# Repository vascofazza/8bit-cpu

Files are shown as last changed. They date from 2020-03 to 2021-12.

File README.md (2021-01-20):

# MK1 8bit Computer

Schematics and code for my home-made 8-bit CPU and its companion boards.

Articles about this project:

[Hackaday.com](https://hackaday.com/2020/12/31/diy-8-bit-computer-knows-all-the-tricks/)

[Hackster.io](https://www.hackster.io/news/see-inside-of-a-cpu-with-the-mk1-8bit-computer-14fa9e313c73)

[InformaticaLab.com](https://blog.informaticalab.com/viaggio-allinterno-di-una-cpu-con-il-mk1-8bit-computer/)

## Overview

During the past month, I designed and built a programmable 8-bit CPU from scratch, out of basic series 74LS logic ICs.

This repository contains pictures, schematics, and code for this project and its companion boards.

* V 1.0 assembled:

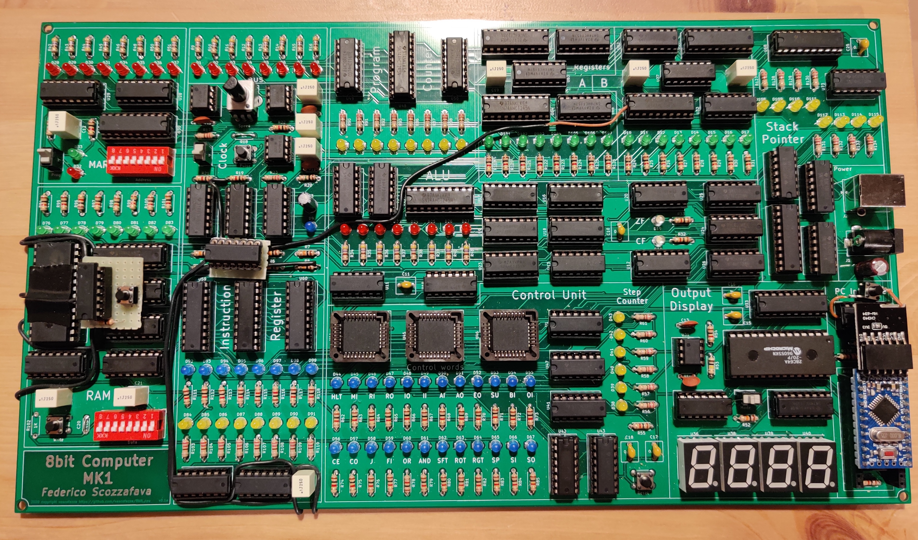
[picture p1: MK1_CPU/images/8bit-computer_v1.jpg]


* V 2.0b assembled:

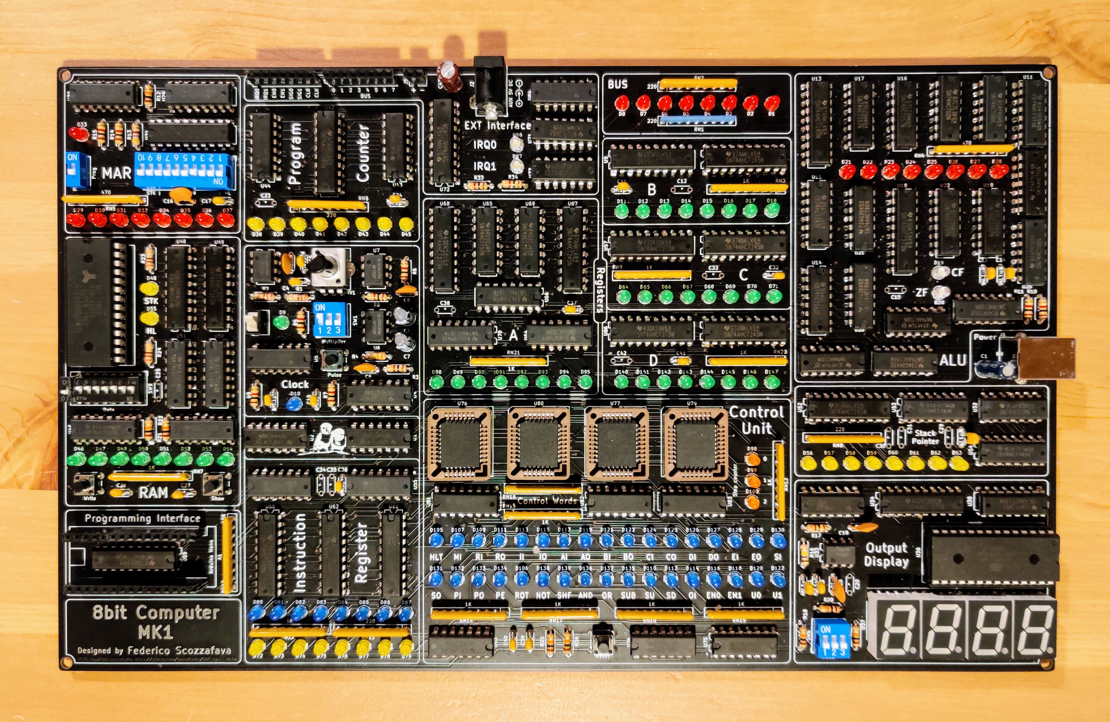
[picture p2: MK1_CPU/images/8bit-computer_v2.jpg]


- Helix Display Interface in action:



* V 1.0 in action:

**DEMO VIDEO (YouTube)**

MK1 Computer - home-made Programmable 8bit CPU (https://www.youtube.com/watch?v=qSviFkpLFKI)

## Architecture

The MK1 CPU is composed of several modules, all connected trough a common 8-bit BUS, the status of each module is shown by dedicated LEDs. 

- The clock module is designed to allow step-by-step execution; in automatic mode the clock speed can be adjusted from 1Hz up to 32KHz.
- The computer programs are stored in RAM and the CPU can be programmed both manually, by inserting binary machine code through dip-switches, and automatically via a USB PC interface. 
  - The Programming interface is designed to be used in conjunction with an **Arduino Nano** or the **Start9** programming board.
  - The **Start9** programming board allows the loading of multiple programs stored on an on-board flash memory without the aid of an external computer device.
- The Addressable memory space is 1024 byte, data, stack and code spaces are separated, the code address space is not writable. 
- The instructions are variable-length (see **instruction-set [here](https://github.com/vascofazza/8bit-cpu/tree/master/MK1_CPU/programs/lib/mk1.cpu)**) 1 or 2 bytes long (first byte for the opcode, the second one for the argument), there are 4 general purpose registers (`A`, `B`, `C`, `D`) and a  `stack pointer` register for subroutine calls.
- The **A**rithmetic **L**ogic **U**nit has a dedicated register for the second operand and supports the following operations:
  - Addition
  - Subtraction
  - OR
  - AND
  - NOT
  - Left/Right Shift
  - Left/Right Rotation
- The Control Unit combinatory logic is implemented using EEPROMs (see **microcode [here](https://github.com/vascofazza/8bit-cpu/blob/master/MK1_CPU/code/microcode.txt)**) whilst each instruction is realized through a variable number of micro-instruction for a maximum of 6 micro-steps per instruction, including the fetch cycle. The instruction-set  supports both direct and indirect memory access as well as absolute and conditional jumps on carry (`CF`) and zero (`ZF`) ALU flags.
- The computation output can be visualized on a 4-digit display, with a dedicated register, able to represent positive and 2-complement negative numbers both in decimal and hexadecimal format.
- The CPU can be extended thanks to the external BUS interface capable of handling up to 2 peripheral. The communication is bidirectional, the devices can send interrupts to the CPU to notify when new data is available. Interrupts are cleared once the data has been processed.
  - The only available peripheral at the moment is the **Helix** display interface, an ATmega328-driven 2x16 LCD output display.

## Structure

- **MK1 CPU/**:
  - **8bit-computer/**: KiCad project, schematics and PCB design of the **MK1 CPU**.
  - **code/**:
    - microcode.py: generates the binary EEPROM microcode.
    - out_display.py: generates the binary output display EEPROM code.
    - uploader.py: uploads a binary MK1 program to the CPU.
    - mk1_computer_uploader/: Arduino programmer interface sketch.
  - **assembler/**: fork of the hlorenzi's assembler, improved and customized for the MK1
  - **programs/**: a collection of programs for the MK1 CPU plus the assembler definition
- **start9_programming_interface/**: 
  - **programming_interface/**: KiCad project, schematics and PCB design of the **Start9** programming board.
  - **code/start9_programming_interface/**: Arduino code for the programming interface.
- **helix_display_interface/**:
  - **display_interface/**: KiCad project, schematics and PCB design of the **Helix** display interface board.
  - **code/helix_display_interface/**: Arduino code for the display interface.
- **eeprom_programmer/**: KiCad project, schematics and PCB design of a simple Arduino-based eeprom programmer
- **bus_breakout/**: KiCad project, schematics and PCB design of the external bus connector breakout board.

## Changelog

##### V2.0d:

- minor hardware revision
- revisited PCB design
- new memory architecture, code memory section is read-only, stack and data live on separated spaces

##### V2.0b:

- minor hardware revision
- Variable-length instructions (1 or 2 bytes)
- new custom assembler, thanks to https://github.com/hlorenzi/customasm
- few new instructions
- revisited microcode and instruction-set

##### V2.0:

- 4 general purposes registers (A, B, C, D)
- Stack Pointer implemented as an up-down counter
- External interface and interrupt handling
- Output display decodes HEX and ASCII values
- Clock speed multipliers
- Control Unit extended with 4 EEPROMs
- Variable step microcode counter length (each instruction uses the minimum amount of micro-steps)
- revisited microcode and instruction-set

##### V1.0:

- Bugfixes.
- `HL` and `STK` address signals available in the `MAR` dip-switch.

##### V0.1:

- Initial release

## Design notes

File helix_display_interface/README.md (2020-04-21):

# Helix Display Interface

An ATmega328-driven LCD Display peripheral for the MK1 8-bit CPU.

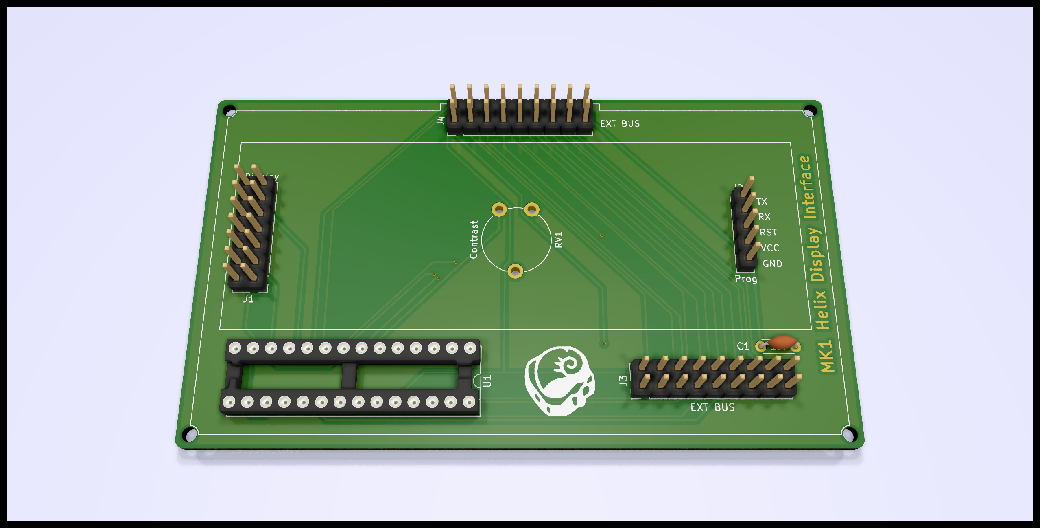
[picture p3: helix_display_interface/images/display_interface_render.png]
pcb_render


## Description

LCD character display interface for the MK1 CPU computer.

Uses an ATmega328P as driver and implements Integer and Character output mode.

Commands and data are both transmitted on the external bus.

There are two external bus connectors for peripheral daisy chaining.

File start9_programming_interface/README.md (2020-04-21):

# Start9 Programming Interface

An ATmega328-driven programming interface for the MK1 8-bit CPU.

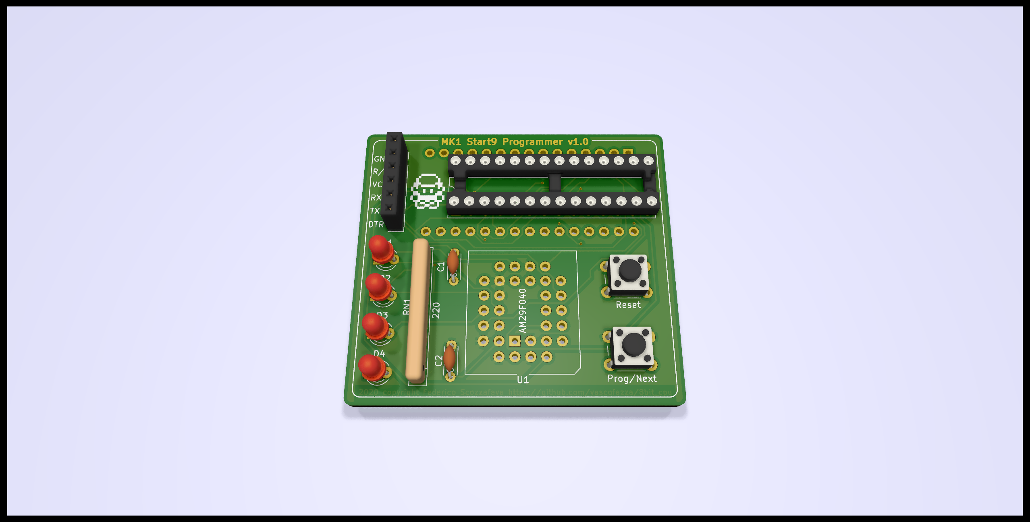
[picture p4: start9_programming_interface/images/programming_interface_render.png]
pcb_render


## Description

Writes a program, stored in a flash memory, into the working memory of the MK1 CPU.

Supports up to 16 program slots, the program/next button is used to select the bank and write the selected program.

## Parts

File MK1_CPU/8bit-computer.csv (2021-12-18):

Comment | Designator | Footprint | LCSC
Arduino Nano | A1 | Module:Arduino_Nano
0.1µF | C5,C10,C11,C12,C14,C15,C18,C22,C23,C25,C28,C29,C30,C34,C36,C37,C40,C41,C42 | Capacitor_THT:C_Disc_D4.3mm_W1.9mm_P5.00mm
* | C13,C16,C21,C26,C31,C32,C33,C35,C38,C43 | Capacitor_THT:C_Disc_D4.3mm_W1.9mm_P5.00mm
0.01 | C17 | Capacitor_THT:C_Disc_D4.3mm_W1.9mm_P5.00mm
10µF | C1,C2 | Capacitor_THT:CP_Radial_D5.0mm_P2.00mm
0.01µf | C24,C27,C44 | Capacitor_THT:C_Disc_D4.3mm_W1.9mm_P5.00mm
0.01µF | C3,C6,C7,C9,C19,C20,C39,C45 | Capacitor_THT:C_Disc_D4.3mm_W1.9mm_P5.00mm
1µF | C4,C8 | Capacitor_THT:CP_Radial_D5.0mm_P2.00mm
BLUE | D10,D72,D73,D74,D75,D76,D77,D78,D79,D93,D94,D95,D96,D97,D98,D99,D100,D101,D102,D103,D104,D105,D106,D107,D108,D109,D110,D111,D112,D113,D114,D115,D116,D117,D118,D119,D120,D121,D122,D123,D124,D125,D126 | LED_THT:LED_D3.0mm
WHITE | D19,D20,D88,D89 | LED_THT:LED_D3.0mm
YELLOW | D38,D39,D40,D41,D42,D43,D44,D45,D48,D55,D56,D57,D58,D59,D60,D61,D62,D63,D90,D91,D92 | LED_THT:LED_D3.0mm
RED | D1,D2,D3,D4,D5,D6,D7,D8,D21,D22,D23,D24,D25,D26,D27,D28,D29,D30,D31,D32,D33,D34,D35,D36,D37 | LED_THT:LED_D3.0mm
GREEN | D9,D11,D12,D13,D14,D15,D16,D17,D18,D46,D47,D49,D50,D51,D52,D53,D54,D64,D65,D66,D67,D68,D69,D70,D71,D80,D81,D82,D83,D84,D85,D86,D87,D127,D128,D129,D130,D131,D132,D133,D134 | LED_THT:LED_D3.0mm
USB_B-8bit-computer-rescue | J1 | Connector_USB:USB_B_OST_USB-B1HSxx_Horizontal
Barrel_Jack_Switch | J2 | Connector_BarrelJack:BarrelJack_Horizontal
EXT-CONN | J4 | Connector_PinHeader_2.54mm:PinHeader_2x09_P2.54mm_Vertical
Arduino_VIN | JP1 | Jumper:SolderJumper-2_P1.3mm_Bridged_RoundedPad1.0x1.5mm
220 | R1,R2,R23,R24 | Resistor_THT:R_Axial_DIN0207_L6.3mm_D2.5mm_P7.62mm_Horizontal
10K | R12,R18,R19,R20,R21,R22,R29,R30,R31,R32 | Resistor_THT:R_Axial_DIN0207_L6.3mm_D2.5mm_P7.62mm_Horizontal
470 | R13 | Resistor_THT:R_Axial_DIN0207_L6.3mm_D2.5mm_P7.62mm_Horizontal
100K | R16 | Resistor_THT:R_Axial_DIN0207_L6.3mm_D2.5mm_P7.62mm_Horizontal
1K | R3,R5,R6,R7,R8,R9,R10,R11,R14,R15,R17,R25,R26,R27,R28 | Resistor_THT:R_Axial_DIN0207_L6.3mm_D2.5mm_P7.62mm_Horizontal
330K | R4 | Resistor_THT:R_Axial_DIN0207_L6.3mm_D2.5mm_P7.62mm_Horizontal
10K | RN1 | Resistor_THT:R_Array_SIP9
470 | RN2,RN4,RN5 | Resistor_THT:R_Array_SIP9
1K | RN3,RN7,RN9,RN10,RN11,RN12,RN13,RN14,RN15,RN16,RN17,RN18,RN19,RN20 | Resistor_THT:R_Array_SIP9
220 | RN6,RN8 | Resistor_THT:R_Array_SIP9
1M | RV1 | Potentiometer_THT:Potentiometer_Bourns_PTV09A-1_Single_Vertical
Multiplier | SW1 | Button_Switch_THT:SW_DIP_SPSTx03_Slide_9.78x9.8mm_W7.62mm_P2.54mm
Reset | SW10 | Button_Switch_THT:SW_PUSH_6mm_H5mm
Pulse | SW2 | Button_Switch_THT:SW_PUSH_6mm_H5mm
Manual | SW3 | Button_Switch_THT:SW_NKK_GW12LJP
Prog | SW4 | Button_Switch_THT:SW_DIP_SPSTx01_Slide_9.78x4.72mm_W7.62mm_P2.54mm
Address | SW5 | Button_Switch_THT:SW_DIP_SPSTx10_Slide_9.78x27.58mm_W7.62mm_P2.54mm
Mode | SW6 | Button_Switch_THT:SW_DIP_SPSTx03_Slide_9.78x9.8mm_W7.62mm_P2.54mm
Write | SW7 | Button_Switch_THT:SW_PUSH_6mm_H5mm
Show | SW8 | Button_Switch_THT:SW_PUSH_6mm_H5mm
Data | SW9 | Button_Switch_THT:SW_DIP_SPSTx08_Slide_9.78x22.5mm_W7.62mm_P2.54mm
CLK_IN | TP1 | TestPoint:TestPoint_Pad_1.0x1.0mm
AND | TP10 | TestPoint:TestPoint_Pad_1.0x1.0mm
EI | TP11 | TestPoint:TestPoint_Pad_1.0x1.0mm
~EO | TP12 | TestPoint:TestPoint_Pad_1.0x1.0mm
NOT | TP13 | TestPoint:TestPoint_Pad_1.0x1.0mm
SUB | TP14 | TestPoint:TestPoint_Pad_1.0x1.0mm
MI | TP15 | TestPoint:TestPoint_Pad_1.0x1.0mm
OI | TP16 | TestPoint:TestPoint_Pad_1.0x1.0mm
~PO | TP17 | TestPoint:TestPoint_Pad_1.0x1.0mm
PE | TP18 | TestPoint:TestPoint_Pad_1.0x1.0mm
~PI | TP19 | TestPoint:TestPoint_Pad_1.0x1.0mm
CLK | TP2 | TestPoint:TestPoint_Pad_1.0x1.0mm
~RO | TP20 | TestPoint:TestPoint_Pad_1.0x1.0mm
RI | TP21 | TestPoint:TestPoint_Pad_1.0x1.0mm
~SO | TP22 | TestPoint:TestPoint_Pad_1.0x1.0mm
SU | TP23 | TestPoint:TestPoint_Pad_1.0x1.0mm
SD | TP24 | TestPoint:TestPoint_Pad_1.0x1.0mm
SI | TP25 | TestPoint:TestPoint_Pad_1.0x1.0mm
II | TP28 | TestPoint:TestPoint_Pad_1.0x1.0mm
AI | TP29 | TestPoint:TestPoint_Pad_1.0x1.0mm
~CLK | TP3 | TestPoint:TestPoint_Pad_1.0x1.0mm
~AO | TP30 | TestPoint:TestPoint_Pad_1.0x1.0mm
RGT | TP31 | TestPoint:TestPoint_Pad_1.0x1.0mm
ROT | TP32 | TestPoint:TestPoint_Pad_1.0x1.0mm
SHF | TP33 | TestPoint:TestPoint_Pad_1.0x1.0mm
E0 | TP34 | TestPoint:TestPoint_Pad_1.0x1.0mm
EXT_IN | TP35 | TestPoint:TestPoint_Pad_1.0x1.0mm
E1 | TP36 | TestPoint:TestPoint_Pad_1.0x1.0mm
U0 | TP37 | TestPoint:TestPoint_Pad_1.0x1.0mm
U1 | TP38 | TestPoint:TestPoint_Pad_1.0x1.0mm
~CU_EN | TP39 | TestPoint:TestPoint_Pad_1.0x1.0mm
~REG-O | TP4,TP26,TP40 | TestPoint:TestPoint_Pad_1.0x1.0mm
REG-I | TP5,TP27,TP41 | TestPoint:TestPoint_Pad_1.0x1.0mm
~FI | TP6 | TestPoint:TestPoint_Pad_1.0x1.0mm
ZF | TP7 | TestPoint:TestPoint_Pad_1.0x1.0mm
CF | TP8 | TestPoint:TestPoint_Pad_1.0x1.0mm
OR | TP9 | TestPoint:TestPoint_Pad_1.0x1.0mm
74HCT32 | U1,U2,U12,U25,U28 | Package_DIP:DIP-14_W7.62mm
74HCT173 | U11 | Package_DIP:DIP-16_W7.62mm
74HCT02 | U13,U69 | Package_DIP:DIP-14_W7.62mm
74HCT283 | U15,U16 | Package_DIP:DIP-16_W7.62mm
74HCT157 | U17,U18,U20,U23,U45,U62,U63,U67,U68 | Package_DIP:DIP-16_W7.62mm
74HCT86 | U21,U22,U24 | Package_DIP:DIP-14_W7.62mm
NE555 | U3,U6,U7,U33 | Package_DIP:DIP-8_W7.62mm
74LS157 | U30,U31,U50,U51 | Package_DIP:DIP-16_W7.62mm
74HCT107 | U35,U71 | Package_DIP:DIP-14_W7.62mm
28C64 | U36 | Package_DIP:DIP-28_W15.24mm_Socket
74HCT139 | U38 | Package_DIP:DIP-16_W7.62mm
74HCT04 | U4,U60 | Package_DIP:DIP-14_W7.62mm
7SEGMENT_CC | U37,U39,U40,U41 | Display_7Segment:7SegmentLED_LTS6760_LTS6780
74HCT161 | U43,U44,U72 | Package_DIP:DIP-16_W7.62mm
74HCT00 | U46,U55 | Package_DIP:DIP-14_W7.62mm
CY62256 | U47 | Package_DIP:DIP-28_W15.24mm_Socket
74HCT08 | U5,U10,U26,U27,U29,U58,U64 | Package_DIP:DIP-14_W7.62mm
74HCT193 | U53,U54 | Package_DIP:DIP-16_W7.62mm
AM29F040 | U73,U74,U75,U76 | Housings_LCC:PLCC-32_THT-Socket
74HCT138 | U77 | Package_DIP:DIP-16_W7.62mm
74HCT238 | U78,U79 | Package_DIP:DIP-16_W7.62mm
74HCT245 | U8,U14,U42,U48,U49,U52,U56,U59,U65,U70,U80 | Package_DIP:DIP-20_W7.62mm
74HCT273 | U9,U19,U32,U34,U57,U61,U66,U81 | Package_DIP:DIP-20_W7.62mm

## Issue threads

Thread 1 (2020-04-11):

Question: How did you get this manufactured?

efreethy, 2020-04-11:

vascofazza, 2020-04-11:
There are several PCB manufacturer companies, in my case I have a friend with all the necessary tools that manufactured it for me.

Closed 2020-04-12.

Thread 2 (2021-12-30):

Version control w/ example code and customasm syntax

HeathenUK, 2021-12-30:
Hi there,

As best I can tell there seem to have been some hugely backward-incompatible changes to customasm since the original (very well written!) examples were uploaded. I've tried and failed to port the definitions to the current expectations of customasm and failed, probably in equal parts due to my unfamiliarity with both customasm and the mk1's instructions. It's a pity, I was looking forward to making a pull request!

There seems to have been a shift away from 'cpudef' and 'tokendef' (although it looks like the parser still honours both so this is the least of all issues), the bankdef syntax no longer allows/requires quotation marks but even once that's fixed it throws panics due to the overlap in the two banks' respective locations. The thing I've totally failed to understand the root of - as your syntax looks identical to Lorenzi's to my eye - is casm's dislike of the way your registers and ALU opcodes are set out, and to every reference thereafter containing a $ sign.

Finally and somewhat bizarrely I can't even seem to find a historical build from ~2019 that likes the example code, so I'm not sure what's going on there either.

Regards,

Greg

vascofazza, 2022-01-02:
Hi Greg,

A PR would be more than welcome!
As you might have noticed, the version I used to build the example is a submodule of the repo, you can find it here: https://github.com/vascofazza/customasm/tree/0ab3ff3c4961ad814b904fe4824a65ae8b251672
You can also find the microcode here https://github.com/vascofazza/8bit-cpu/blob/master/MK1_CPU/code/microcode.txt
Where you can easily see what that 3'5 stands for and that should help you with the port.

Keep me posted!

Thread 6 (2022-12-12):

Problems with `ldi reg,0`

sparr, 2022-12-12:
I should preface this by saying that I haven't built your computer yet, but I want to, either in a simulator or on breadboards, and I prefer to dive into the repository and code before getting physical. So, I'm sorry if some (or, hopefully not, all) of my "will" and "should" below are inaccurate or off base.

`ldi {dst: reg} 0 => 0b11 @ 0b01 @ 0b00 @ dst[1:0]`

This seems to convert `ldi $a, 0` into `0b11 01 00 00` which microcode.txt tells me is equivalent to `sub $a, $a` instead of the `move 0, $a` that I would otherwise expect. While that instruction will produce the clearly desired effect of putting 0 into the a register, I think there are a few problems with this:

1. `sub` sets flags while `move` does not. That means `ldi $a, 0` will set the zero flag, but `ldi $a, 1` will not clear the zero flag. As a programmer, this is not behavior I would expect or desire.
2. `ldi $b, 0` is converted to `0b11 01 00 01` which is `sub $a, $b`. Should the third crumb `0b00` here be another `dst[1:0]` instead so that this will produce `0b11 01 01 01` or `sub $b, $b`?
3.  Both `sub reg, reg` and `move imm, reg` take 4 steps, so this optimization doesn't seem to gain anything, and it costs a bit of extra power for activating a lot more flags.
4. `dst[1:0]` truncates the dst parameter to 2 bits, so `ldi $sp, 0` is accepted by the assembler and produces identical machine code to `ldi $a, 0`, and ditto for `$pc`/`$b` and `$out`/`$c`. This line should include `{ assert(reg <= 4) ... }` or equivalent.
5. No example programs use this pattern for any register other than a. The test suite program doesn't use it at all. Every separate line in the assembler definition probably deserves at lease one test case.

I hope at least some of this makes sense and is helpful.

vascofazza, 2022-12-14:
I did not check carefully but I guess you are right about the flag being set due to `ldi $a 0` because of its implementation through the `sub` opcode.

There is actually a good reason why this is implemented this way. Therefore, I would say this is a design choice; the ALU flags should be considered valid only after a cmp or sub operation.
You could still reserve a whole set of opcodes for that operation and "solve" the issue this way.

1. That might indeed be true. I did not check the exact behavior anyway. refer to what is being said above.
2. The instructions are correct. All ALU ops first operand is always `$a`, therefore the syntax is `sub $a $x $dest` -> for any register the operation results in `$a - $a -> $dest`.
3. This is not actually true. `sub reg reg` is a 1-byte instruction, `move imm reg` is a 2-byte instruction, therefore it requires an extra fetch cycle to complete.
4. Again, I didn't check the details, this sounds a bit awkward. The microcode has all the possible combinations, in case there's an error feel free to open a PR :) The assertion seems safe. https://github.com/vascofazza/8bit-cpu/blob/master/MK1_CPU/code/microcode.txt
5. The original testing program was more exhaustive, I had to reduce it to make it fit in memory. A second test suite would make sense.

I hope this helps :)

sparr, 2022-12-14:
1. Thanks for the clarification. I suspect if I was going to continue less-fork-edly from your design I'd try to contribute a bit of documentation for that sort of thing. As it is I might not stay close enough for it to be relevant, but if I do then I will.
2. That makes perfect sense, and I suspect I'd have figured it out when I built the ALU to play with.
3. I completely forgot about the extra fetch cycle.
4. I found a better way than an assertion. I'll PR something like this after #5 is merged:

```customasm
#subruledef reg_gp
{
    $a   => 0
    $b   => 1
    $c   => 2
    $d   => 3
}

#subruledef reg_all
{
    {dst: reg_gp} => dst
    $sp  => 4
    $pc  => 5
    $out => 6
}
```

5. If I stay even close to instruction compatible with yours, I'll try to PR more tests.

I'll go ahead and close this since the major concerns aren't valid, and the fix for item 4 is going to touch a lot more than just this instruction anyway.

PS: I have a very unrealistic new concern... Implementing `ldi 0` differently from other `ldi imm` could expose cryptographic implementations on the cpu to timing attacks :)

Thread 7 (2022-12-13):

Opcodes that can be repurposed

sparr, 2022-12-13:
This is not a bug and not yet a feature request, more intended as discussion and preparation for expansion if the author or any other folks looking at this project want to collaborate on this part.

The existing code already fits `exr`, `exw`, `j*`, `cmp`, `not`, `sll`, `slr`, `rll`, `rlr`, `hlt`, and `add/sub/or/and imm` into some of the gaps where the larger opcode patterns would be meaningless or close. I am looking at the instruction set and opcode list and considering where more instructions can be squeezed in. Akin to my previous post, I apologize in advance if I've gotten anything wrong. I've started putting together the parts list to build a version of this computer, but it's going to be a while before I have hardware to play on.

Here are my notes:

`load $x [$out]` is already repurposed for `$a` and `$b`. The other 5 destination registers are ripe for the taking, at no cost.

`move $x $x` is a nop. It's so nop that `nop` maps to `move $a $a`, and so could all of them. Since `move imm, imm` is already reclaimed and we need to keep one to cover all of them, this would open up 6 opcodes at no cost.

`and/or $x $x` sets zf if $x is 0, clears cf. I think that `add 0 $x` would do the same, at the cost of 1 step. This would open up 8 opcodes.

`stor $x, [$pc]` is a quandary. The readme for the project says program memory (`HL`, bytes 0x100 to 0x1FF, I think?) isn't writable, but I don't see that implemented in the current schematic. If it works, it could only write to the next instruction to be executed, which seems of very limited use. I suspect this can be given up to gain 4 more opcodes.

`load $x, [$pc]` seems only slightly more useful. Reading only the next instruction from program memory might enable some specific clever trick, but I don't see it. I'd also give this up for 4 more opcodes.

`sub $x $x` sets $x to 0, sets zf, clears cf. I think that `cmp $x; ldi $x 0` does the same for `$b`/`$c`/`$d`, and `ldi $a 0; cmp 0` for `$a`, at the expense of one byte of code and 3 clock cycles. This would open up 3-4 opcodes.

That's about 20-30 opcodes available for additional instructions depending on priorities. I have ideas for what to do with them, but that's probably a subject for another discussion. Whether there's agreement or not on what to do with them, it would be useful to have some agreement on *which* existing opcodes to repurpose, for maximum compatibility between programs in the future. My preference would be to start at the top of this list.

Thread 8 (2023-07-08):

Helix Display LCD

TnnsBeast, 2023-07-08:
Could you provide the name of the LCD Display used with the Helix Display Interface? I am struggling to find one with the correct pin layout.

vascofazza, 2023-07-09:
Hi @TnnsBeast that is just a regular 16x2 LCD display with the Hitachi driver. The pinout layout is not the most common one but that's the only thing I had laying around.
You can find the pinout in the schematics
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
And the display is something similar to this, at least the pinout is the same https://www.digikey.com/en/products/detail/newhaven-display-intl/NHD-0216BZ-FL-YBW/1701195.
https://newhavendisplay.com/content/specs/NHD-0216BZ-FL-YBW.pdf

The easiest thing you can do is probably build an adapter between the two pin layouts, they are exactly the same except for the arrangement.
I just found the schematics here: https://www.cpmspectrepi.uk/raspberry_pi/MoinMoinExport/VariousDisplays.html

TnnsBeast, 2023-07-16:
Great, thank you!

Closed 2023-07-16.

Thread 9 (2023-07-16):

* on PCB Layout

TnnsBeast, 2023-07-16:
I am currently building the 2.0d, and I see some * on the PCB layout and BOM. What are these supposed to be?
Thanks!

vascofazza, 2023-07-20:
Those are optional (placeholder) 0.1uf caps I put there to compensate for possible impedance issues.
If you see instabilities or crosstalk you might consider putting a cap in there.

Closed 2023-07-20.

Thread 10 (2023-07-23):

Programming Interface

TnnsBeast, 2023-07-23:
Could you please explain how to program the programming interface? I am a little confused as to what the arduino code start9_programming_interface.ino and the flash_composer are meant to do. Also, how does flash composer communicate with the a pc? Sorry for so many questions, I am just trying to follow the build and need a little assistance. Thank you!

vascofazza, 2023-07-23:
The programming interface is used to program the MK1 using the `start9_programming_interface` board or directly from the computer through an Arduino serial interface.

1) The purpose of the Start9 programming interface is to store programs ad load them without having a computer laying around. On the board, an ATmega chip reads the programs from an EEPROM and loads them onto the CPU RAM.
The way this works is the following: first, you upload the `start9_programming_interface.ino` onto the atmega, then you use the `flash_composer` to create a single binary file that contains all the programs you want to store onto the programming interface.
This is an example:
- List of programs: https://github.com/vascofazza/8bit-cpu/blob/master/start9_programming_interface/code/start9.txt
- Output binary: https://github.com/vascofazza/8bit-cpu/blob/master/start9_programming_interface/code/start9.bin
Finally, flash the binary file on the EEPROM and enjoy :)

2) If you want to program the CPU from your computer directly, you only need an Arduino NANO, and this is the code you need to upload https://github.com/vascofazza/8bit-cpu/blob/master/MK1_CPU/code/mk1_computer_uplodader/mk1_computer_uplodader.ino
This way, you can upload the code through the serial port - Everything is already implemented in the `code` folder, you should find the uploader there.

I hope this is making things a little bit clearer :)

TnnsBeast, 2023-07-23:
Yes, this definitely makes sense. The main questions I have are how do you upload the start9_programming_interface.ino onto the atmega, and how do you flash the eeproms (the one on the programmer and the ones on control unit)? I have built the EEPROM Programmer, but from what I understand that is only able to write to the EEPROM used for the output display.

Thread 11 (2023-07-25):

Programming AM29F040

TnnsBeast, 2023-07-25:
Hi there, how did you go about programming the AM29F040 flash memory? I have built the eeprom programmer but from what I can tell that is setup to program the EEPROM handling the 7 segment leds. I am unable to find a good example of how to program the AM29F040 online. Your help is greatly appreciated!

TnnsBeast, 2023-08-05:
Hi, I have successfully built the eeprom programmer board and programmed the 7 segment driver. I am still struggling with the AM29F040 flash chips. I have spent many hours trying to build a programmer for it, but have not been successful. Could you please tell me how you program the AM29F040 chips which are used for control logic and programming interface. Without that I am unable to get this project working, and would really appreciate your help.

vascofazza, 2023-08-06:
@TnnsBeast I used a programmer.
You can try this one off https://github.com/warber0x/FMPUNO
Let me know!

Closed 2023-08-11.

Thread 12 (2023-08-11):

Unexpected Behavior (Clock, Reset, Programming Interface)

TnnsBeast, 2023-08-11:
Hi! I believe I have been able to successfully program the Flash as well as the ATMega for the programming interface, but I am unable to understand why I am getting the results I am currently. Here is a video of what I have so far: https://imgur.com/a/B3an2lI

As you can see in the video, one of the first issues is that the clock doesn't seem to work. When I try to switch it on, nothing seems to happen. The pulse button does work (sometimes).

The next issue is that the reset button for some reason doesn't clear the C register.

And finally, the programming interface doesn't do anything (from what I can tell), since none of the LEDs are lighting up indicating it is programming.

Do you think that these issues could all be caused by incorrect programming of the AM29F040Bs? I was able to use the FMPUno and it seemed that they were programmed correctly when I read the contents.

vascofazza, 2023-08-11:
Remove the programming interface and check the connections. Something is
shorting. Maybe once IC is mounted in reverse . The clock should always
work and the reset as well!

Il giorno ven 11 ago 2023 alle 18:13 Neil Chulani ***@***.***>
ha scritto:

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

vascofazza, 2023-08-11:
The eeproms could cause the issue as well but check the other ics first.

Il giorno ven 11 ago 2023 alle 23:20 Federico Scozzafava <
***@***.***> ha scritto:

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

TnnsBeast, 2023-08-12:
Thank you for your reply. I have checked all of the ICs and they seem to be the correct way, and I am fairly confident that my soldering is also clean. The only thing that I think could possibly be wrong is the direction of the switch used to turn the clock on/off, but even that I am fairly certain is the correct direction.

I will take a look into the eeproms, but do you think the eeproms could really be the reason for malfunctioning clock? I also agree that clock should be working no matter what, which is why I am confused.

Thank you again for your help.

vascofazza, 2023-08-12:
The clock can be disabled by the eeprom through the halt signal.
The behavior of the B register is quite strange and makes me think about
something mounted in reverse. Given that I don’t see anything on the bus
maybe the register is faulty.
Or even the eeproms are outputting random noise.
Anyway, you cannot test the computer without the eeproms because the
signals would be fluctuating.

Il giorno sab 12 ago 2023 alle 08:15 Neil Chulani ***@***.***>
ha scritto:

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

vascofazza, 2023-08-12:
The programming interface also messes up with the signals, so make sure you
remove it for now.

Il giorno sab 12 ago 2023 alle 13:19 Federico Scozzafava <
***@***.***> ha scritto:

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

TnnsBeast, 2023-08-14:
I am fairly sure that it had to do with the eeproms. Many of the control logic leds seem to be fluctuating and I am still unable to get the clock to work even with replacing all of the ICs. Could you please share the name of the programmer that you used, or perhaps recommend an official programmer?

vascofazza, 2023-08-14:
You’re probably right!
I used a random old programmer I had lying around. Any will do.
If you want to make the investment I suggest you to get the TL866 minipro

Il giorno lun 14 ago 2023 alle 20:09 Neil Chulani ***@***.***>
ha scritto:

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

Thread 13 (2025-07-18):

Instruction register in (II) problem

mafrmt00, 2025-07-18:
I really had fun building this project, thank you a lot for that!
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

While testing I came upon the following problem: The instruction register copies every value that comes from memory. If a pop is used, the value goes to the instruction register e.g. It does not matter if II is set.

It seems that my Flash (AM29J040B-90JD) has a very short undefined state on it's data pins while the address changes.

A 10nF capacitor between II and GND solves the problem at most speed settings.

To you have a suggestion for a specific flash type that does not show this behaviour?

Regards
Manfred

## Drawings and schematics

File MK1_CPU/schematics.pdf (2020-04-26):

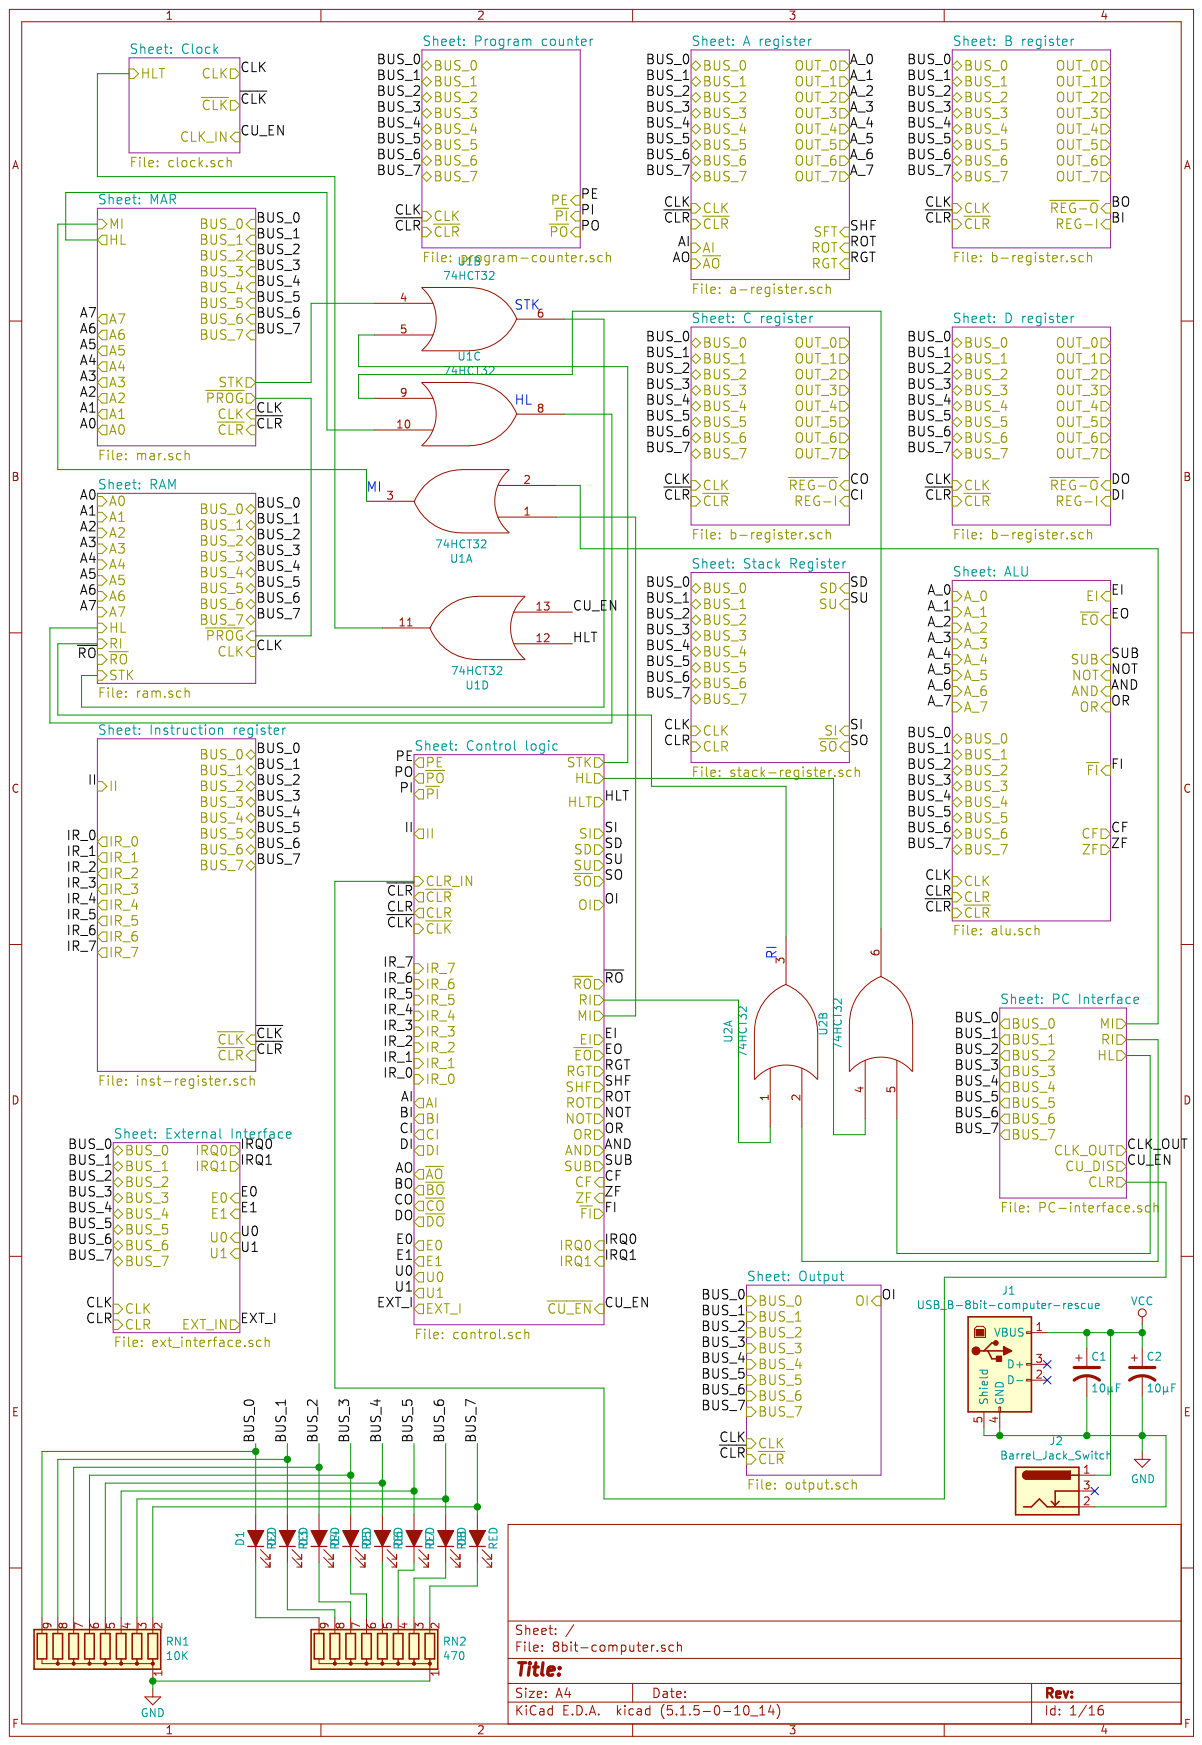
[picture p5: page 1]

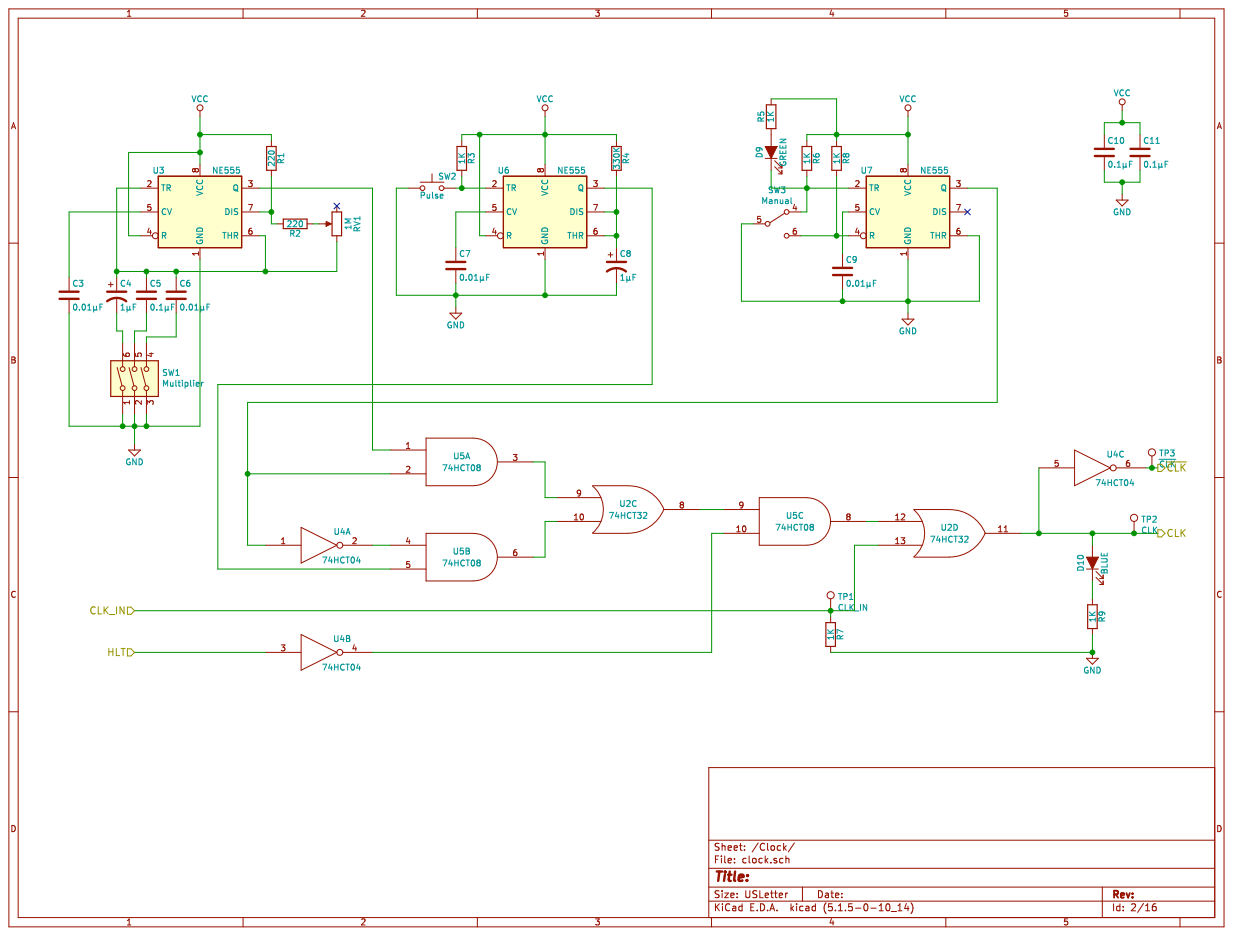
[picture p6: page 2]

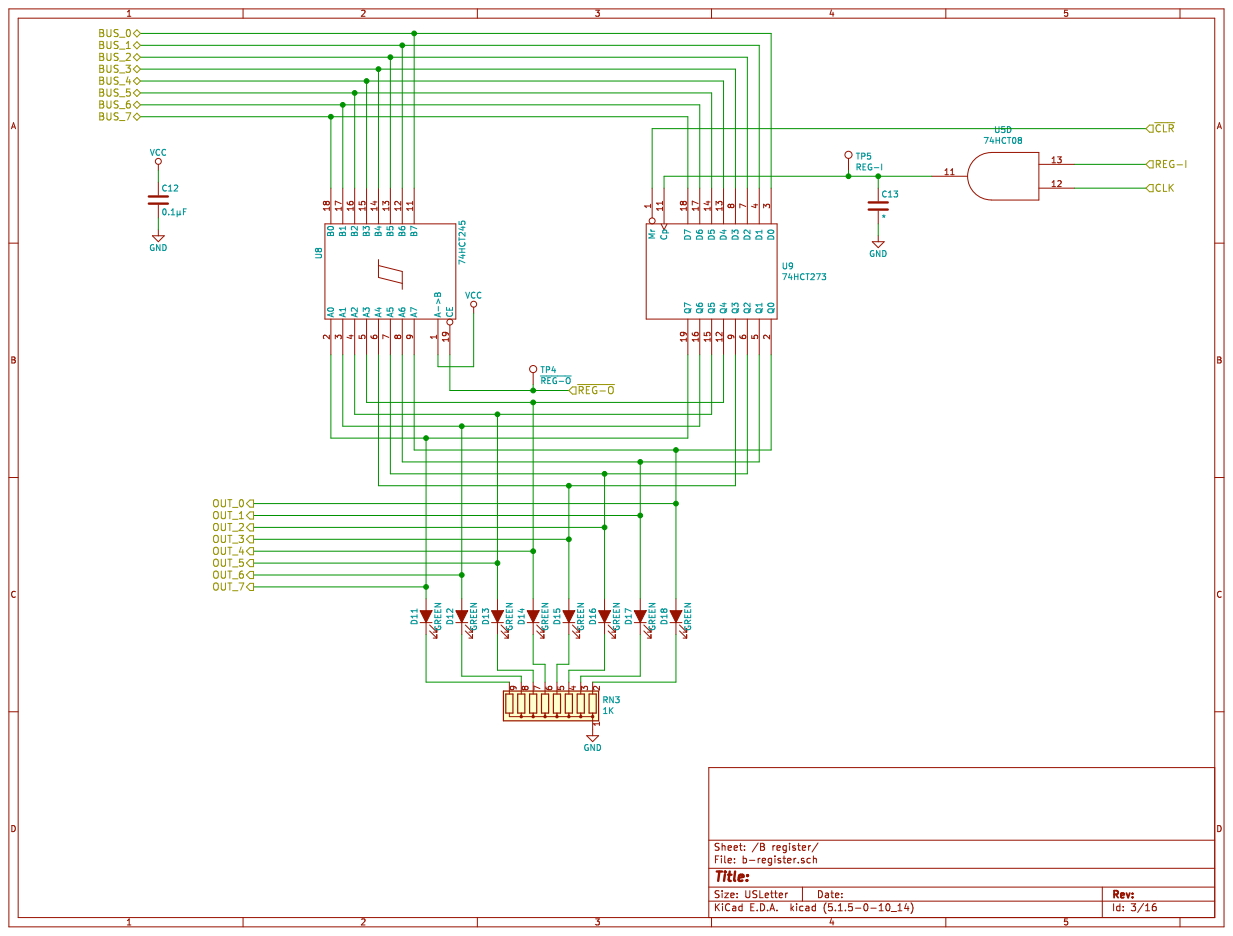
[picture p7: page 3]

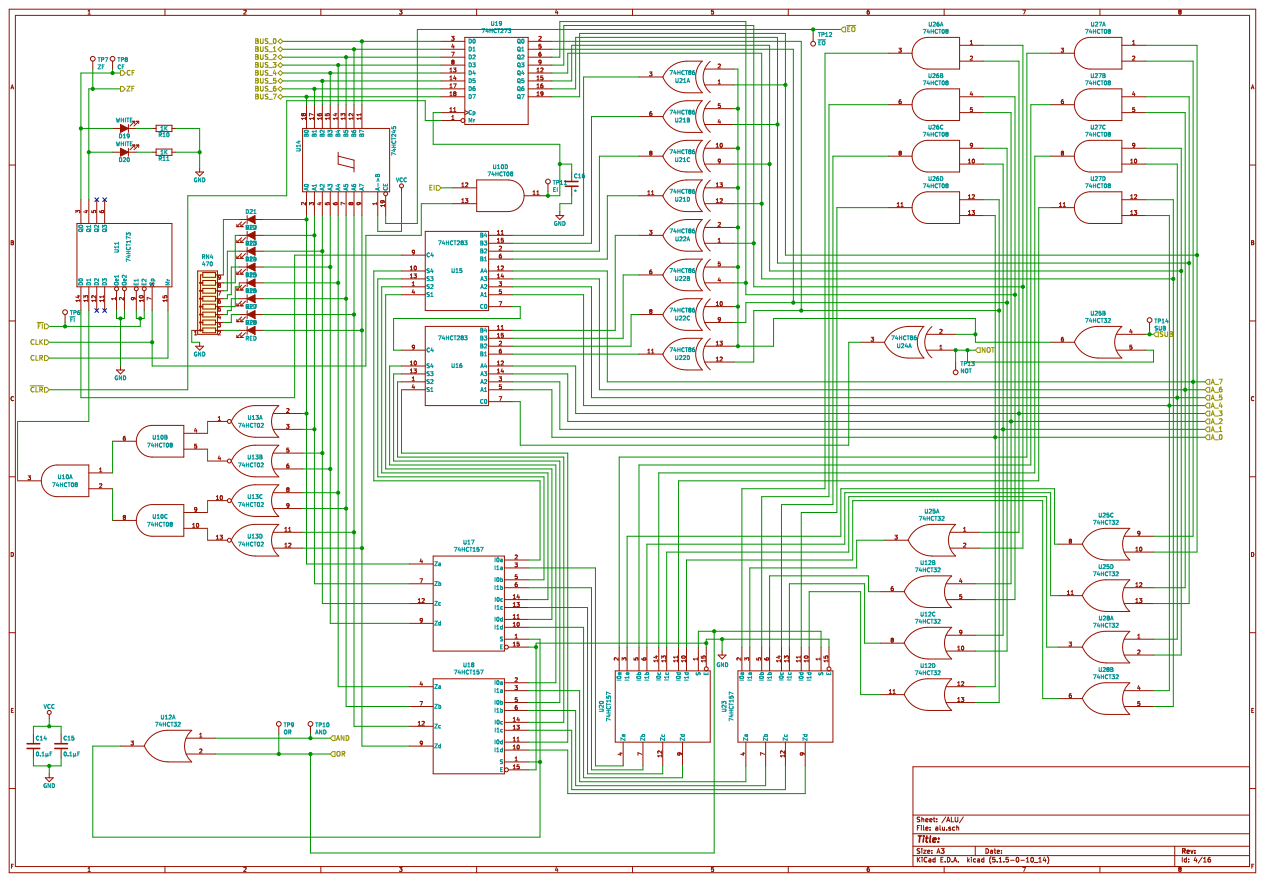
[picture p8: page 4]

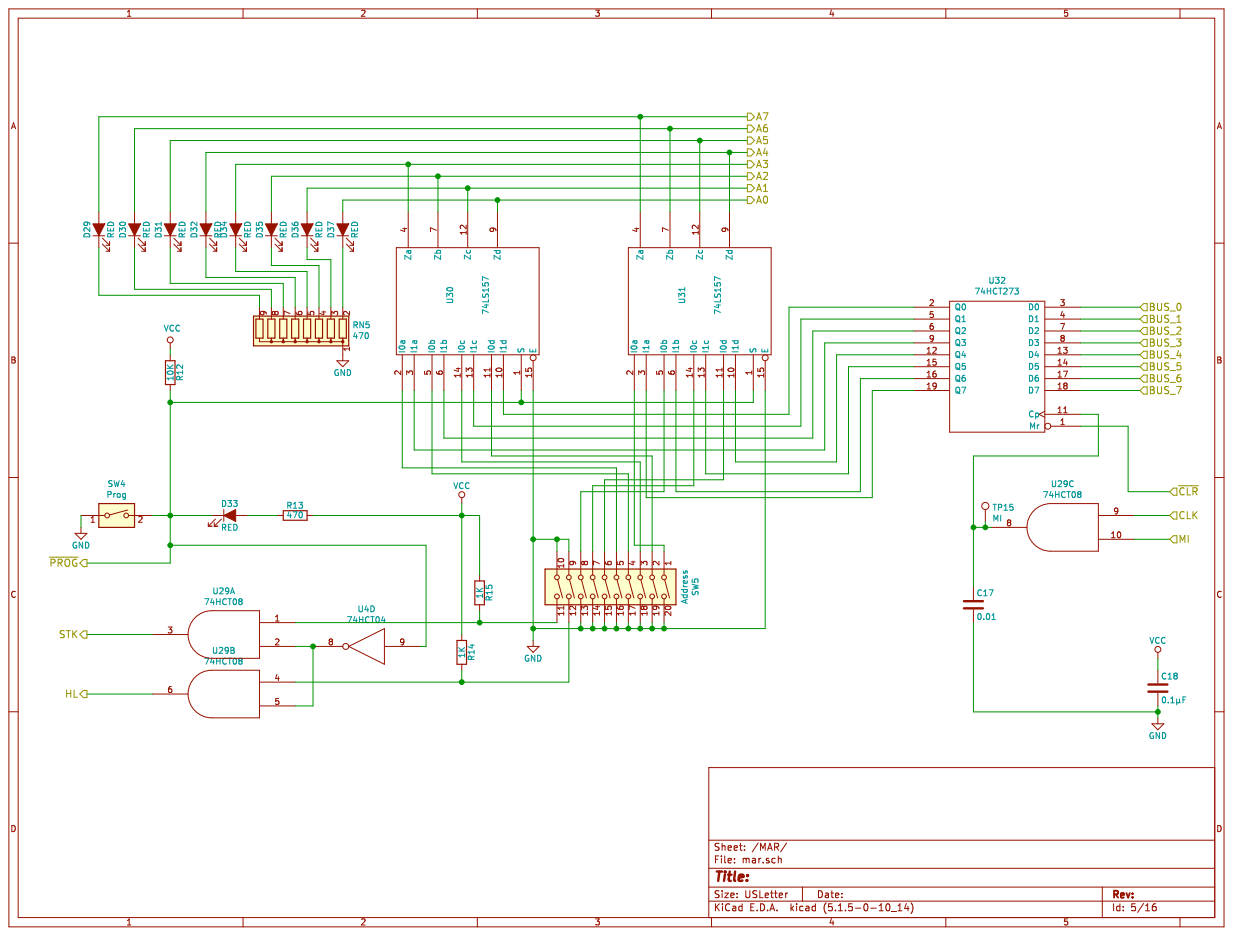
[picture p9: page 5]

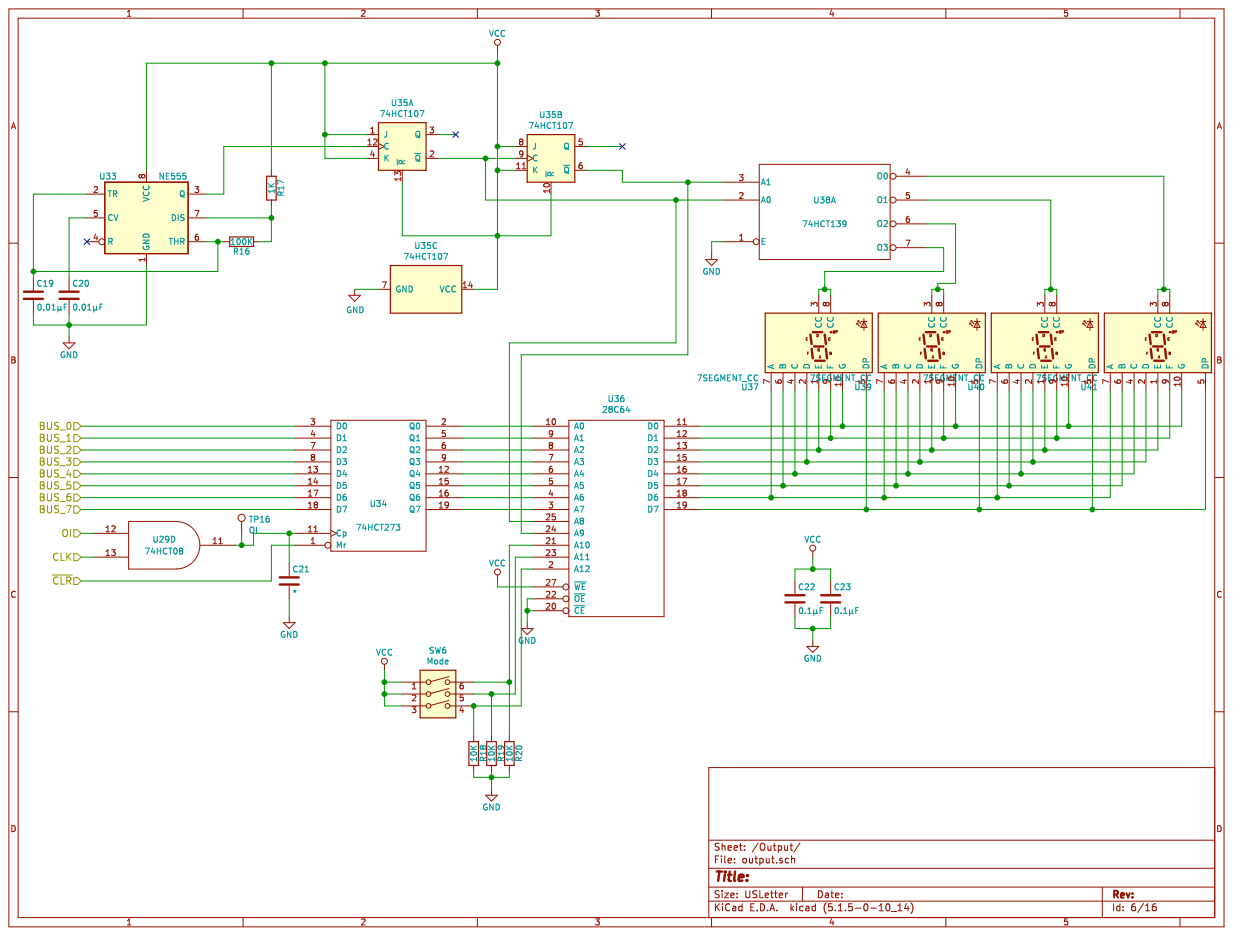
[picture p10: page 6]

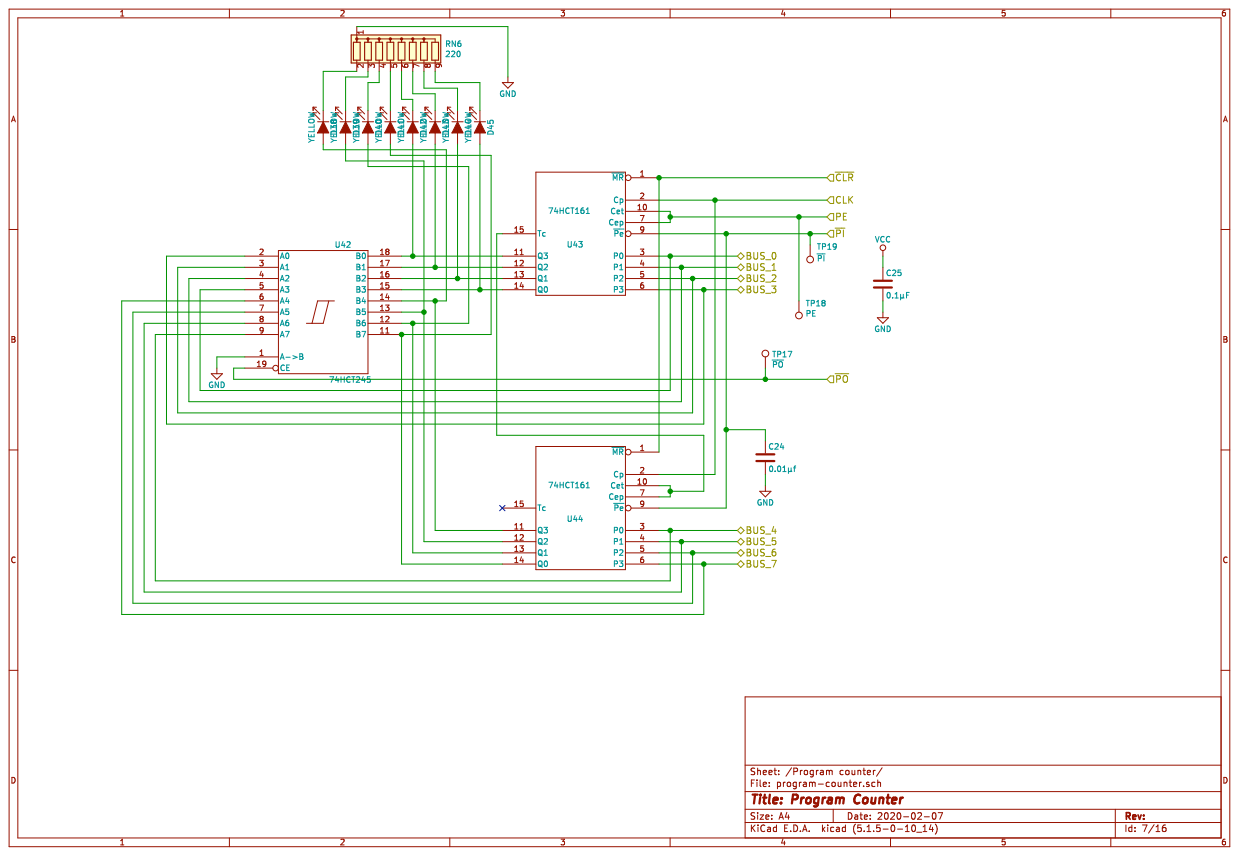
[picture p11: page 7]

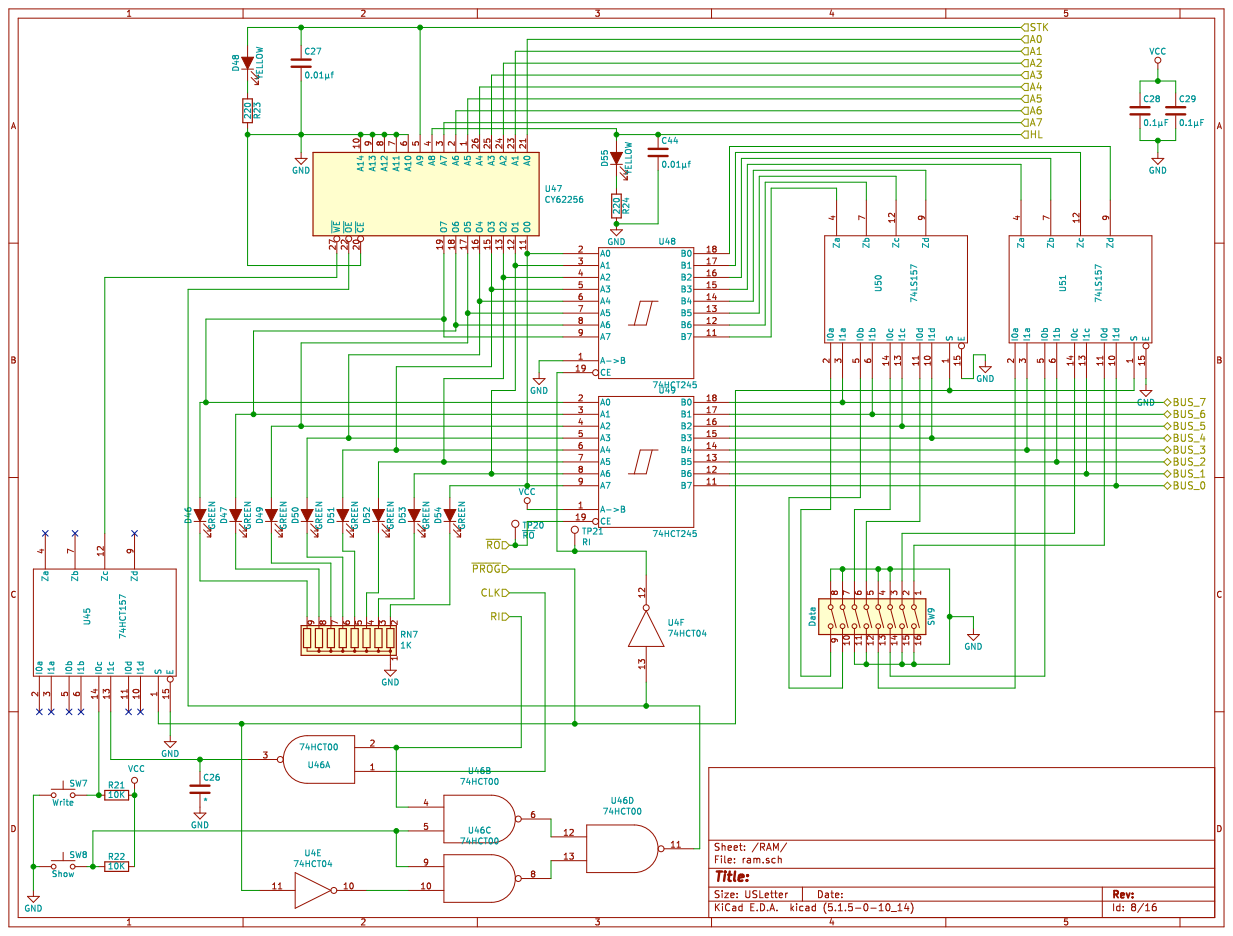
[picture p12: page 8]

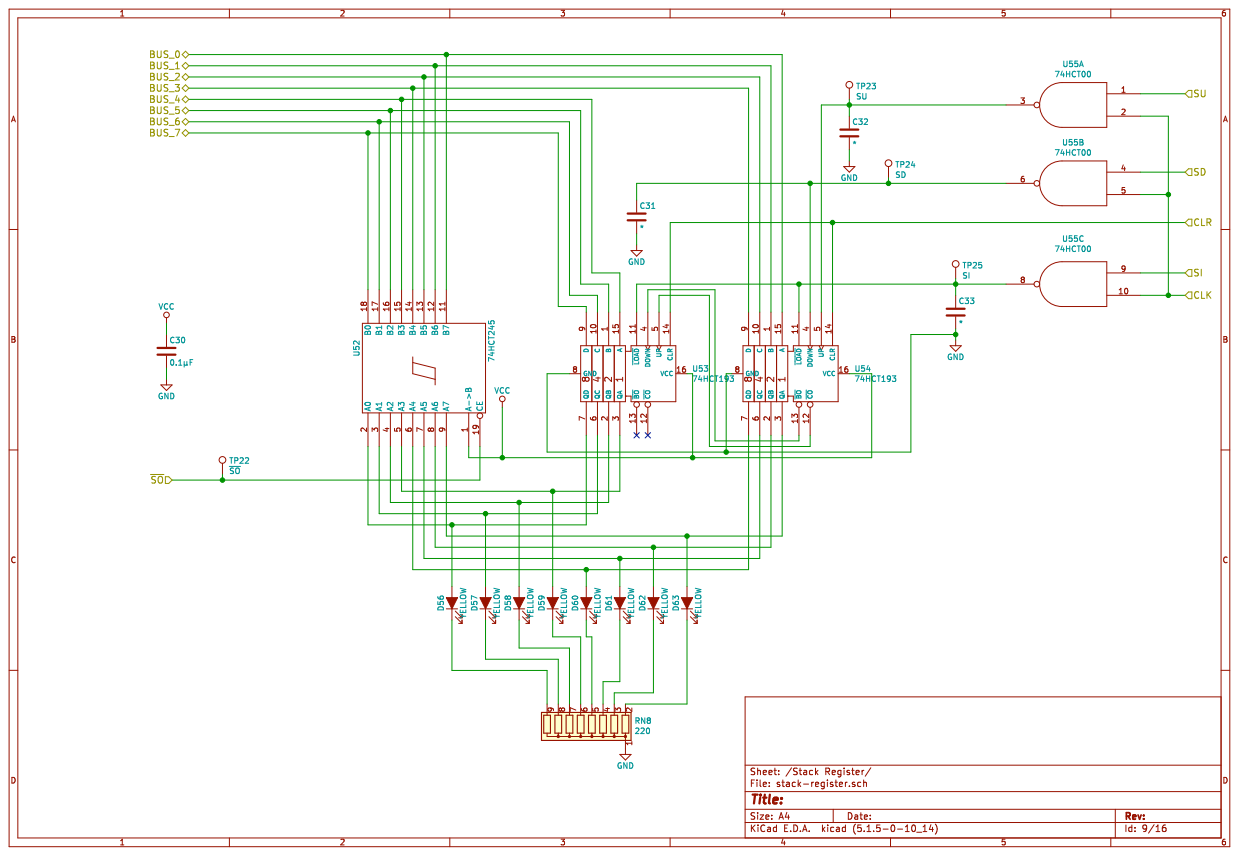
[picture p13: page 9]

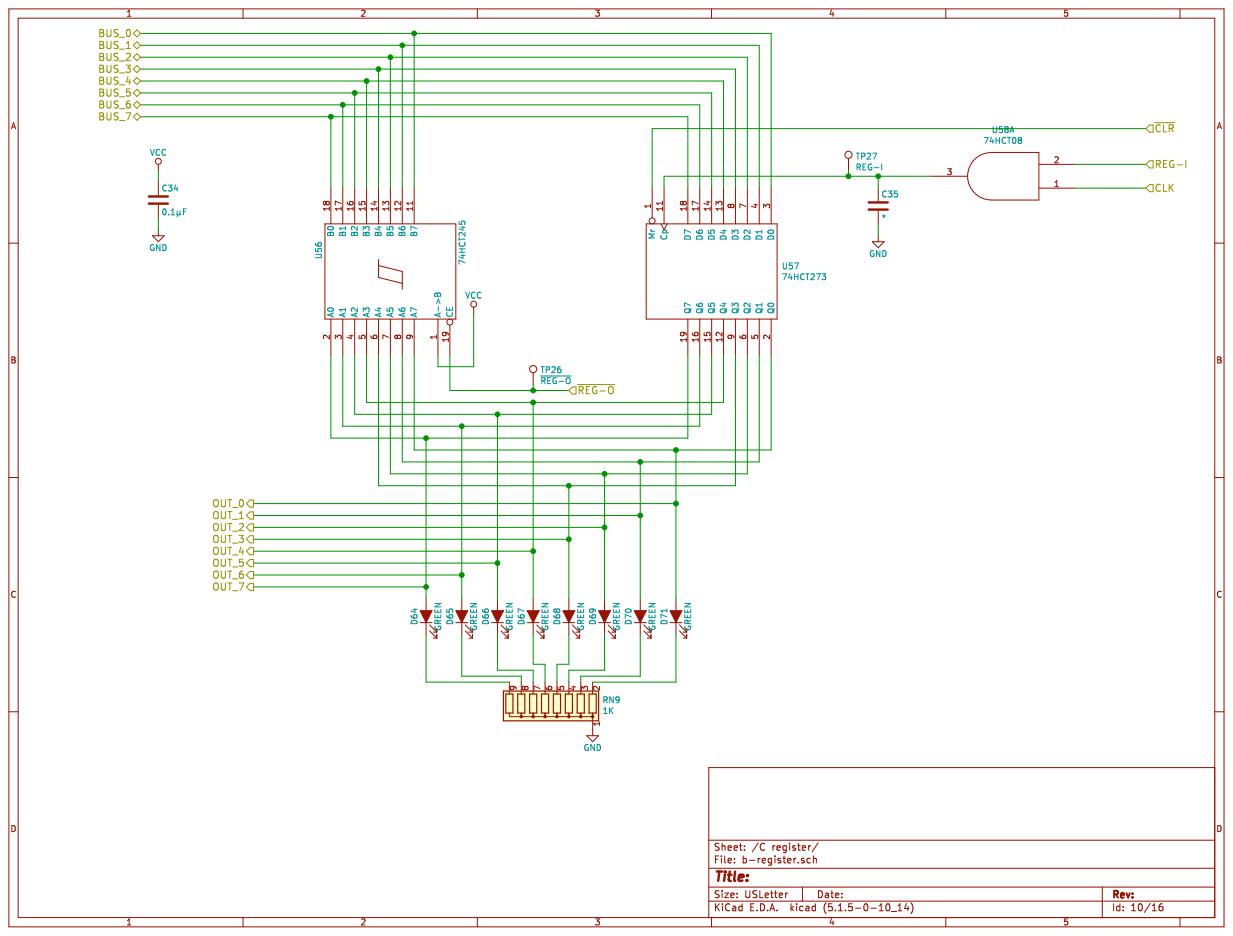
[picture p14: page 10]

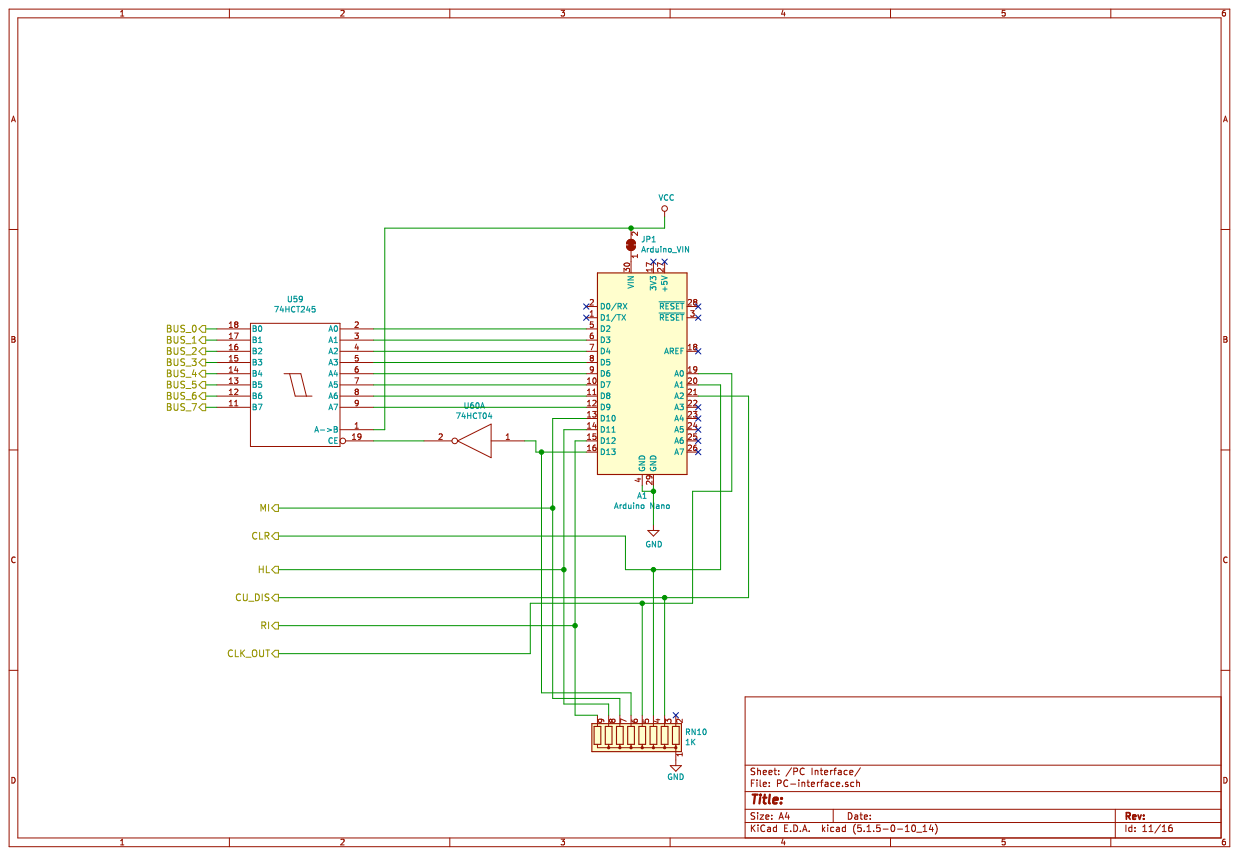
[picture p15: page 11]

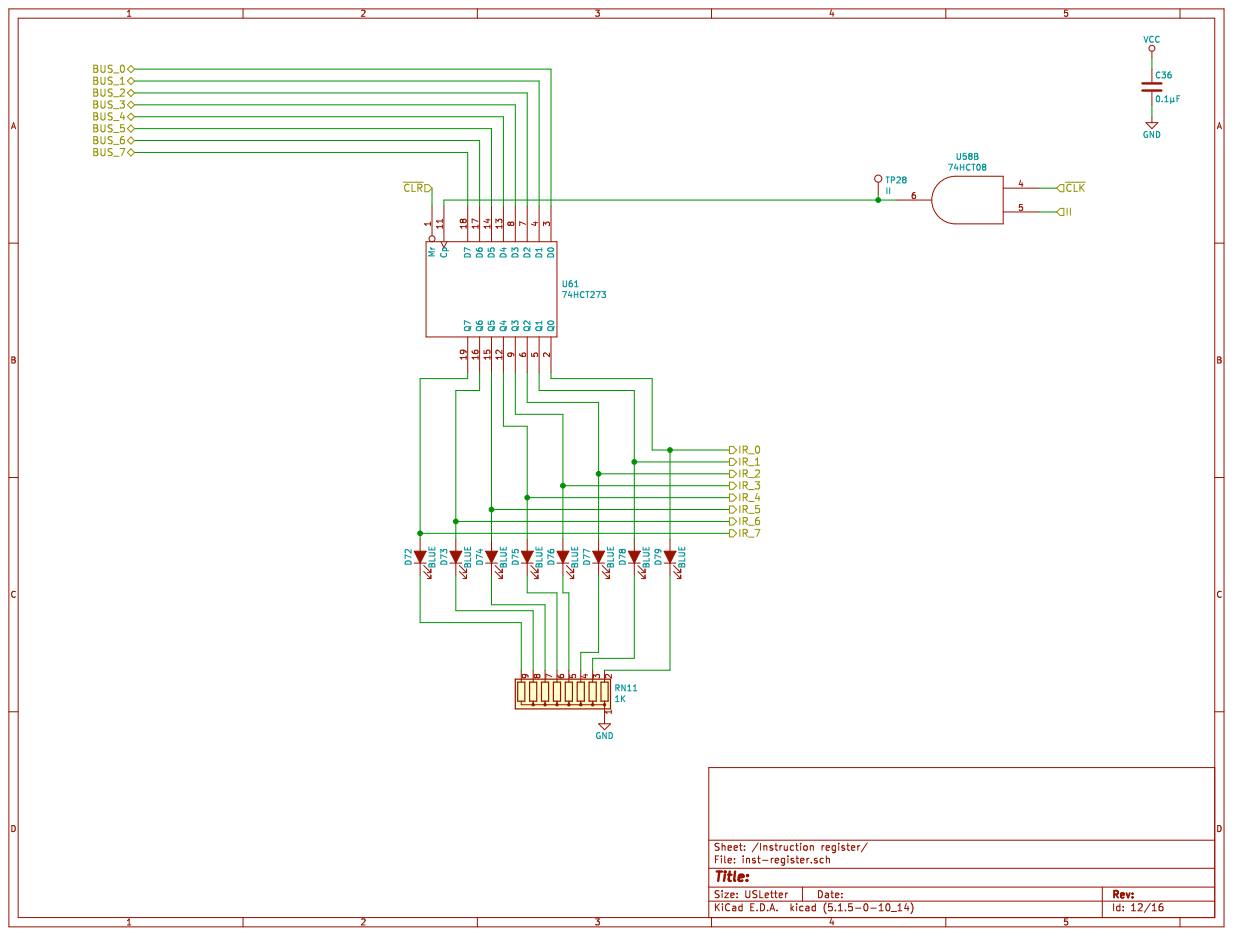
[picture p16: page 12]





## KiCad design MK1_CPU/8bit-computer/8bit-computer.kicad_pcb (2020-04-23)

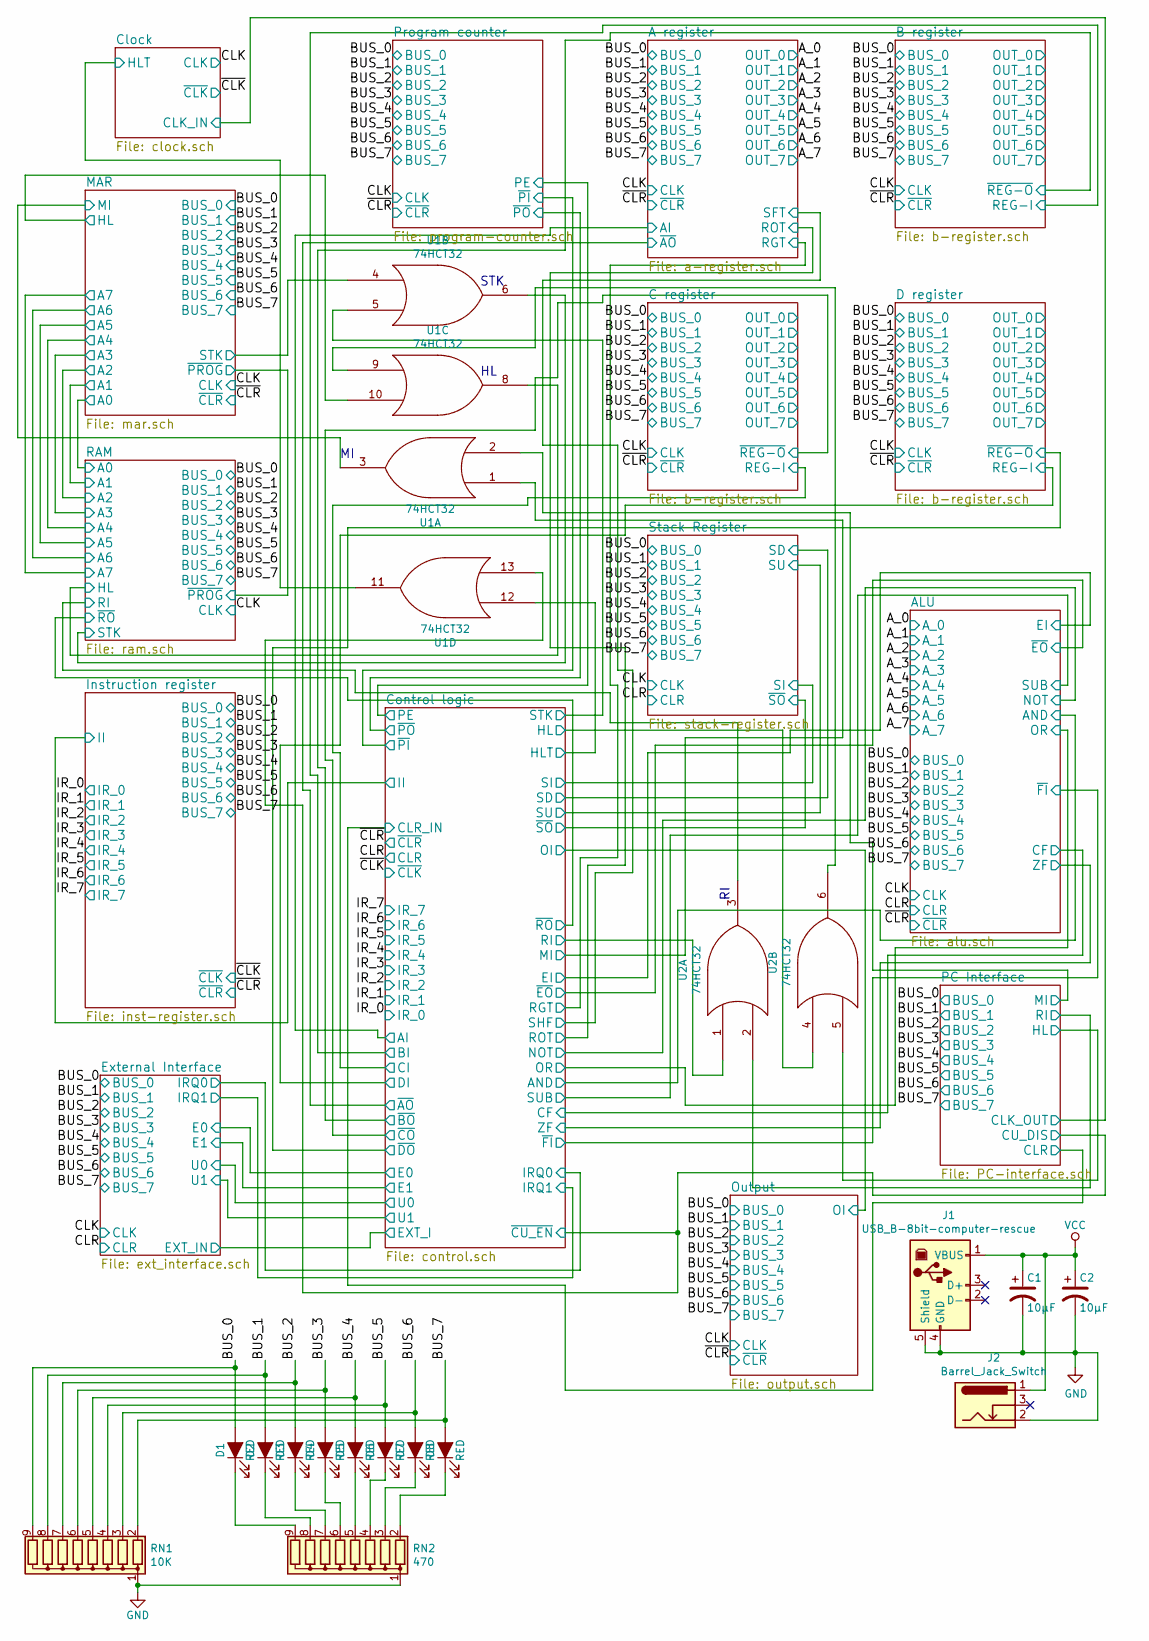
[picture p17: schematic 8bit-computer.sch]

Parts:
C1, C2: 10µF; CP_Radial_D5.0mm_P2.00mm
D1, D2, D3, D4, D5, D6, D7, D8: RED; LED_D3.0mm
J1: USB_B-8bit-computer-rescue; USB_B_OST_USB-B1HSxx_Horizontal
J2: Barrel_Jack_Switch; BarrelJack_Horizontal
RN1: 10K; R_Array_SIP9
RN2: 470; R_Array_SIP9
U1, U2: 74HCT32; DIP-14_W7.62mm

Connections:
/BUS_0: D1.2 (A), RN1.9 (R8); also elsewhere on the board
/BUS_1: D2.2 (A), RN1.8 (R7); also elsewhere on the board
/BUS_2: D3.2 (A), RN1.7 (R6); also elsewhere on the board
/BUS_3: D4.2 (A), RN1.6 (R5); also elsewhere on the board
/BUS_4: D5.2 (A), RN1.5 (R4); also elsewhere on the board
/BUS_5: D6.2 (A), RN1.4 (R3); also elsewhere on the board
/BUS_6: D7.2 (A), RN1.3 (R2); also elsewhere on the board
/BUS_7: D8.2 (A), RN1.2 (R1); also elsewhere on the board
/Clock/HLT: U1.11; also elsewhere on the board
/Control logic/HL: U2.4; also elsewhere on the board
/Control logic/HLT: U1.12; also elsewhere on the board
/Control logic/MI: U1.1; also elsewhere on the board
/Control logic/RI: U2.1; also elsewhere on the board
/Control logic/STK: U1.5; also elsewhere on the board
/MAR/HL: U1.10; also elsewhere on the board
/MAR/MI: U1.3; also elsewhere on the board
/MAR/STK: U1.4; also elsewhere on the board
/PC Interface/CU_DIS: U1.13; also elsewhere on the board
/PC Interface/HL: U2.5; also elsewhere on the board
/PC Interface/MI: U1.2; also elsewhere on the board
/PC Interface/RI: U2.2; also elsewhere on the board
/RAM/HL: U1.8; also elsewhere on the board
/RAM/RI: U2.3; also elsewhere on the board
/RAM/STK: U1.6; also elsewhere on the board
GND: C1.2, C2.2, J1.4 (GND), J1.5 (Shield), J2.2, RN1.1 (common), RN2.1 (common), U1.7 (GND), U2.7 (GND); also elsewhere on the board
unnamed: D1.1 (K), RN2.9 (R8)
unnamed: D2.1 (K), RN2.8 (R7)
unnamed: D3.1 (K), RN2.7 (R6)
unnamed: D4.1 (K), RN2.6 (R5)
unnamed: D5.1 (K), RN2.5 (R4)
unnamed: D6.1 (K), RN2.4 (R3)
unnamed: D7.1 (K), RN2.3 (R2)
unnamed: D8.1 (K), RN2.2 (R1)
unnamed: U1.9, U2.6
VCC: C1.1, C2.1, J1.1 (VBUS), J2.1, U1.14 (VCC), U2.14 (VCC); also elsewhere on the board

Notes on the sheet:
STK

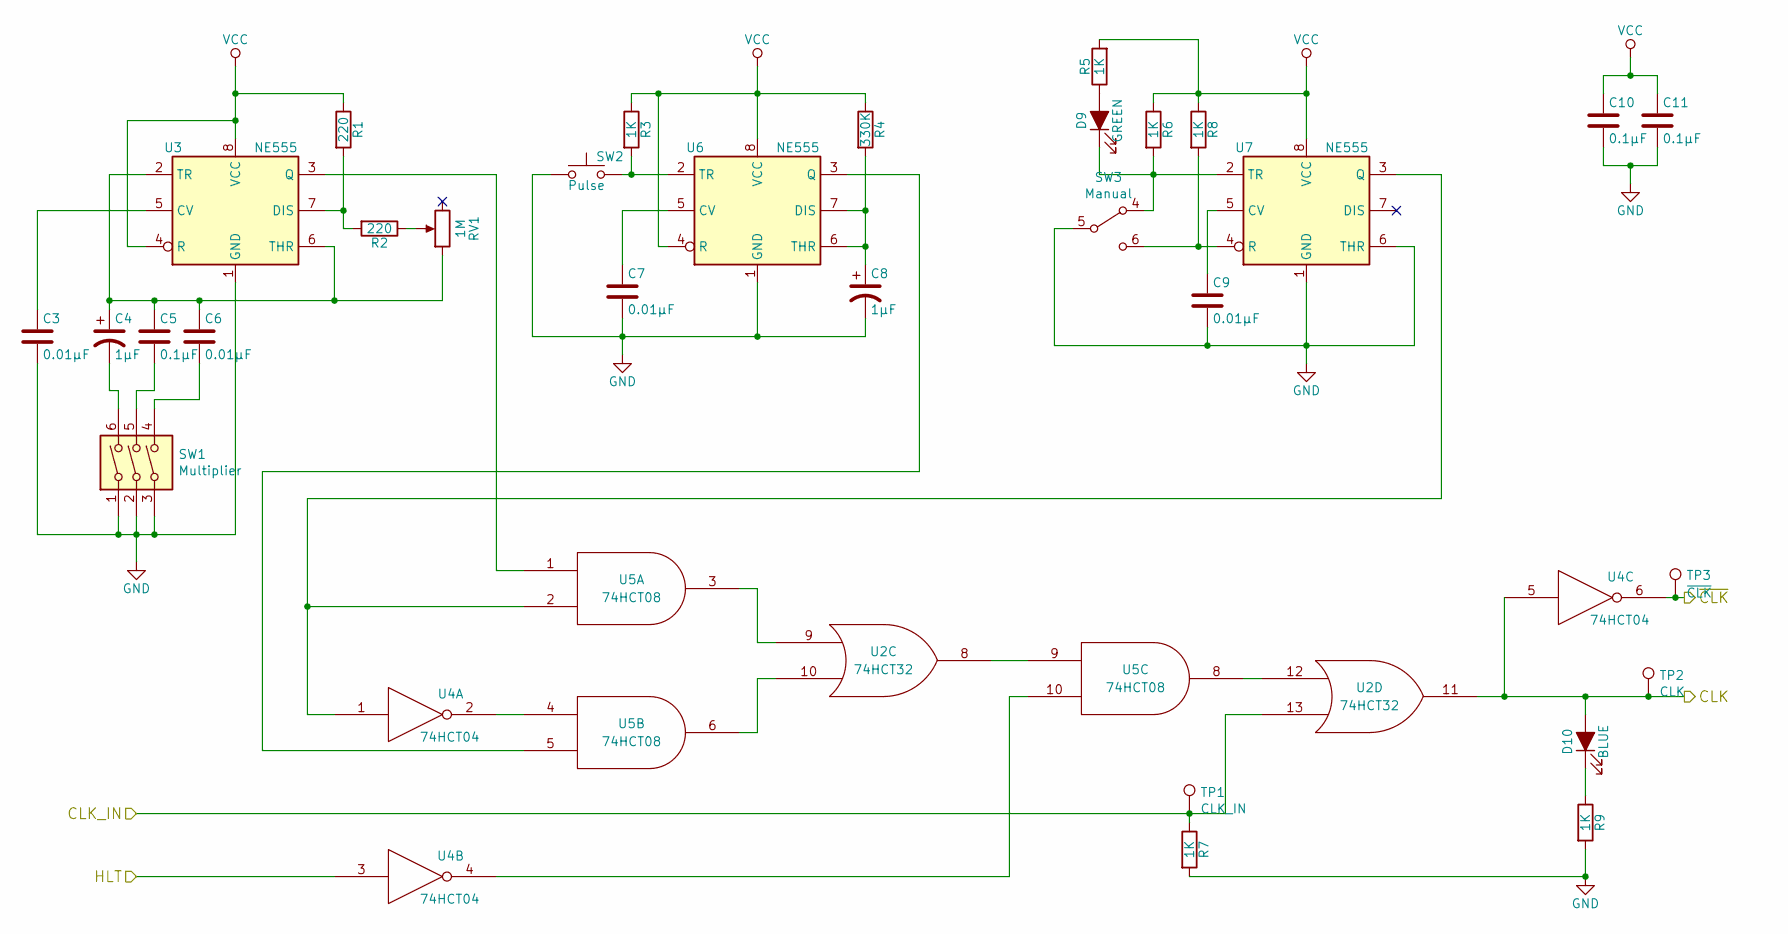
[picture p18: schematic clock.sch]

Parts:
C3, C6, C7, C9: 0.01µF; C_Disc_D4.3mm_W1.9mm_P5.00mm
C4, C8: 1µF; CP_Radial_D5.0mm_P2.00mm
C5, C10, C11: 0.1µF; C_Disc_D4.3mm_W1.9mm_P5.00mm
D9: GREEN; LED_D3.0mm
D10: BLUE; LED_D3.0mm
R1, R2: 220; R_Axial_DIN0207_L6.3mm_D2.5mm_P7.62mm_Horizontal
R3, R5, R6, R7, R8, R9: 1K; R_Axial_DIN0207_L6.3mm_D2.5mm_P7.62mm_Horizontal
R4: 330K; R_Axial_DIN0207_L6.3mm_D2.5mm_P7.62mm_Horizontal
RV1: 1M; Potentiometer_Bourns_PTV09A-1_Single_Vertical
SW1: Multiplier; SW_DIP_SPSTx03_Slide_9.78x9.8mm_W7.62mm_P2.54mm
SW2: Pulse; SW_PUSH_6mm_H5mm
SW3: Manual; SW_NKK_GW12LJP
TP1: CLK_IN; TestPoint_Pad_1.0x1.0mm
TP2: CLK; TestPoint_Pad_1.0x1.0mm
TP3: ~CLK; TestPoint_Pad_1.0x1.0mm
U2: 74HCT32; DIP-14_W7.62mm
U3, U6, U7: NE555; DIP-8_W7.62mm
U4: 74HCT04; DIP-14_W7.62mm
U5: 74HCT08; DIP-14_W7.62mm

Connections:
/CLK: D10.2 (A), TP2.1, U2.11, U4.5; also elsewhere on the board
/Clock/CLK_IN: R7.1, TP1.1, U2.13; also elsewhere on the board
/Clock/HLT: U4.3; also elsewhere on the board
/~CLK: TP3.1, U4.6; also elsewhere on the board
GND: C3.2, C7.2, C8.2, C9.2, C10.2, C11.2, R7.2, R9.2, SW1.1, SW1.2, SW1.3, SW2.1, SW3.5 (B), U2.7 (GND), U3.1 (GND), U4.7 (GND), U5.7 (GND), U6.1 (GND), U7.1 (GND), U7.6 (THR); also elsewhere on the board
unnamed: C3.1, U3.5 (CV)
unnamed: C4.1, C5.1, C6.1, RV1.1, U3.2 (TR), U3.6 (THR)
unnamed: C4.2, SW1.6
unnamed: C5.2, SW1.5
unnamed: C6.2, SW1.4
unnamed: C7.1, U6.5 (CV)
unnamed: C8.1, R4.2, U6.6 (THR), U6.7 (DIS)
unnamed: C9.1, U7.5 (CV)
unnamed: D9.1 (K), R6.2, SW3.4 (A), U7.2 (TR)
unnamed: D9.2 (A), R5.1
unnamed: D10.1 (K), R9.1
unnamed: R1.2, R2.2, U3.7 (DIS)
unnamed: R2.1, RV1.2
unnamed: R3.2, SW2.2, U6.2 (TR)
unnamed: R8.2, SW3.6 (C), U7.4 (R)
unnamed: U2.8, U5.9
unnamed: U2.9, U5.3
unnamed: U2.10, U5.6
unnamed: U2.12, U5.8
unnamed: U3.3 (Q), U5.1
unnamed: U4.1, U5.2, U7.3 (Q)
unnamed: U4.2, U5.4
unnamed: U4.4, U5.10
unnamed: U5.5, U6.3 (Q)
VCC: C10.1, C11.1, R1.1, R3.1, R4.1, R5.2, R6.1, R8.1, U2.14 (VCC), U3.4 (R), U3.8 (VCC), U4.14 (VCC), U5.14 (VCC), U6.4 (R), U6.8 (VCC), U7.8 (VCC); also elsewhere on the board

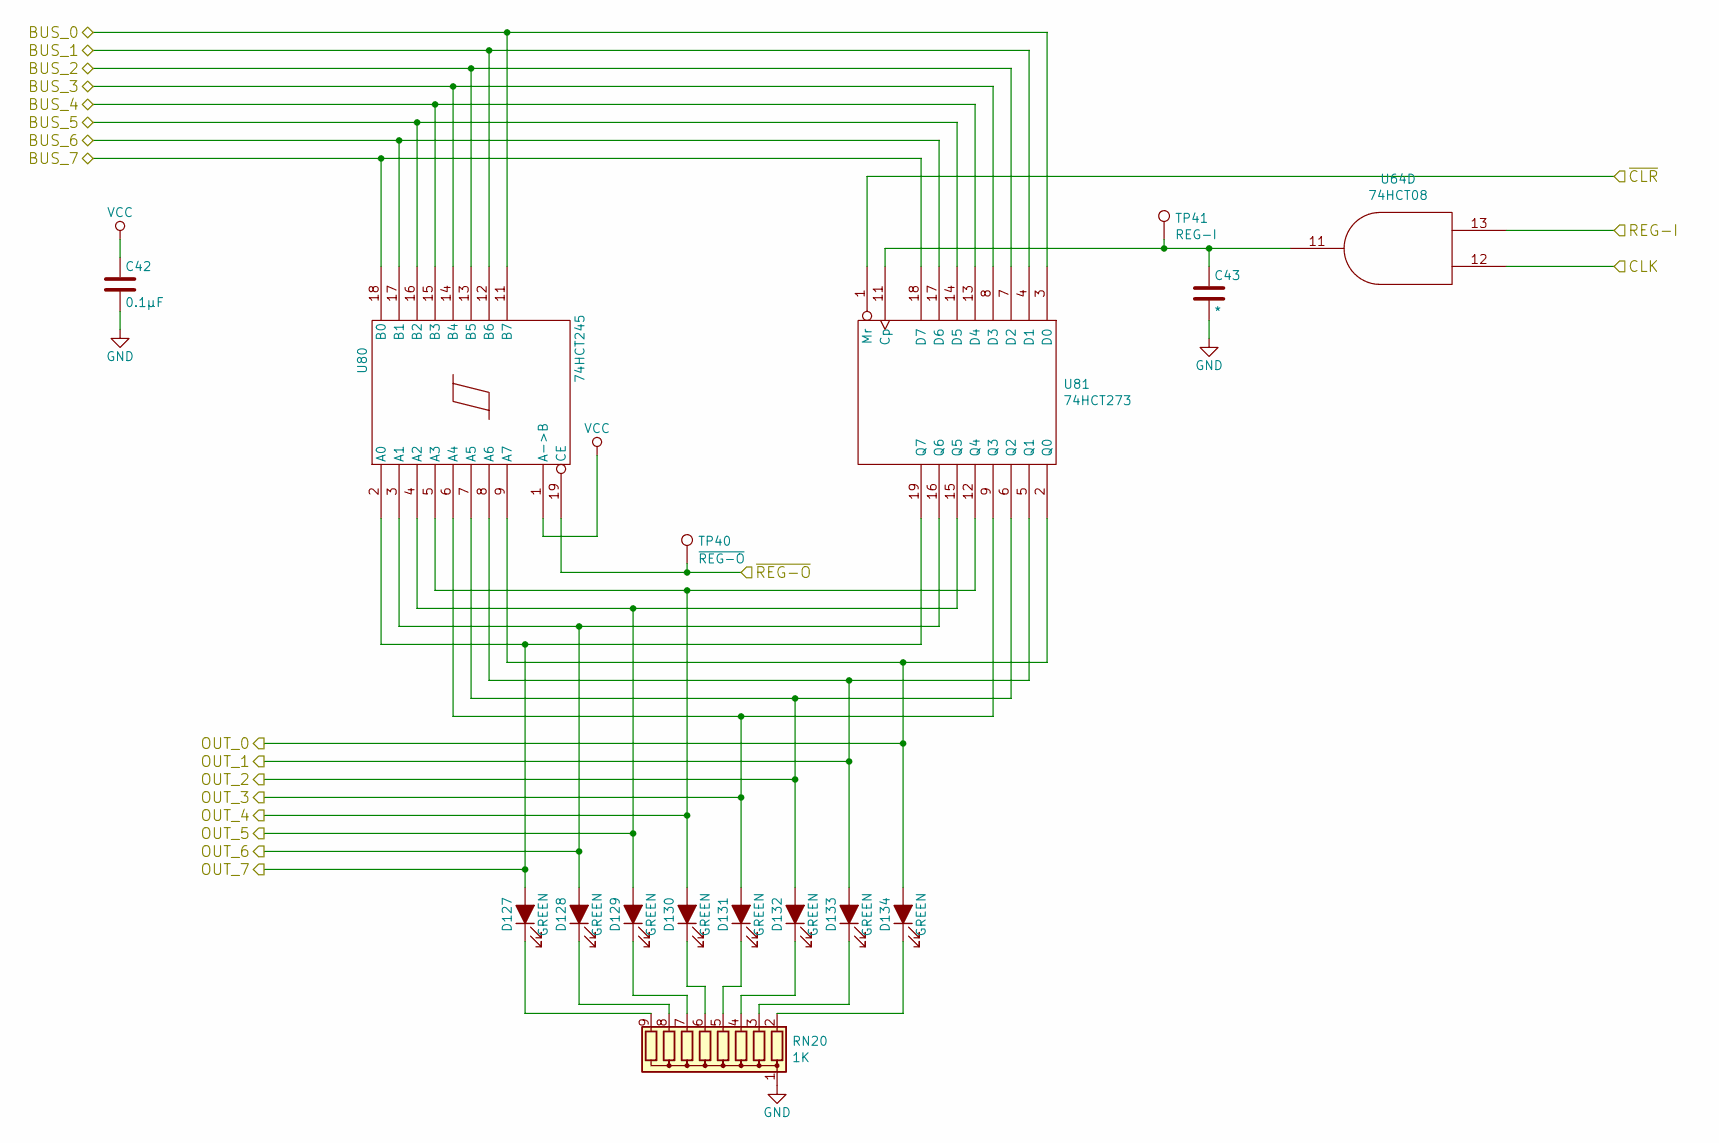
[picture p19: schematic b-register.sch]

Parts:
C12: 0.1µF; C_Disc_D4.3mm_W1.9mm_P5.00mm
C13: *; C_Disc_D4.3mm_W1.9mm_P5.00mm
D11, D12, D13, D14, D15, D16, D17, D18: GREEN; LED_D3.0mm
RN3: 1K; R_Array_SIP9
TP4: ~REG-O; TestPoint_Pad_1.0x1.0mm
TP5: REG-I; TestPoint_Pad_1.0x1.0mm
U5: 74HCT08; DIP-14_W7.62mm
U8: 74HCT245; DIP-20_W7.62mm
U9: 74HCT273; DIP-20_W7.62mm

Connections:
/B register/OUT_0: D18.2 (A), U8.9 (A7), U9.2 (Q0)
/B register/OUT_1: D17.2 (A), U8.8 (A6), U9.5 (Q1)
/B register/OUT_2: D16.2 (A), U8.7 (A5), U9.6 (Q2)
/B register/OUT_3: D15.2 (A), U8.6 (A4), U9.9 (Q3)
/B register/OUT_4: D14.2 (A), U8.5 (A3), U9.12 (Q4)
/B register/OUT_5: D13.2 (A), U8.4 (A2), U9.15 (Q5)
/B register/OUT_6: D12.2 (A), U8.3 (A1), U9.16 (Q6)
/B register/OUT_7: D11.2 (A), U8.2 (A0), U9.19 (Q7)
/BUS_0: U8.11 (B7), U9.3 (D0); also elsewhere on the board
/BUS_1: U8.12 (B6), U9.4 (D1); also elsewhere on the board
/BUS_2: U8.13 (B5), U9.7 (D2); also elsewhere on the board
/BUS_3: U8.14 (B4), U9.8 (D3); also elsewhere on the board
/BUS_4: U8.15 (B3), U9.13 (D4); also elsewhere on the board
/BUS_5: U8.16 (B2), U9.14 (D5); also elsewhere on the board
/BUS_6: U8.17 (B1), U9.17 (D6); also elsewhere on the board
/BUS_7: U8.18 (B0), U9.18 (D7); also elsewhere on the board
/CLK: U5.12; also elsewhere on the board
/Control logic/BI: U5.13; also elsewhere on the board
/Control logic/~BO: TP4.1, U8.19 (CE); also elsewhere on the board
/~CLR: U9.1 (Mr); also elsewhere on the board
GND: C12.2, C13.2, RN3.1 (common), U5.7 (GND), U8.10 (GND), U9.10 (GND); also elsewhere on the board
unnamed: C13.1, TP5.1, U5.11, U9.11 (Cp)
unnamed: D11.1 (K), RN3.9 (R8)
unnamed: D12.1 (K), RN3.8 (R7)
unnamed: D13.1 (K), RN3.7 (R6)
unnamed: D14.1 (K), RN3.6 (R5)
unnamed: D15.1 (K), RN3.5 (R4)
unnamed: D16.1 (K), RN3.4 (R3)
unnamed: D17.1 (K), RN3.3 (R2)
unnamed: D18.1 (K), RN3.2 (R1)
VCC: C12.1, U5.14 (VCC), U8.1 (A->B), U8.20 (VCC), U9.20 (VCC); also elsewhere on the board

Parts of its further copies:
C34, C42: 0.1µF; C_Disc_D4.3mm_W1.9mm_P5.00mm
C35, C43: *; C_Disc_D4.3mm_W1.9mm_P5.00mm
D64, D65, D66, D67, D68, D69, D70, D71, D127, D128, D129, D130, D131, D132, D133, D134: GREEN; LED_D3.0mm
RN9, RN20: 1K; R_Array_SIP9
TP26, TP40: ~REG-O; TestPoint_Pad_1.0x1.0mm
TP27, TP41: REG-I; TestPoint_Pad_1.0x1.0mm
U56, U80: 74HCT245; DIP-20_W7.62mm
U57, U81: 74HCT273; DIP-20_W7.62mm

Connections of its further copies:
/BUS_0: U56.11 (B7), U57.3 (D0), U80.11 (B7), U81.3 (D0); also elsewhere on the board
/BUS_1: U56.12 (B6), U57.4 (D1), U80.12 (B6), U81.4 (D1); also elsewhere on the board
/BUS_2: U56.13 (B5), U57.7 (D2), U80.13 (B5), U81.7 (D2); also elsewhere on the board
/BUS_3: U56.14 (B4), U57.8 (D3), U80.14 (B4), U81.8 (D3); also elsewhere on the board
/BUS_4: U56.15 (B3), U57.13 (D4), U80.15 (B3), U81.13 (D4); also elsewhere on the board
/BUS_5: U56.16 (B2), U57.14 (D5), U80.16 (B2), U81.14 (D5); also elsewhere on the board
/BUS_6: U56.17 (B1), U57.17 (D6), U80.17 (B1), U81.17 (D6); also elsewhere on the board
/BUS_7: U56.18 (B0), U57.18 (D7), U80.18 (B0), U81.18 (D7); also elsewhere on the board
/C register/OUT_0: D71.2 (A), U56.9 (A7), U57.2 (Q0)
/C register/OUT_1: D70.2 (A), U56.8 (A6), U57.5 (Q1)
/C register/OUT_2: D69.2 (A), U56.7 (A5), U57.6 (Q2)
/C register/OUT_3: D68.2 (A), U56.6 (A4), U57.9 (Q3)
/C register/OUT_4: D67.2 (A), U56.5 (A3), U57.12 (Q4)
/C register/OUT_5: D66.2 (A), U56.4 (A2), U57.15 (Q5)
/C register/OUT_6: D65.2 (A), U56.3 (A1), U57.16 (Q6)
/C register/OUT_7: D64.2 (A), U56.2 (A0), U57.19 (Q7)
/Control logic/~CO: TP26.1, U56.19 (CE); also elsewhere on the board
/Control logic/~DO: TP40.1, U80.19 (CE); also elsewhere on the board
/D register/OUT_0: D134.2 (A), U80.9 (A7), U81.2 (Q0)
/D register/OUT_1: D133.2 (A), U80.8 (A6), U81.5 (Q1)
/D register/OUT_2: D132.2 (A), U80.7 (A5), U81.6 (Q2)
/D register/OUT_3: D131.2 (A), U80.6 (A4), U81.9 (Q3)
/D register/OUT_4: D130.2 (A), U80.5 (A3), U81.12 (Q4)
/D register/OUT_5: D129.2 (A), U80.4 (A2), U81.15 (Q5)
/D register/OUT_6: D128.2 (A), U80.3 (A1), U81.16 (Q6)
/D register/OUT_7: D127.2 (A), U80.2 (A0), U81.19 (Q7)
/~CLR: U57.1 (Mr), U81.1 (Mr); also elsewhere on the board
GND: C34.2, C35.2, C42.2, C43.2, RN9.1 (common), RN20.1 (common), U56.10 (GND), U57.10 (GND), U80.10 (GND), U81.10 (GND); also elsewhere on the board
unnamed 157: C35.1, TP27.1, U57.11 (Cp); also elsewhere on the board
unnamed 160: C43.1, TP41.1, U81.11 (Cp); also elsewhere on the board
unnamed: D64.1 (K), RN9.9 (R8)
unnamed: D65.1 (K), RN9.8 (R7)
unnamed: D66.1 (K), RN9.7 (R6)
unnamed: D67.1 (K), RN9.6 (R5)
unnamed: D68.1 (K), RN9.5 (R4)
unnamed: D69.1 (K), RN9.4 (R3)
unnamed: D70.1 (K), RN9.3 (R2)
unnamed: D71.1 (K), RN9.2 (R1)
unnamed: D127.1 (K), RN20.9 (R8)
unnamed: D128.1 (K), RN20.8 (R7)
unnamed: D129.1 (K), RN20.7 (R6)
unnamed: D130.1 (K), RN20.6 (R5)
unnamed: D131.1 (K), RN20.5 (R4)
unnamed: D132.1 (K), RN20.4 (R3)
unnamed: D133.1 (K), RN20.3 (R2)
unnamed: D134.1 (K), RN20.2 (R1)
VCC: C34.1, C42.1, U56.1 (A->B), U56.20 (VCC), U57.20 (VCC), U80.1 (A->B), U80.20 (VCC), U81.20 (VCC); also elsewhere on the board

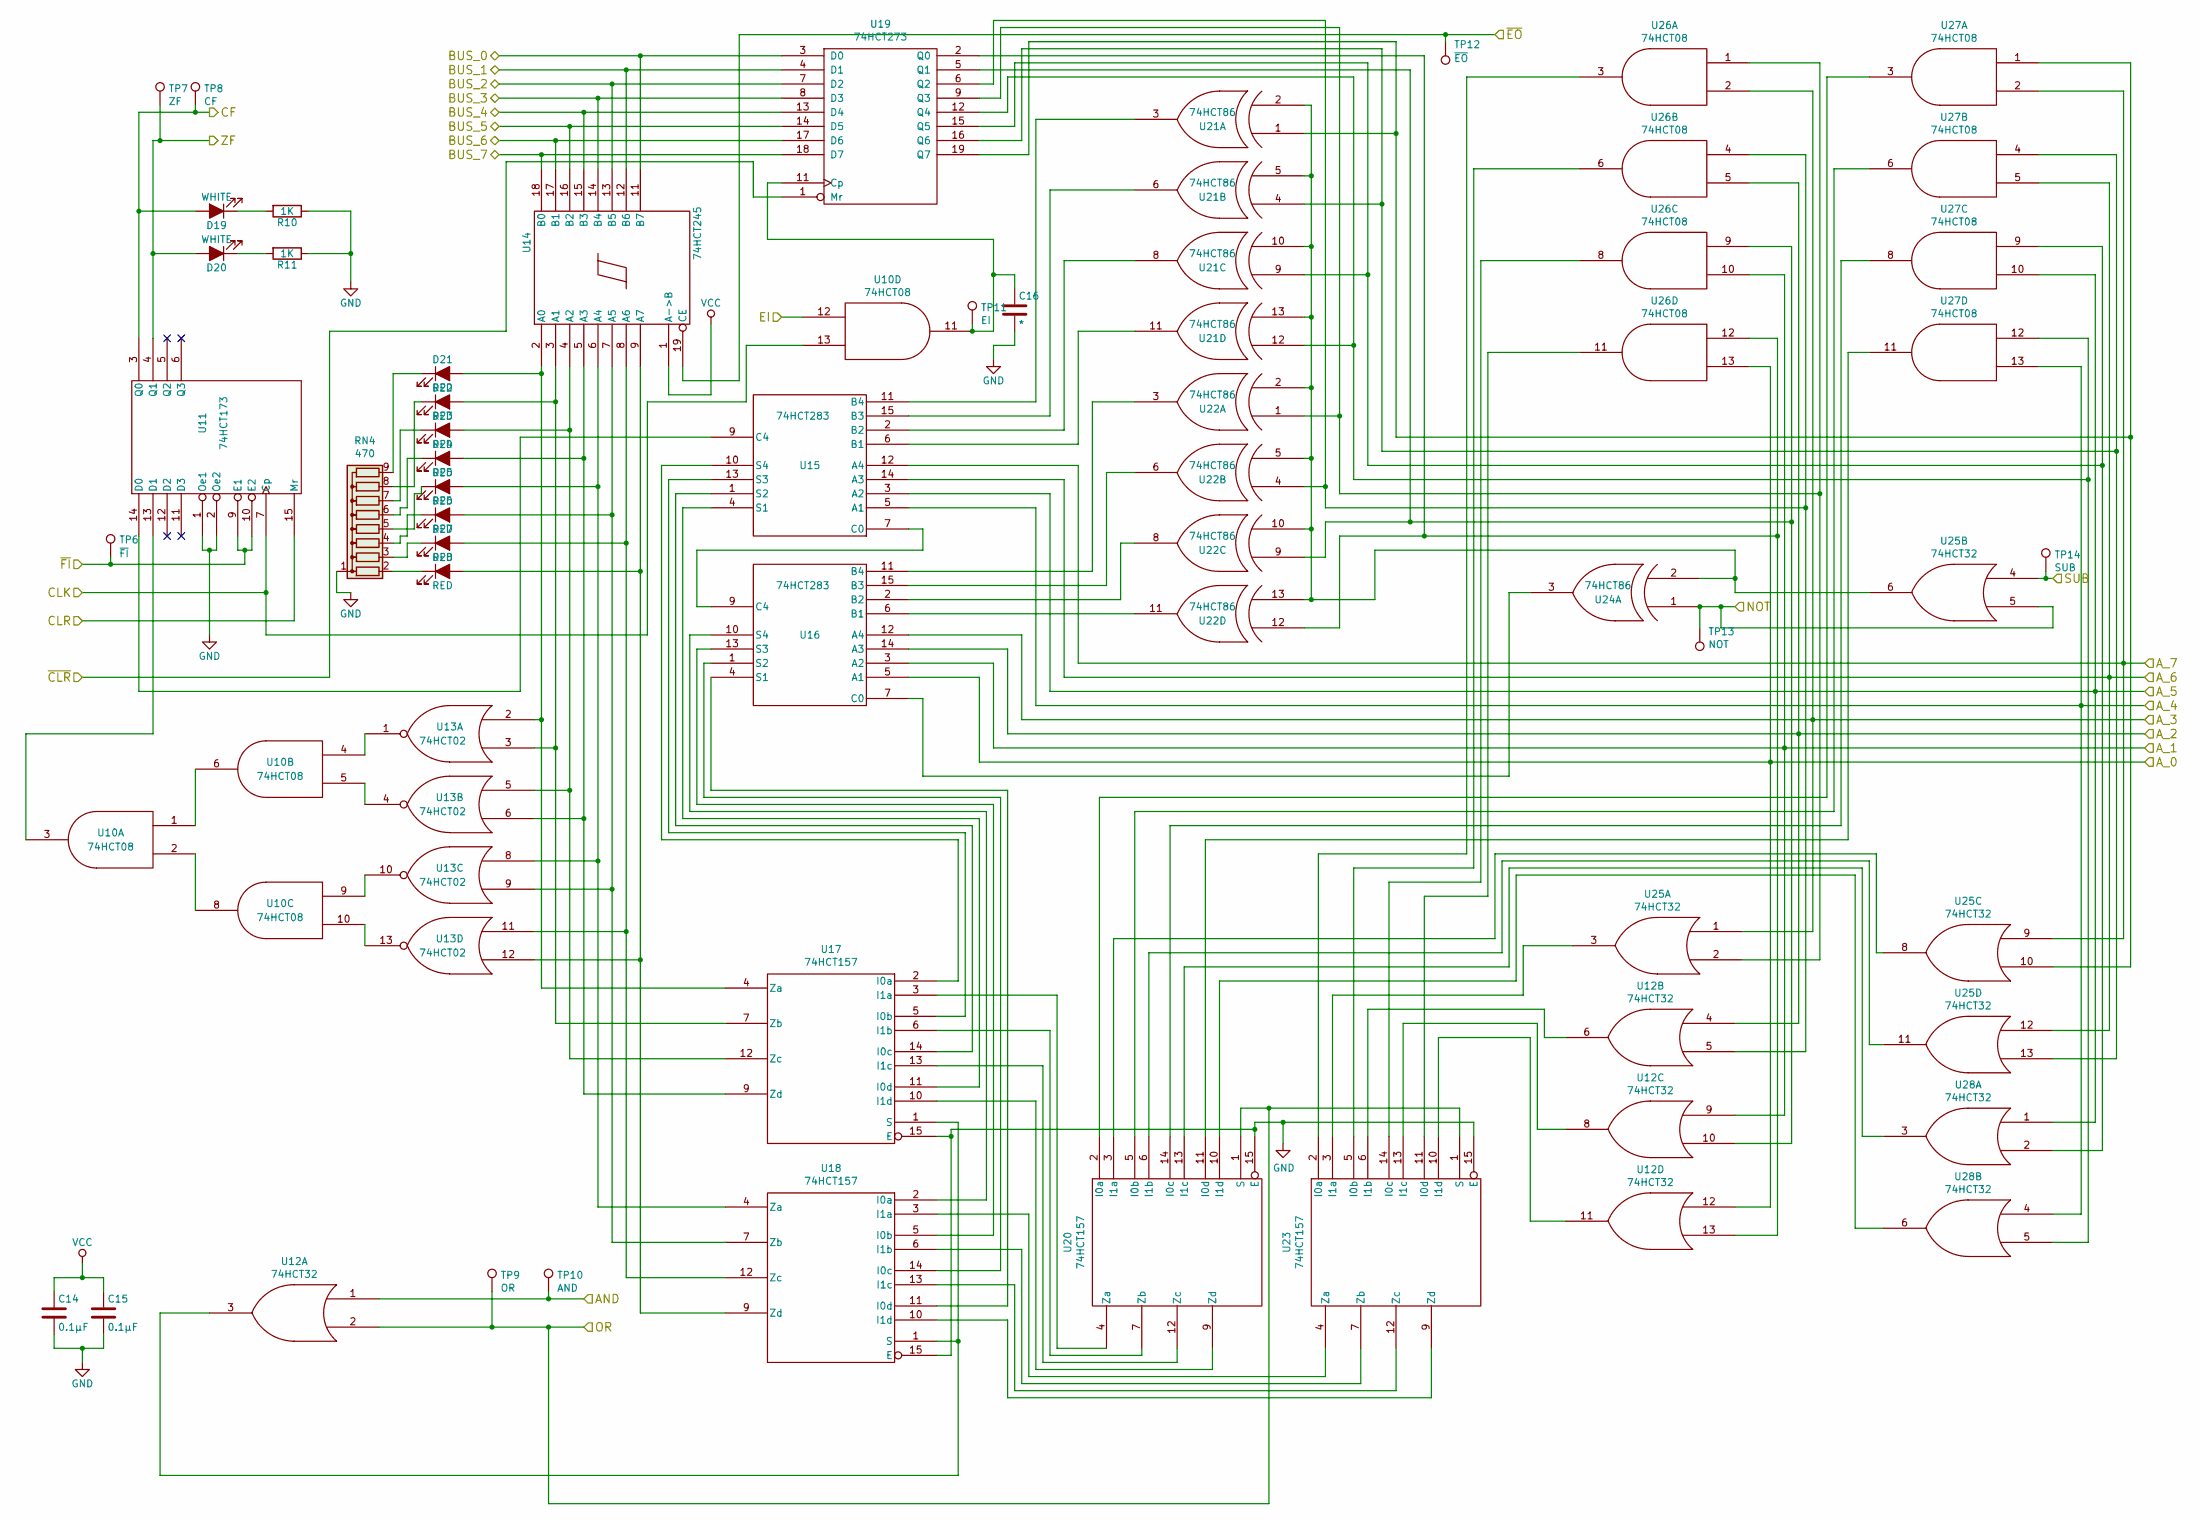
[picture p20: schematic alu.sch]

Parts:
C14, C15: 0.1µF; C_Disc_D4.3mm_W1.9mm_P5.00mm
C16: *; C_Disc_D4.3mm_W1.9mm_P5.00mm
D19, D20: WHITE; LED_D3.0mm
D21, D22, D23, D24, D25, D26, D27, D28: RED; LED_D3.0mm
R10, R11: 1K; R_Axial_DIN0207_L6.3mm_D2.5mm_P7.62mm_Horizontal
RN4: 470; R_Array_SIP9
TP6: ~FI; TestPoint_Pad_1.0x1.0mm
TP7: ZF; TestPoint_Pad_1.0x1.0mm
TP8: CF; TestPoint_Pad_1.0x1.0mm
TP9: OR; TestPoint_Pad_1.0x1.0mm
TP10: AND; TestPoint_Pad_1.0x1.0mm
TP11: EI; TestPoint_Pad_1.0x1.0mm
TP12: ~EO; TestPoint_Pad_1.0x1.0mm
TP13: NOT; TestPoint_Pad_1.0x1.0mm
TP14: SUB; TestPoint_Pad_1.0x1.0mm
U10, U26, U27: 74HCT08; DIP-14_W7.62mm
U11: 74HCT173; DIP-16_W7.62mm
U12, U25, U28: 74HCT32; DIP-14_W7.62mm
U13: 74HCT02; DIP-14_W7.62mm
U14: 74HCT245; DIP-20_W7.62mm
U15, U16: 74HCT283; DIP-16_W7.62mm
U17, U18, U20, U23: 74HCT157; DIP-16_W7.62mm
U19: 74HCT273; DIP-20_W7.62mm
U21, U22, U24: 74HCT86; DIP-14_W7.62mm

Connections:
/ALU/AND: TP10.1, U12.1; also elsewhere on the board
/ALU/CF: D19.2 (A), TP8.1, U11.3 (Q0); also elsewhere on the board
/ALU/EI: U10.12; also elsewhere on the board
/ALU/NOT: TP13.1, U24.1 (IN1), U25.5; also elsewhere on the board
/ALU/OR: TP9.1, U12.2, U20.1 (S), U23.1 (S); also elsewhere on the board
/ALU/SUB: TP14.1, U25.4; also elsewhere on the board
/ALU/ZF: D20.2 (A), TP7.1, U11.4 (Q1); also elsewhere on the board
/ALU/~EO: TP12.1, U14.19 (CE); also elsewhere on the board
/ALU/~FI: TP6.1, U11.9 (E1), U11.10 (E2); also elsewhere on the board
/A_0: U12.12, U16.5 (A1), U26.13; also elsewhere on the board
/A_1: U12.9, U16.3 (A2), U26.10; also elsewhere on the board
/A_2: U12.4, U16.14 (A3), U26.5; also elsewhere on the board
/A_3: U16.12 (A4), U25.1, U26.2; also elsewhere on the board
/A_4: U15.5 (A1), U27.13, U28.4; also elsewhere on the board
/A_5: U15.3 (A2), U27.10, U28.1; also elsewhere on the board
/A_6: U15.14 (A3), U25.12, U27.5; also elsewhere on the board
/A_7: U15.12 (A4), U25.9, U27.2; also elsewhere on the board
/BUS_0: U14.11 (B7), U19.3 (D0); also elsewhere on the board
/BUS_1: U14.12 (B6), U19.4 (D1); also elsewhere on the board
/BUS_2: U14.13 (B5), U19.7 (D2); also elsewhere on the board
/BUS_3: U14.14 (B4), U19.8 (D3); also elsewhere on the board
/BUS_4: U14.15 (B3), U19.13 (D4); also elsewhere on the board
/BUS_5: U14.16 (B2), U19.14 (D5); also elsewhere on the board
/BUS_6: U14.17 (B1), U19.17 (D6); also elsewhere on the board
/BUS_7: U14.18 (B0), U19.18 (D7); also elsewhere on the board
/CLK: U10.13, U11.7 (Cp); also elsewhere on the board
/CLR: U11.15 (Mr); also elsewhere on the board
/~CLR: U19.1 (Mr); also elsewhere on the board
GND: C14.2, C15.2, C16.2, R10.1, R11.1, RN4.1 (common), U10.7 (GND), U11.1 (Oe1), U11.2 (Oe2), U11.8 (GND), U12.7 (GND), U13.7 (GND), U14.10 (GND), U15.8 (GND), U16.8 (GND), U17.8 (GND), U17.15 (E), U18.8 (GND), U18.15 (E), U19.10 (GND), U20.8 (GND), U20.15 (E), U21.7 (GND), U22.7 (GND), U23.8 (GND), U23.15 (E), U24.7 (GND), U25.7 (GND), U26.7 (GND), U27.7 (GND), U28.7 (GND); also elsewhere on the board
unnamed: C16.1, TP11.1, U10.11, U19.11 (Cp)
unnamed: D19.1 (K), R10.2
unnamed: D20.1 (K), R11.2
unnamed: D21.1 (K), RN4.9 (R8)
unnamed: D21.2 (A), U13.2, U14.2 (A0), U17.4 (Za)
unnamed: D22.1 (K), RN4.8 (R7)
unnamed: D22.2 (A), U13.3, U14.3 (A1), U17.7 (Zb)
unnamed: D23.1 (K), RN4.7 (R6)
unnamed: D23.2 (A), U13.5, U14.4 (A2), U17.12 (Zc)
unnamed: D24.1 (K), RN4.6 (R5)
unnamed: D24.2 (A), U13.6, U14.5 (A3), U17.9 (Zd)
unnamed: D25.1 (K), RN4.5 (R4)
unnamed: D25.2 (A), U13.8, U14.6 (A4), U18.4 (Za)
unnamed: D26.1 (K), RN4.4 (R3)
unnamed: D26.2 (A), U13.9, U14.7 (A5), U18.7 (Zb)
unnamed: D27.1 (K), RN4.3 (R2)
unnamed: D27.2 (A), U13.11, U14.8 (A6), U18.12 (Zc)
unnamed: D28.1 (K), RN4.2 (R1)
unnamed: D28.2 (A), U13.12, U14.9 (A7), U18.9 (Zd)
unnamed: U10.1, U10.6
unnamed: U10.2, U10.8
unnamed: U10.3, U11.13 (D1)
unnamed: U10.4, U13.1
unnamed: U10.5, U13.4
unnamed: U10.9, U13.10
unnamed: U10.10, U13.13
unnamed: U11.14 (D0), U15.9 (C4)
unnamed: U12.3, U17.1 (S), U18.1 (S)
unnamed: U12.5, U19.6 (Q2), U22.4 (IN1), U26.4
unnamed: U12.6, U23.6 (I1b)
unnamed: U12.8, U23.13 (I1c)
unnamed: U12.10, U19.5 (Q1), U22.9 (IN1), U26.9
unnamed: U12.11, U23.10 (I1d)
unnamed: U12.13, U19.2 (Q0), U22.12 (IN1), U26.12
unnamed: U15.1 (S2), U17.14 (I0c)
unnamed: U15.2 (B2), U21.8 (OUT)
unnamed: U15.4 (S1), U17.11 (I0d)
unnamed: U15.6 (B1), U21.11 (OUT)
unnamed: U15.7 (C0), U16.9 (C4)
unnamed: U15.10 (S4), U17.2 (I0a)
unnamed: U15.11 (B4), U21.3 (OUT)
unnamed: U15.13 (S3), U17.5 (I0b)
unnamed: U15.15 (B3), U21.6 (OUT)
unnamed: U16.1 (S2), U18.14 (I0c)
unnamed: U16.2 (B2), U22.8 (OUT)
unnamed: U16.4 (S1), U18.11 (I0d)
unnamed: U16.6 (B1), U22.11 (OUT)
unnamed: U16.7 (C0), U24.3 (OUT)
unnamed: U16.10 (S4), U18.2 (I0a)
unnamed: U16.11 (B4), U22.3 (OUT)
unnamed: U16.13 (S3), U18.5 (I0b)
unnamed: U16.15 (B3), U22.6 (OUT)
unnamed: U17.3 (I1a), U20.4 (Za)
unnamed: U17.6 (I1b), U20.7 (Zb)
unnamed: U17.10 (I1d), U20.9 (Zd)
unnamed: U17.13 (I1c), U20.12 (Zc)
unnamed: U18.3 (I1a), U23.4 (Za)
unnamed: U18.6 (I1b), U23.7 (Zb)
unnamed: U18.10 (I1d), U23.9 (Zd)
unnamed: U18.13 (I1c), U23.12 (Zc)
unnamed: U19.9 (Q3), U22.1 (IN1), U25.2, U26.1
unnamed: U19.12 (Q4), U21.12 (IN1), U27.12, U28.5
unnamed: U19.15 (Q5), U21.9 (IN1), U27.9, U28.2
unnamed: U19.16 (Q6), U21.4 (IN1), U25.13, U27.4
unnamed: U19.19 (Q7), U21.1 (IN1), U25.10, U27.1
unnamed: U20.2 (I0a), U27.3
unnamed: U20.3 (I1a), U25.8
unnamed: U20.5 (I0b), U27.6
unnamed: U20.6 (I1b), U25.11
unnamed: U20.10 (I1d), U28.6
unnamed: U20.11 (I0d), U27.11
unnamed: U20.13 (I1c), U28.3
unnamed: U20.14 (I0c), U27.8
unnamed: U21.2 (IN2), U21.5 (IN2), U21.10 (IN2), U21.13 (IN2), U22.2 (IN2), U22.5 (IN2), U22.10 (IN2), U22.13 (IN2), U24.2 (IN2), U25.6
unnamed: U23.2 (I0a), U26.3
unnamed: U23.3 (I1a), U25.3
unnamed: U23.5 (I0b), U26.6
unnamed: U23.11 (I0d), U26.11
unnamed: U23.14 (I0c), U26.8
VCC: C14.1, C15.1, U10.14 (VCC), U11.16 (VCC), U12.14 (VCC), U13.14 (VCC), U14.1 (A->B), U14.20 (VCC), U15.16 (VCC), U16.16 (VCC), U17.16 (VCC), U18.16 (VCC), U19.20 (VCC), U20.16 (VCC), U21.14 (VCC), U22.14 (VCC), U23.16 (VCC), U24.14 (VCC), U25.14 (VCC), U26.14 (VCC), U27.14 (VCC), U28.14 (VCC); also elsewhere on the board

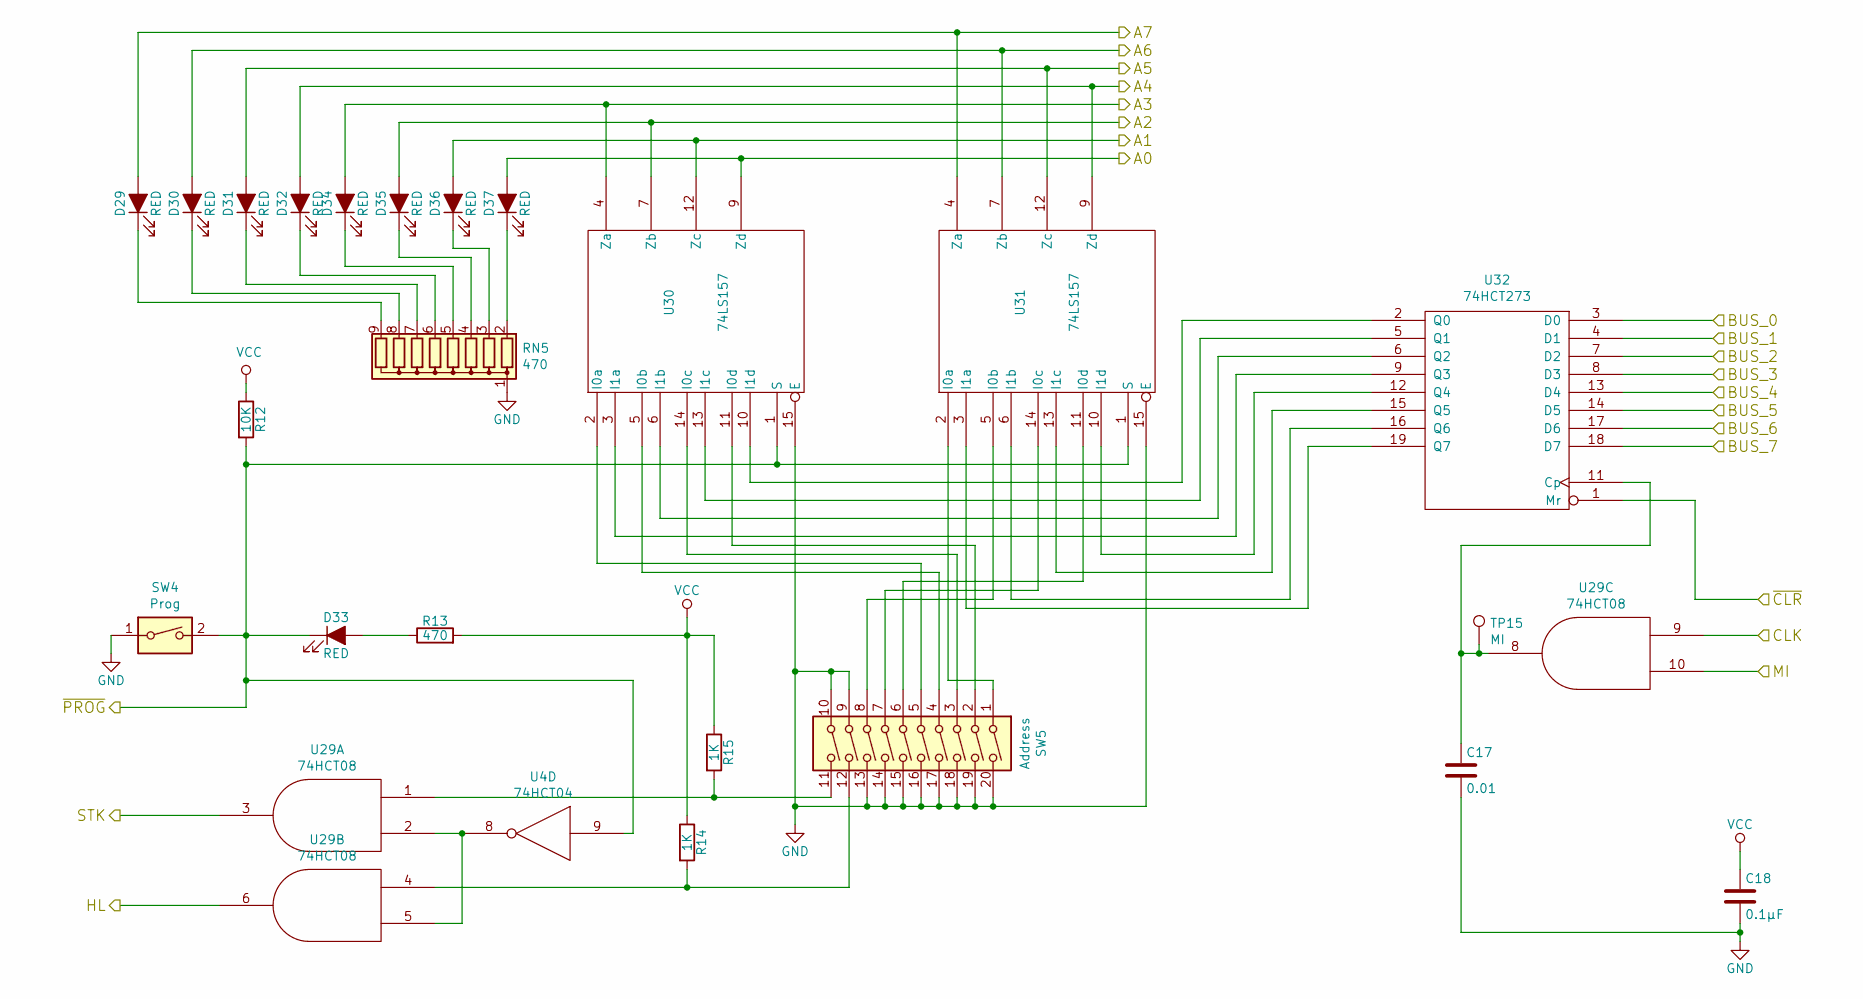
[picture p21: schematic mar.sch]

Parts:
C17: 0.01; C_Disc_D4.3mm_W1.9mm_P5.00mm
C18: 0.1µF; C_Disc_D4.3mm_W1.9mm_P5.00mm
D29, D30, D31, D32, D33, D34, D35, D36, D37: RED; LED_D3.0mm
R12: 10K; R_Axial_DIN0207_L6.3mm_D2.5mm_P7.62mm_Horizontal
R13: 470; R_Axial_DIN0207_L6.3mm_D2.5mm_P7.62mm_Horizontal
R14, R15: 1K; R_Axial_DIN0207_L6.3mm_D2.5mm_P7.62mm_Horizontal
RN5: 470; R_Array_SIP9
SW4: Prog; SW_DIP_SPSTx01_Slide_9.78x4.72mm_W7.62mm_P2.54mm
SW5: Address; SW_DIP_SPSTx10_Slide_9.78x27.58mm_W7.62mm_P2.54mm
TP15: MI; TestPoint_Pad_1.0x1.0mm
U4: 74HCT04; DIP-14_W7.62mm
U29: 74HCT08; DIP-14_W7.62mm
U30, U31: 74LS157; DIP-16_W7.62mm
U32: 74HCT273; DIP-20_W7.62mm

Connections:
/BUS_0: U32.3 (D0); also elsewhere on the board
/BUS_1: U32.4 (D1); also elsewhere on the board
/BUS_2: U32.7 (D2); also elsewhere on the board
/BUS_3: U32.8 (D3); also elsewhere on the board
/BUS_4: U32.13 (D4); also elsewhere on the board
/BUS_5: U32.14 (D5); also elsewhere on the board
/BUS_6: U32.17 (D6); also elsewhere on the board
/BUS_7: U32.18 (D7); also elsewhere on the board
/CLK: U29.9; also elsewhere on the board
/MAR/A0: D37.2 (A), U30.9 (Zd); also elsewhere on the board
/MAR/A1: D36.2 (A), U30.12 (Zc); also elsewhere on the board
/MAR/A2: D35.2 (A), U30.7 (Zb); also elsewhere on the board
/MAR/A3: D34.2 (A), U30.4 (Za); also elsewhere on the board
/MAR/A4: D32.2 (A), U31.9 (Zd); also elsewhere on the board
/MAR/A5: D31.2 (A), U31.12 (Zc); also elsewhere on the board
/MAR/A6: D30.2 (A), U31.7 (Zb); also elsewhere on the board
/MAR/A7: D29.2 (A), U31.4 (Za); also elsewhere on the board
/MAR/HL: U29.6; also elsewhere on the board
/MAR/MI: U29.10; also elsewhere on the board
/MAR/STK: U29.3; also elsewhere on the board
/MAR/~PROG: D33.1 (K), R12.2, SW4.2, U4.9, U30.1 (S), U31.1 (S); also elsewhere on the board
/~CLR: U32.1 (Mr); also elsewhere on the board
GND: C17.2, C18.2, RN5.1 (common), SW4.1, SW5.9, SW5.10, SW5.13, SW5.14, SW5.15, SW5.16, SW5.17, SW5.18, SW5.19, SW5.20, U4.7 (GND), U29.7 (GND), U30.8 (GND), U30.15 (E), U31.8 (GND), U31.15 (E), U32.10 (GND); also elsewhere on the board
unnamed: C17.1, TP15.1, U29.8, U32.11 (Cp)
unnamed: D29.1 (K), RN5.9 (R8)
unnamed: D30.1 (K), RN5.8 (R7)
unnamed: D31.1 (K), RN5.7 (R6)
unnamed: D32.1 (K), RN5.6 (R5)
unnamed: D33.2 (A), R13.1
unnamed: D34.1 (K), RN5.5 (R4)
unnamed: D35.1 (K), RN5.4 (R3)
unnamed: D36.1 (K), RN5.3 (R2)
unnamed: D37.1 (K), RN5.2 (R1)
unnamed: R14.2, SW5.12, U29.4
unnamed: R15.2, SW5.11, U29.1
unnamed: SW5.1, U31.2 (I0a)
unnamed: SW5.2, U30.11 (I0d)
unnamed: SW5.3, U30.14 (I0c)
unnamed: SW5.4, U30.5 (I0b)
unnamed: SW5.5, U30.2 (I0a)
unnamed: SW5.6, U31.11 (I0d)
unnamed: SW5.7, U31.14 (I0c)
unnamed: SW5.8, U31.5 (I0b)
unnamed: U4.8, U29.2, U29.5
unnamed: U30.3 (I1a), U32.9 (Q3)
unnamed: U30.6 (I1b), U32.6 (Q2)
unnamed: U30.10 (I1d), U32.2 (Q0)
unnamed: U30.13 (I1c), U32.5 (Q1)
unnamed: U31.3 (I1a), U32.19 (Q7)
unnamed: U31.6 (I1b), U32.16 (Q6)
unnamed: U31.10 (I1d), U32.12 (Q4)
unnamed: U31.13 (I1c), U32.15 (Q5)
VCC: C18.1, R12.1, R13.2, R14.1, R15.1, U4.14 (VCC), U29.14 (VCC), U30.16 (VCC), U31.16 (VCC), U32.20 (VCC); also elsewhere on the board

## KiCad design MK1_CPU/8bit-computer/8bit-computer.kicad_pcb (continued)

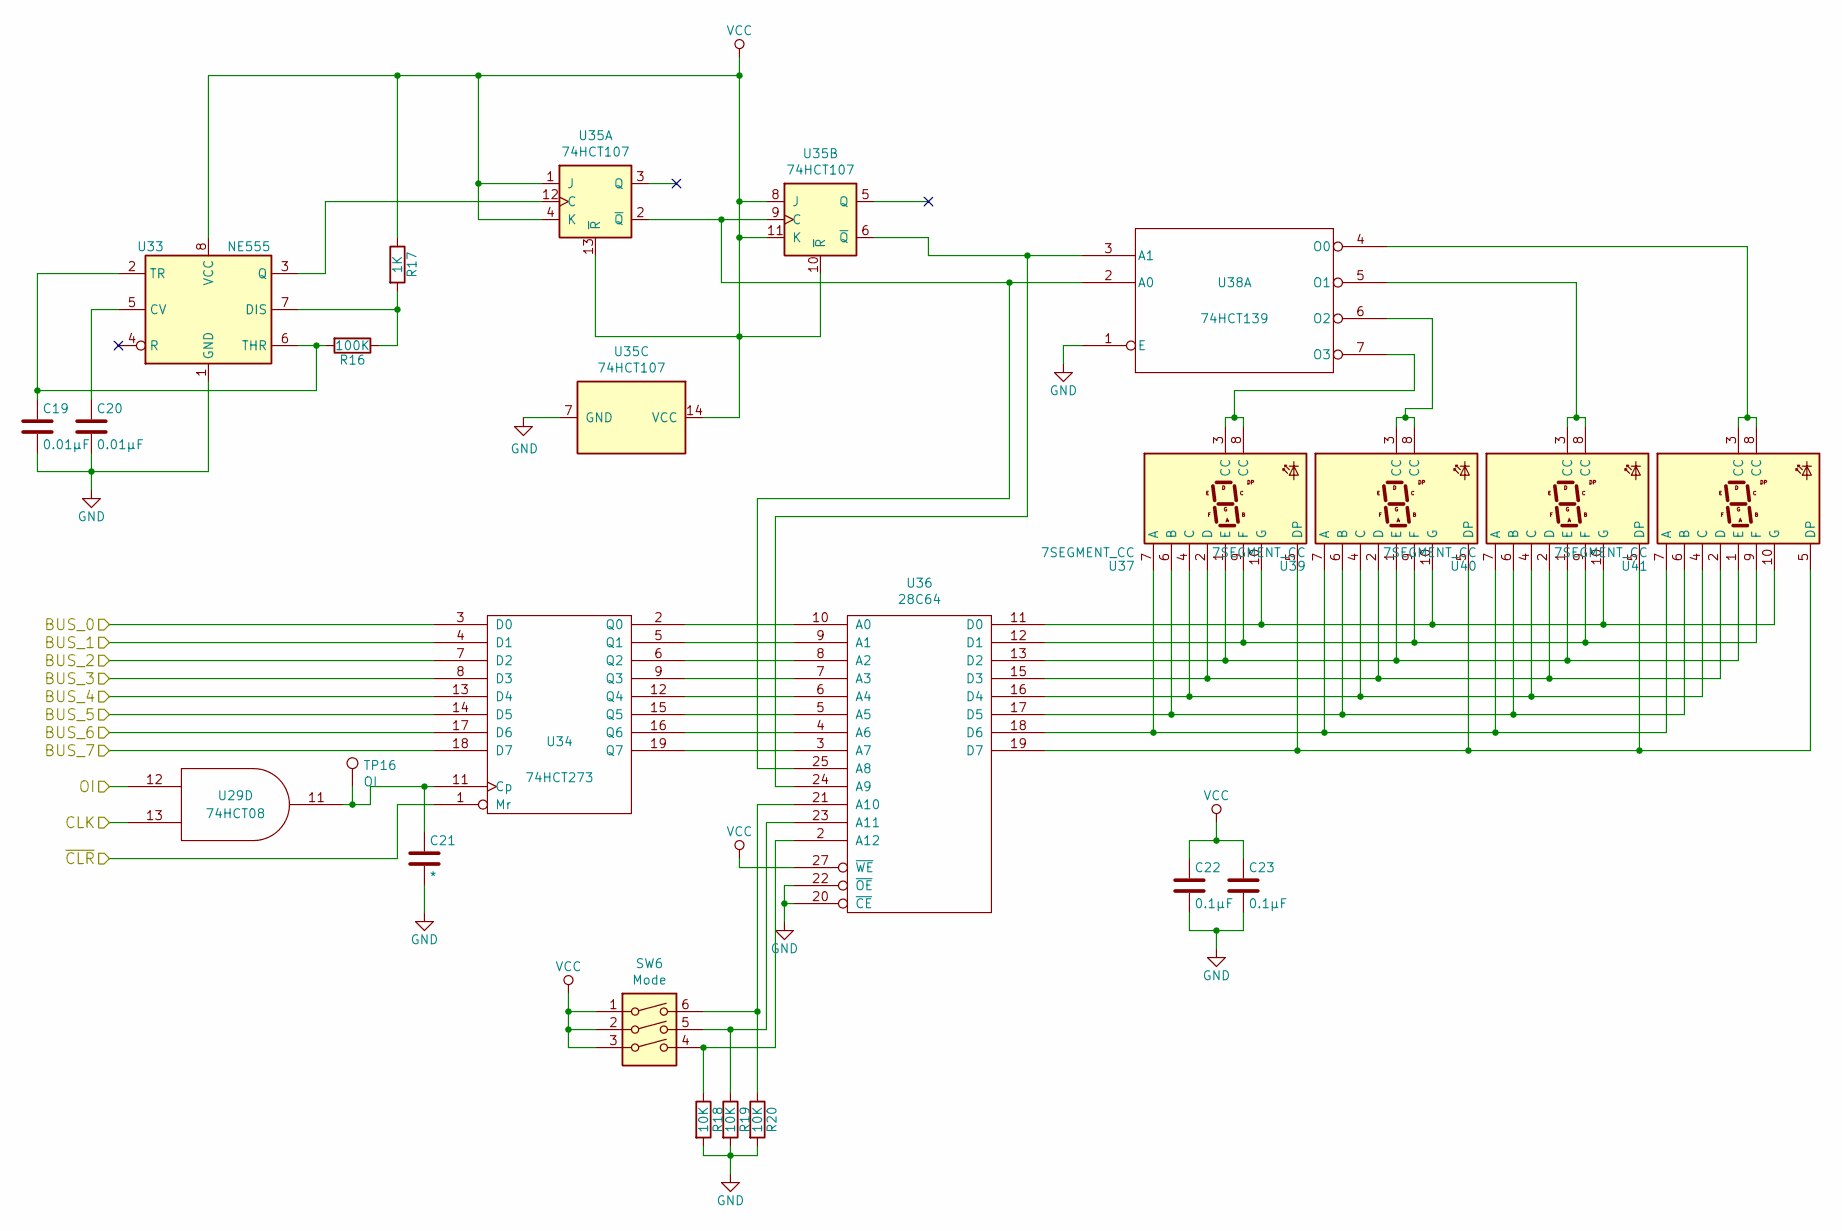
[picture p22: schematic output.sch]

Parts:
C19, C20: 0.01µF; C_Disc_D4.3mm_W1.9mm_P5.00mm
C21: *; C_Disc_D4.3mm_W1.9mm_P5.00mm
C22, C23: 0.1µF; C_Disc_D4.3mm_W1.9mm_P5.00mm
R16: 100K; R_Axial_DIN0207_L6.3mm_D2.5mm_P7.62mm_Horizontal
R17: 1K; R_Axial_DIN0207_L6.3mm_D2.5mm_P7.62mm_Horizontal
R18, R19, R20: 10K; R_Axial_DIN0207_L6.3mm_D2.5mm_P7.62mm_Horizontal
SW6: Mode; SW_DIP_SPSTx03_Slide_9.78x9.8mm_W7.62mm_P2.54mm
TP16: OI; TestPoint_Pad_1.0x1.0mm
U29: 74HCT08; DIP-14_W7.62mm
U33: NE555; DIP-8_W7.62mm
U34: 74HCT273; DIP-20_W7.62mm
U35: 74HCT107; DIP-14_W7.62mm
U36: 28C64; DIP-28_W15.24mm_Socket
U37, U39, U40, U41: 7SEGMENT_CC; 7SegmentLED_LTS6760_LTS6780
U38: 74HCT139; DIP-16_W7.62mm

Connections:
/BUS_0: U34.3 (D0); also elsewhere on the board
/BUS_1: U34.4 (D1); also elsewhere on the board
/BUS_2: U34.7 (D2); also elsewhere on the board
/BUS_3: U34.8 (D3); also elsewhere on the board
/BUS_4: U34.13 (D4); also elsewhere on the board
/BUS_5: U34.14 (D5); also elsewhere on the board
/BUS_6: U34.17 (D6); also elsewhere on the board
/BUS_7: U34.18 (D7); also elsewhere on the board
/CLK: U29.13; also elsewhere on the board
/Control logic/OI: U29.12; also elsewhere on the board
/~CLR: U34.1 (Mr); also elsewhere on the board
GND: C19.2, C20.2, C21.2, C22.2, C23.2, R18.2, R19.2, R20.2, U29.7 (GND), U33.1 (GND), U34.10 (GND), U35.7 (GND), U36.14 (GND), U36.20 (~CE), U36.22 (~OE), U38.1 (E), U38.8 (GND); also elsewhere on the board
unnamed: C19.1, R16.2, U33.2 (TR), U33.6 (THR)
unnamed: C20.1, U33.5 (CV)
unnamed: C21.1, TP16.1, U29.11, U34.11 (Cp)
unnamed: R16.1, R17.2, U33.7 (DIS)
unnamed: R18.1, SW6.4, U36.2 (A12)
unnamed: R19.1, SW6.5, U36.23 (A11)
unnamed: R20.1, SW6.6, U36.21 (A10)
unnamed: U33.3 (Q), U35.12 (C)
unnamed: U34.2 (Q0), U36.10 (A0)
unnamed: U34.5 (Q1), U36.9 (A1)
unnamed: U34.6 (Q2), U36.8 (A2)
unnamed: U34.9 (Q3), U36.7 (A3)
unnamed: U34.12 (Q4), U36.6 (A4)
unnamed: U34.15 (Q5), U36.5 (A5)
unnamed: U34.16 (Q6), U36.4 (A6)
unnamed: U34.19 (Q7), U36.3 (A7)
unnamed: U35.2 (~Q), U35.9 (C), U36.25 (A8), U38.2 (A0)
unnamed: U35.6 (~Q), U36.24 (A9), U38.3 (A1)
unnamed: U36.11 (D0), U37.10 (G), U39.10 (G), U40.10 (G), U41.10 (G)
unnamed: U36.12 (D1), U37.9 (F), U39.9 (F), U40.9 (F), U41.9 (F)
unnamed: U36.13 (D2), U37.1 (E), U39.1 (E), U40.1 (E), U41.1 (E)
unnamed: U36.15 (D3), U37.2 (D), U39.2 (D), U40.2 (D), U41.2 (D)
unnamed: U36.16 (D4), U37.4 (C), U39.4 (C), U40.4 (C), U41.4 (C)
unnamed: U36.17 (D5), U37.6 (B), U39.6 (B), U40.6 (B), U41.6 (B)
unnamed: U36.18 (D6), U37.7 (A), U39.7 (A), U40.7 (A), U41.7 (A)
unnamed: U36.19 (D7), U37.5 (DP), U39.5 (DP), U40.5 (DP), U41.5 (DP)
unnamed: U37.3 (CC), U37.8 (CC), U38.7 (O3)
unnamed: U38.4 (O0), U41.3 (CC), U41.8 (CC)
unnamed: U38.5 (O1), U40.3 (CC), U40.8 (CC)
unnamed: U38.6 (O2), U39.3 (CC), U39.8 (CC)
VCC: C22.1, C23.1, R17.1, SW6.1, SW6.2, SW6.3, U29.14 (VCC), U33.8 (VCC), U34.20 (VCC), U35.1 (J), U35.4 (K), U35.8 (J), U35.10 (~R), U35.11 (K), U35.13 (~R), U35.14 (VCC), U36.27 (~WE), U36.28 (VCC), U38.16 (VCC); also elsewhere on the board

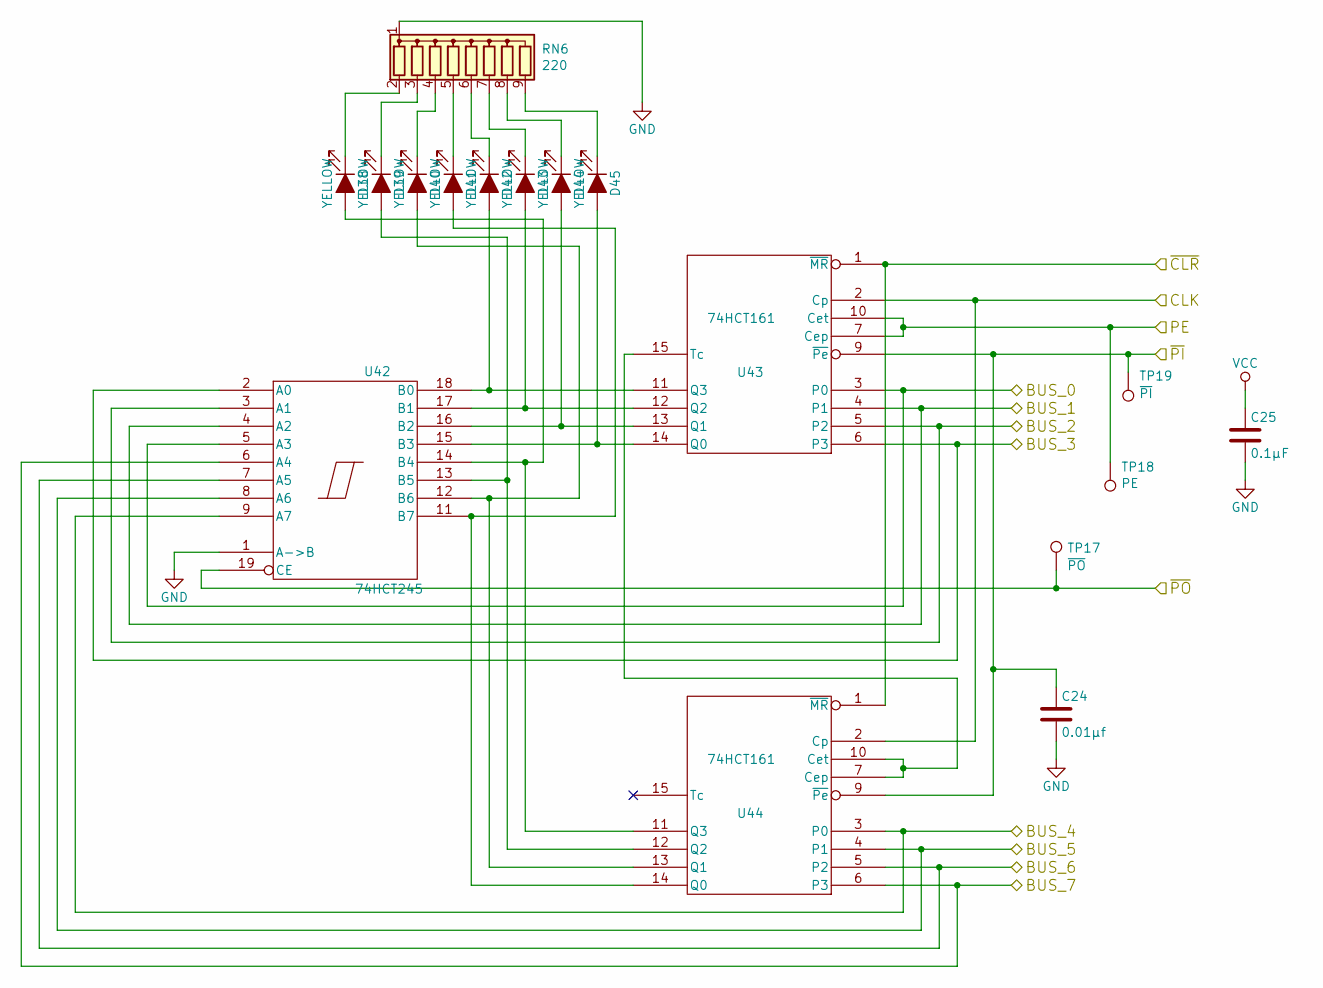
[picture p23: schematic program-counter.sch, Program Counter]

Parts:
C24: 0.01µf; C_Disc_D4.3mm_W1.9mm_P5.00mm
C25: 0.1µF; C_Disc_D4.3mm_W1.9mm_P5.00mm
D38, D39, D40, D41, D42, D43, D44, D45: YELLOW; LED_D3.0mm
RN6: 220; R_Array_SIP9
TP17: ~PO; TestPoint_Pad_1.0x1.0mm
TP18: PE; TestPoint_Pad_1.0x1.0mm
TP19: ~PI; TestPoint_Pad_1.0x1.0mm
U42: 74HCT245; DIP-20_W7.62mm
U43, U44: 74HCT161; DIP-16_W7.62mm

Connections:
/BUS_0: U42.5 (A3), U43.3 (P0); also elsewhere on the board
/BUS_1: U42.4 (A2), U43.4 (P1); also elsewhere on the board
/BUS_2: U42.3 (A1), U43.5 (P2); also elsewhere on the board
/BUS_3: U42.2 (A0), U43.6 (P3); also elsewhere on the board
/BUS_4: U42.9 (A7), U44.3 (P0); also elsewhere on the board
/BUS_5: U42.8 (A6), U44.4 (P1); also elsewhere on the board
/BUS_6: U42.7 (A5), U44.5 (P2); also elsewhere on the board
/BUS_7: U42.6 (A4), U44.6 (P3); also elsewhere on the board
/CLK: U43.2 (Cp), U44.2 (Cp); also elsewhere on the board
/Control logic/PE: TP18.1, U43.7 (Cep), U43.10 (Cet); also elsewhere on the board
/Control logic/~PI: C24.1, TP19.1, U43.9 (~Pe), U44.9 (~Pe); also elsewhere on the board
/Control logic/~PO: TP17.1, U42.19 (CE); also elsewhere on the board
/~CLR: U43.1 (~MR), U44.1 (~MR); also elsewhere on the board
GND: C24.2, C25.2, RN6.1 (common), U42.1 (A->B), U42.10 (GND), U43.8 (GND), U44.8 (GND); also elsewhere on the board
unnamed: D38.1 (K), RN6.2 (R1)
unnamed: D38.2 (A), U42.14 (B4), U44.11 (Q3)
unnamed: D39.1 (K), RN6.3 (R2)
unnamed: D39.2 (A), U42.13 (B5), U44.12 (Q2)
unnamed: D40.1 (K), RN6.4 (R3)
unnamed: D40.2 (A), U42.12 (B6), U44.13 (Q1)
unnamed: D41.1 (K), RN6.5 (R4)
unnamed: D41.2 (A), U42.11 (B7), U44.14 (Q0)
unnamed: D42.1 (K), RN6.6 (R5)
unnamed: D42.2 (A), U42.18 (B0), U43.11 (Q3)
unnamed: D43.1 (K), RN6.7 (R6)
unnamed: D43.2 (A), U42.17 (B1), U43.12 (Q2)
unnamed: D44.1 (K), RN6.8 (R7)
unnamed: D44.2 (A), U42.16 (B2), U43.13 (Q1)
unnamed: D45.1 (K), RN6.9 (R8)
unnamed: D45.2 (A), U42.15 (B3), U43.14 (Q0)
unnamed: U43.15 (Tc), U44.7 (Cep), U44.10 (Cet)
VCC: C25.1, U42.20 (VCC), U43.16 (VCC), U44.16 (VCC); also elsewhere on the board

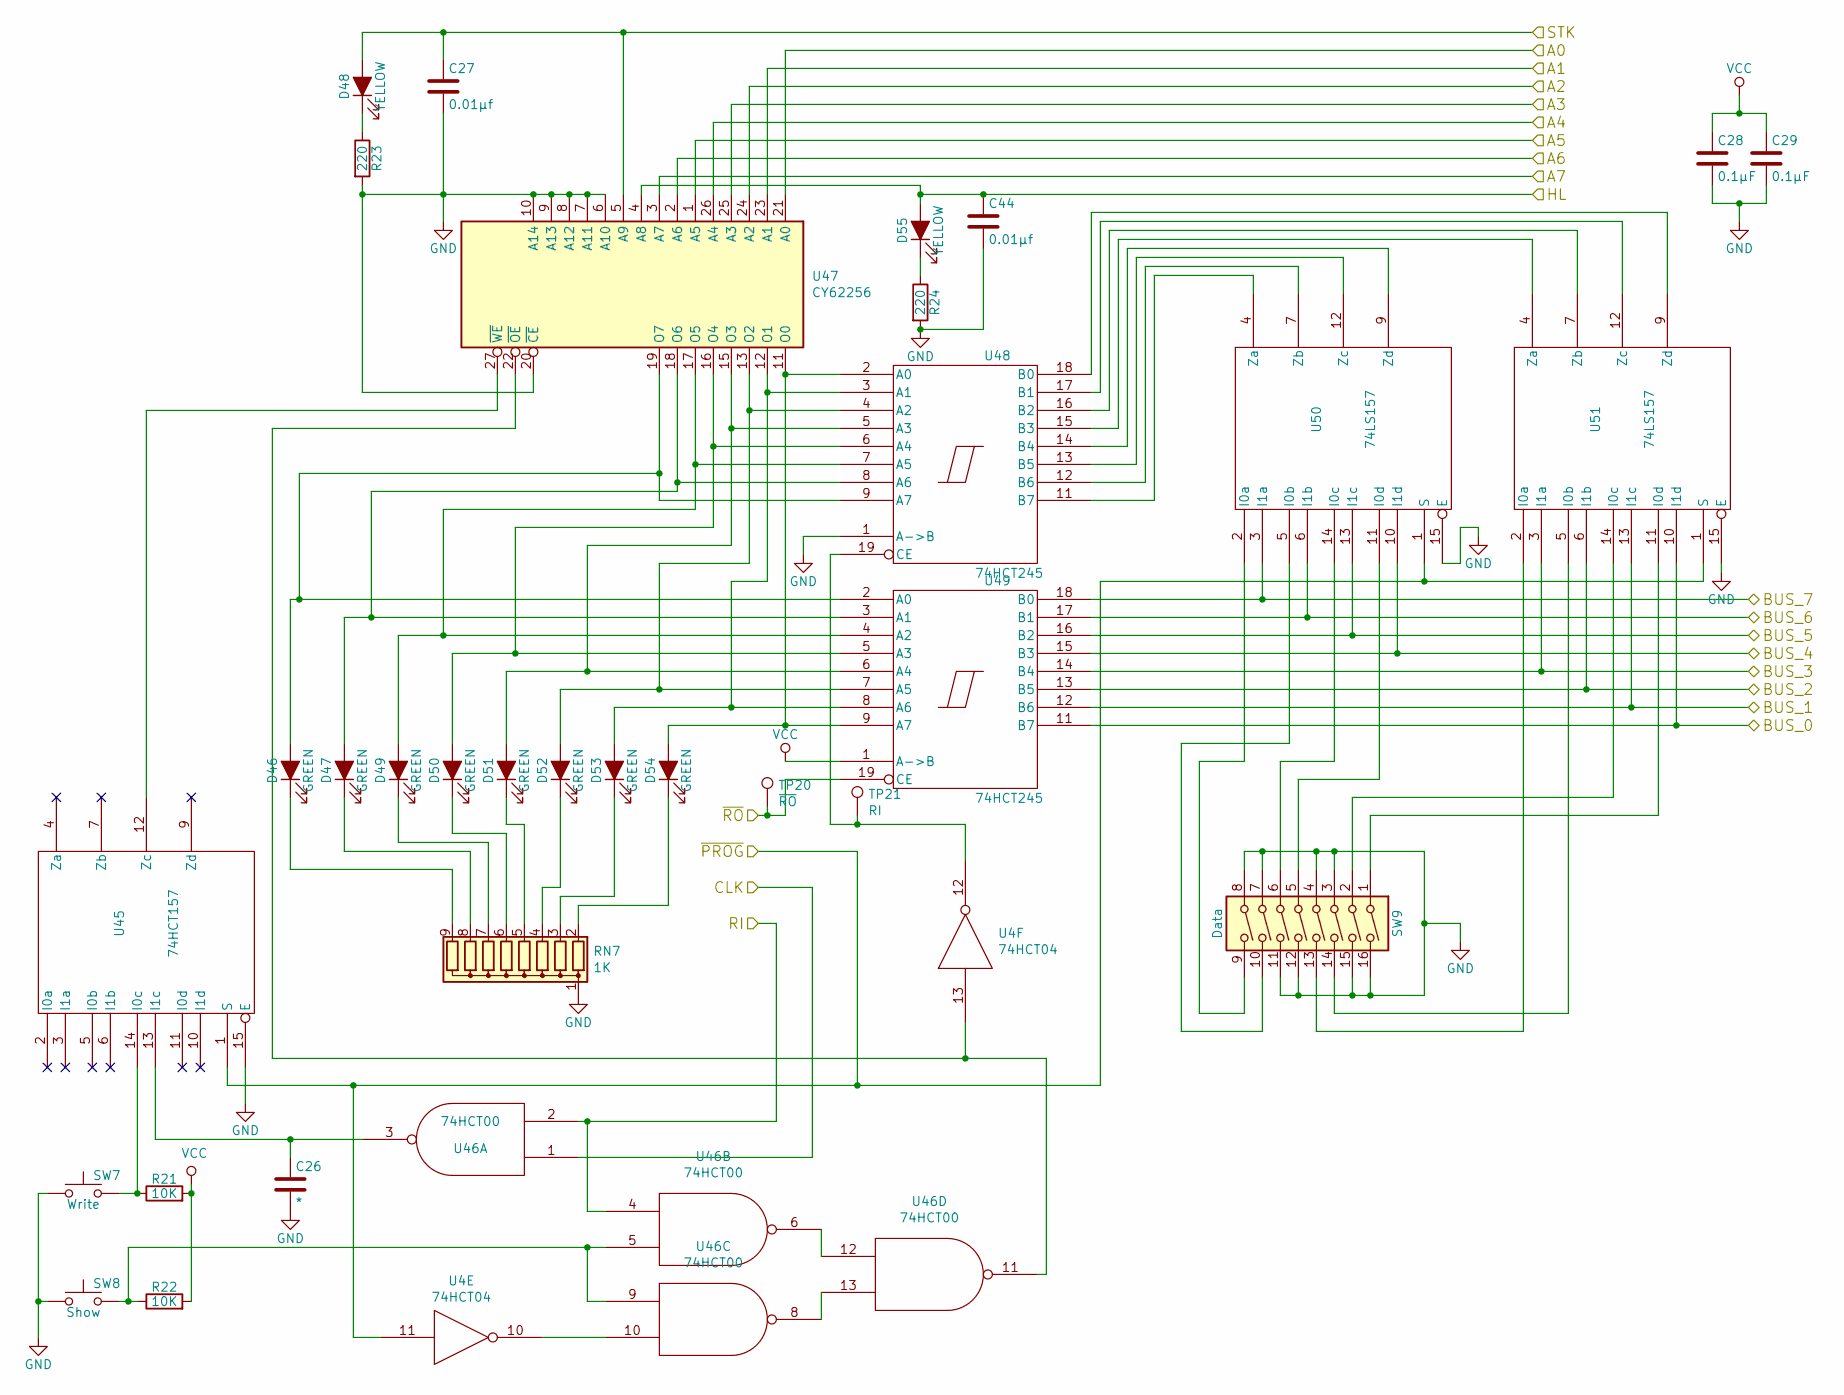
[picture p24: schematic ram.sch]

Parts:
C26: *; C_Disc_D4.3mm_W1.9mm_P5.00mm
C27, C44: 0.01µf; C_Disc_D4.3mm_W1.9mm_P5.00mm
C28, C29: 0.1µF; C_Disc_D4.3mm_W1.9mm_P5.00mm
D46, D47, D49, D50, D51, D52, D53, D54: GREEN; LED_D3.0mm
D48, D55: YELLOW; LED_D3.0mm
R21, R22: 10K; R_Axial_DIN0207_L6.3mm_D2.5mm_P7.62mm_Horizontal
R23, R24: 220; R_Axial_DIN0207_L6.3mm_D2.5mm_P7.62mm_Horizontal
RN7: 1K; R_Array_SIP9
SW7: Write; SW_PUSH_6mm_H5mm
SW8: Show; SW_PUSH_6mm_H5mm
SW9: Data; SW_DIP_SPSTx08_Slide_9.78x22.5mm_W7.62mm_P2.54mm
TP20: ~RO; TestPoint_Pad_1.0x1.0mm
TP21: RI; TestPoint_Pad_1.0x1.0mm
U4: 74HCT04; DIP-14_W7.62mm
U45: 74HCT157; DIP-16_W7.62mm
U46: 74HCT00; DIP-14_W7.62mm
U47: CY62256; DIP-28_W15.24mm_Socket
U48, U49: 74HCT245; DIP-20_W7.62mm
U50, U51: 74LS157; DIP-16_W7.62mm

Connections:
/BUS_0: U49.11 (B7), U51.10 (I1d); also elsewhere on the board
/BUS_1: U49.12 (B6), U51.13 (I1c); also elsewhere on the board
/BUS_2: U49.13 (B5), U51.6 (I1b); also elsewhere on the board
/BUS_3: U49.14 (B4), U51.3 (I1a); also elsewhere on the board
/BUS_4: U49.15 (B3), U50.10 (I1d); also elsewhere on the board
/BUS_5: U49.16 (B2), U50.13 (I1c); also elsewhere on the board
/BUS_6: U49.17 (B1), U50.6 (I1b); also elsewhere on the board
/BUS_7: U49.18 (B0), U50.3 (I1a); also elsewhere on the board
/CLK: U46.1; also elsewhere on the board
/Control logic/~RO: TP20.1, U49.19 (CE); also elsewhere on the board
/MAR/A0: U47.21 (A0); also elsewhere on the board
/MAR/A1: U47.23 (A1); also elsewhere on the board
/MAR/A2: U47.24 (A2); also elsewhere on the board
/MAR/A3: U47.25 (A3); also elsewhere on the board
/MAR/A4: U47.26 (A4); also elsewhere on the board
/MAR/A5: U47.1 (A5); also elsewhere on the board
/MAR/A6: U47.2 (A6); also elsewhere on the board
/MAR/A7: U47.3 (A7); also elsewhere on the board
/MAR/~PROG: U4.11, U45.1 (S), U50.1 (S), U51.1 (S); also elsewhere on the board
/RAM/HL: C44.1, D55.2 (A), U47.4 (A8); also elsewhere on the board
/RAM/RI: U46.2, U46.4; also elsewhere on the board
/RAM/STK: C27.1, D48.2 (A), U47.5 (A9); also elsewhere on the board
GND: C26.2, C27.2, C28.2, C29.2, C44.2, R23.2, R24.2, RN7.1 (common), SW7.1, SW8.1, SW9.3, SW9.4, SW9.7, SW9.8, SW9.11, SW9.12, SW9.15, SW9.16, U4.7 (GND), U45.8 (GND), U45.15 (E), U46.7 (GND), U47.6 (A10), U47.7 (A11), U47.8 (A12), U47.9 (A13), U47.10 (A14), U47.14 (GND), U47.20 (~CE~), U48.1 (A->B), U48.10 (GND), U49.10 (GND), U50.8 (GND), U50.15 (E), U51.8 (GND), U51.15 (E); also elsewhere on the board
unnamed: C26.1, U45.13 (I1c), U46.3
unnamed: D46.1 (K), RN7.9 (R8)
unnamed: D46.2 (A), U47.19 (O7), U48.9 (A7), U49.2 (A0)
unnamed: D47.1 (K), RN7.8 (R7)
unnamed: D47.2 (A), U47.18 (O6), U48.8 (A6), U49.3 (A1)
unnamed: D48.1 (K), R23.1
unnamed: D49.1 (K), RN7.7 (R6)
unnamed: D49.2 (A), U47.17 (O5), U48.7 (A5), U49.4 (A2)
unnamed: D50.1 (K), RN7.6 (R5)
unnamed: D50.2 (A), U47.16 (O4), U48.6 (A4), U49.5 (A3)
unnamed: D51.1 (K), RN7.5 (R4)
unnamed: D51.2 (A), U47.15 (O3), U48.5 (A3), U49.6 (A4)
unnamed: D52.1 (K), RN7.4 (R3)
unnamed: D52.2 (A), U47.13 (O2), U48.4 (A2), U49.7 (A5)
unnamed: D53.1 (K), RN7.3 (R2)
unnamed: D53.2 (A), U47.12 (O1), U48.3 (A1), U49.8 (A6)
unnamed: D54.1 (K), RN7.2 (R1)
unnamed: D54.2 (A), U47.11 (O0), U48.2 (A0), U49.9 (A7)
unnamed: D55.1 (K), R24.1
unnamed: R21.1, SW7.2, U45.14 (I0c)
unnamed: R22.1, SW8.2, U46.5, U46.9
unnamed: SW9.1, U51.11 (I0d)
unnamed: SW9.2, U51.14 (I0c)
unnamed: SW9.5, U50.11 (I0d)
unnamed: SW9.6, U50.14 (I0c)
unnamed: SW9.9, U50.2 (I0a)
unnamed: SW9.10, U50.5 (I0b)
unnamed: SW9.13, U51.2 (I0a)
unnamed: SW9.14, U51.5 (I0b)
unnamed: TP21.1, U4.12, U48.19 (CE)
unnamed: U4.10, U46.10
unnamed: U4.13, U46.11, U47.22 (~OE~)
unnamed: U45.12 (Zc), U47.27 (~WE~)
unnamed: U46.6, U46.12
unnamed: U46.8, U46.13
unnamed: U48.11 (B7), U50.4 (Za)
unnamed: U48.12 (B6), U50.7 (Zb)
unnamed: U48.13 (B5), U50.12 (Zc)
unnamed: U48.14 (B4), U50.9 (Zd)
unnamed: U48.15 (B3), U51.4 (Za)
unnamed: U48.16 (B2), U51.7 (Zb)
unnamed: U48.17 (B1), U51.12 (Zc)
unnamed: U48.18 (B0), U51.9 (Zd)
VCC: C28.1, C29.1, R21.2, R22.2, U4.14 (VCC), U45.16 (VCC), U46.14 (VCC), U47.28 (VCC), U48.20 (VCC), U49.1 (A->B), U49.20 (VCC), U50.16 (VCC), U51.16 (VCC); also elsewhere on the board

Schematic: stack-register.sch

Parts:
C30: 0.1µF; C_Disc_D4.3mm_W1.9mm_P5.00mm
C31, C32, C33: *; C_Disc_D4.3mm_W1.9mm_P5.00mm
D56, D57, D58, D59, D60, D61, D62, D63: YELLOW; LED_D3.0mm
RN8: 220; R_Array_SIP9
TP22: ~SO; TestPoint_Pad_1.0x1.0mm
TP23: SU; TestPoint_Pad_1.0x1.0mm
TP24: SD; TestPoint_Pad_1.0x1.0mm
TP25: SI; TestPoint_Pad_1.0x1.0mm
U52: 74HCT245; DIP-20_W7.62mm
U53, U54: 74HCT193; DIP-16_W7.62mm
U55: 74HCT00; DIP-14_W7.62mm

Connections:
/BUS_0: U52.11 (B7), U54.15 (A); also elsewhere on the board
/BUS_1: U52.12 (B6), U54.1 (B); also elsewhere on the board
/BUS_2: U52.13 (B5), U54.10 (C); also elsewhere on the board
/BUS_3: U52.14 (B4), U54.9 (D); also elsewhere on the board
/BUS_4: U52.15 (B3), U53.15 (A); also elsewhere on the board
/BUS_5: U52.16 (B2), U53.1 (B); also elsewhere on the board
/BUS_6: U52.17 (B1), U53.10 (C); also elsewhere on the board
/BUS_7: U52.18 (B0), U53.9 (D); also elsewhere on the board
/CLK: U55.2, U55.5, U55.10; also elsewhere on the board
/CLR: U53.14 (CLR), U54.14 (CLR); also elsewhere on the board
/Control logic/SD: U55.4; also elsewhere on the board
/Control logic/SI: U55.9; also elsewhere on the board
/Control logic/SU: U55.1; also elsewhere on the board
/Control logic/~SO: TP22.1, U52.19 (CE); also elsewhere on the board
GND: C30.2, C31.2, C32.2, C33.2, RN8.1 (common), U52.10 (GND), U53.8 (GND), U54.8 (GND), U55.7 (GND); also elsewhere on the board
unnamed: C31.1, TP24.1, U54.4 (DOWN), U55.6
unnamed: C32.1, TP23.1, U54.5 (UP), U55.3
unnamed: C33.1, TP25.1, U53.11 (~LOAD), U54.11 (~LOAD), U55.8
unnamed: D56.1 (K), RN8.9 (R8)
unnamed: D56.2 (A), U52.2 (A0), U53.7 (QD)
unnamed: D57.1 (K), RN8.8 (R7)
unnamed: D57.2 (A), U52.3 (A1), U53.6 (QC)
unnamed: D58.1 (K), RN8.7 (R6)
unnamed: D58.2 (A), U52.4 (A2), U53.2 (QB)
unnamed: D59.1 (K), RN8.6 (R5)
unnamed: D59.2 (A), U52.5 (A3), U53.3 (QA)
unnamed: D60.1 (K), RN8.5 (R4)
unnamed: D60.2 (A), U52.6 (A4), U54.7 (QD)
unnamed: D61.1 (K), RN8.4 (R3)
unnamed: D61.2 (A), U52.7 (A5), U54.6 (QC)
unnamed: D62.1 (K), RN8.3 (R2)
unnamed: D62.2 (A), U52.8 (A6), U54.2 (QB)
unnamed: D63.1 (K), RN8.2 (R1)
unnamed: D63.2 (A), U52.9 (A7), U54.3 (QA)
unnamed: U53.4 (DOWN), U54.13 (~BO)
unnamed: U53.5 (UP), U54.12 (~CO)
VCC: C30.1, U52.1 (A->B), U52.20 (VCC), U53.16 (VCC), U54.16 (VCC), U55.14 (VCC); also elsewhere on the board

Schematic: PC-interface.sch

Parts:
A1: Arduino Nano; Arduino_Nano
JP1: Arduino_VIN; SolderJumper-2_P1.3mm_Bridged_RoundedPad1.0x1.5mm
RN10: 1K; R_Array_SIP9
U59: 74HCT245; DIP-20_W7.62mm
U60: 74HCT04; DIP-14_W7.62mm

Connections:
/BUS_0: U59.18 (B0); also elsewhere on the board
/BUS_1: U59.17 (B1); also elsewhere on the board
/BUS_2: U59.16 (B2); also elsewhere on the board
/BUS_3: U59.15 (B3); also elsewhere on the board
/BUS_4: U59.14 (B4); also elsewhere on the board
/BUS_5: U59.13 (B5); also elsewhere on the board
/BUS_6: U59.12 (B6); also elsewhere on the board
/BUS_7: U59.11 (B7); also elsewhere on the board
/Clock/CLK_IN: A1.19 (A0), RN10.5 (R4); also elsewhere on the board
/PC Interface/CLR: A1.20 (A1), RN10.4 (R3); also elsewhere on the board
/PC Interface/CU_DIS: A1.21 (A2), RN10.3 (R2); also elsewhere on the board
/PC Interface/HL: A1.14 (D11), RN10.8 (R7); also elsewhere on the board
/PC Interface/MI: A1.13 (D10), RN10.7 (R6); also elsewhere on the board
/PC Interface/RI: A1.15 (D12), RN10.9 (R8); also elsewhere on the board
GND: A1.4 (GND), A1.29 (GND), RN10.1 (common), U59.10 (GND), U60.7 (GND); also elsewhere on the board
unnamed: A1.5 (D2), U59.2 (A0)
unnamed: A1.6 (D3), U59.3 (A1)
unnamed: A1.7 (D4), U59.4 (A2)
unnamed: A1.8 (D5), U59.5 (A3)
unnamed: A1.9 (D6), U59.6 (A4)
unnamed: A1.10 (D7), U59.7 (A5)
unnamed: A1.11 (D8), U59.8 (A6)
unnamed: A1.12 (D9), U59.9 (A7)
unnamed: A1.16 (D13), RN10.6 (R5), U60.1
unnamed: A1.30 (VIN), JP1.1 (A)
unnamed: U59.19 (CE), U60.2
VCC: JP1.2 (B), U59.1 (A->B), U59.20 (VCC), U60.14 (VCC); also elsewhere on the board

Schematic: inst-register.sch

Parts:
C36: 0.1µF; C_Disc_D4.3mm_W1.9mm_P5.00mm
D72, D73, D74, D75, D76, D77, D78, D79: BLUE; LED_D3.0mm
RN11: 1K; R_Array_SIP9
TP28: II; TestPoint_Pad_1.0x1.0mm
U58: 74HCT08; DIP-14_W7.62mm
U61: 74HCT273; DIP-20_W7.62mm

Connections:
/BUS_0: U61.3 (D0); also elsewhere on the board
/BUS_1: U61.4 (D1); also elsewhere on the board
/BUS_2: U61.7 (D2); also elsewhere on the board
/BUS_3: U61.8 (D3); also elsewhere on the board
/BUS_4: U61.13 (D4); also elsewhere on the board
/BUS_5: U61.14 (D5); also elsewhere on the board
/BUS_6: U61.17 (D6); also elsewhere on the board
/BUS_7: U61.18 (D7); also elsewhere on the board
/CLK: U58.1; also elsewhere on the board
/Control logic/CI: U58.2; also elsewhere on the board
/Control logic/II: U58.5; also elsewhere on the board
/IR_0: D79.2 (A), U61.2 (Q0); also elsewhere on the board
/IR_1: D78.2 (A), U61.5 (Q1); also elsewhere on the board
/IR_2: D77.2 (A), U61.6 (Q2); also elsewhere on the board
/IR_3: D76.2 (A), U61.9 (Q3); also elsewhere on the board
/IR_4: D75.2 (A), U61.12 (Q4); also elsewhere on the board
/IR_5: D74.2 (A), U61.15 (Q5); also elsewhere on the board
/IR_6: D73.2 (A), U61.16 (Q6); also elsewhere on the board
/IR_7: D72.2 (A), U61.19 (Q7); also elsewhere on the board
/~CLK: U58.4; also elsewhere on the board
/~CLR: U61.1 (Mr); also elsewhere on the board
GND: C36.2, RN11.1 (common), U58.7 (GND), U61.10 (GND); also elsewhere on the board
unnamed 157: U58.3; also elsewhere on the board
unnamed: D72.1 (K), RN11.9 (R8)
unnamed: D73.1 (K), RN11.8 (R7)
unnamed: D74.1 (K), RN11.7 (R6)
unnamed: D75.1 (K), RN11.6 (R5)
unnamed: D76.1 (K), RN11.5 (R4)
unnamed: D77.1 (K), RN11.4 (R3)
unnamed: D78.1 (K), RN11.3 (R2)
unnamed: D79.1 (K), RN11.2 (R1)
unnamed: TP28.1, U58.6, U61.11 (Cp)
VCC: C36.1, U58.14 (VCC), U61.20 (VCC); also elsewhere on the board

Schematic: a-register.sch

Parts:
C37: 0.1µF; C_Disc_D4.3mm_W1.9mm_P5.00mm
C38: *; C_Disc_D4.3mm_W1.9mm_P5.00mm
D80, D81, D82, D83, D84, D85, D86, D87: GREEN; LED_D3.0mm
RN12: 1K; R_Array_SIP9
TP29: AI; TestPoint_Pad_1.0x1.0mm
TP30: ~AO; TestPoint_Pad_1.0x1.0mm
TP31: RGT; TestPoint_Pad_1.0x1.0mm
TP32: ROT; TestPoint_Pad_1.0x1.0mm
TP33: SHF; TestPoint_Pad_1.0x1.0mm
U28: 74HCT32; DIP-14_W7.62mm
U58, U64: 74HCT08; DIP-14_W7.62mm
U62, U63, U67, U68: 74HCT157; DIP-16_W7.62mm
U65: 74HCT245; DIP-20_W7.62mm
U66: 74HCT273; DIP-20_W7.62mm

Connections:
/A register/AI: U64.2; also elsewhere on the board
/A register/RGT: TP31.1, U62.1 (S), U63.1 (S); also elsewhere on the board
/A register/ROT: TP32.1, U28.10, U58.10, U58.12; also elsewhere on the board
/A register/SFT: TP33.1, U28.9; also elsewhere on the board
/A register/~AO: TP30.1, U65.19 (CE); also elsewhere on the board
/A_0: D87.2 (A), U58.13, U62.5 (I0b), U65.9 (A7), U66.9 (Q3); also elsewhere on the board
/A_1: D86.2 (A), U62.3 (I1a), U62.14 (I0c), U65.8 (A6), U66.6 (Q2); also elsewhere on the board
/A_2: D85.2 (A), U62.6 (I1b), U62.11 (I0d), U65.7 (A5), U66.5 (Q1); also elsewhere on the board
/A_3: D84.2 (A), U62.13 (I1c), U63.2 (I0a), U65.6 (A4), U66.2 (Q0); also elsewhere on the board
/A_4: D83.2 (A), U62.10 (I1d), U63.5 (I0b), U65.5 (A3), U66.19 (Q7); also elsewhere on the board
/A_5: D82.2 (A), U63.3 (I1a), U63.14 (I0c), U65.4 (A2), U66.16 (Q6); also elsewhere on the board
/A_6: D81.2 (A), U63.6 (I1b), U63.11 (I0d), U65.3 (A1), U66.15 (Q5); also elsewhere on the board
/A_7: D80.2 (A), U58.9, U63.13 (I1c), U65.2 (A0), U66.12 (Q4); also elsewhere on the board
/BUS_0: U65.11 (B7), U67.2 (I0a); also elsewhere on the board
/BUS_1: U65.12 (B6), U67.5 (I0b); also elsewhere on the board
/BUS_2: U65.13 (B5), U67.14 (I0c); also elsewhere on the board
/BUS_3: U65.14 (B4), U67.11 (I0d); also elsewhere on the board
/BUS_4: U65.15 (B3), U68.2 (I0a); also elsewhere on the board
/BUS_5: U65.16 (B2), U68.5 (I0b); also elsewhere on the board
/BUS_6: U65.17 (B1), U68.14 (I0c); also elsewhere on the board
/BUS_7: U65.18 (B0), U68.11 (I0d); also elsewhere on the board
/CLK: U58.1, U64.1; also elsewhere on the board
/Control logic/CI: U58.2; also elsewhere on the board
/~CLR: U66.1 (Mr); also elsewhere on the board
GND: C37.2, C38.2, RN12.1 (common), U28.7 (GND), U58.7 (GND), U62.8 (GND), U62.15 (E), U63.8 (GND), U63.15 (E), U64.7 (GND), U65.10 (GND), U66.10 (GND), U67.8 (GND), U67.15 (E), U68.8 (GND), U68.15 (E); also elsewhere on the board
unnamed 157: U58.3; also elsewhere on the board
unnamed: C38.1, TP29.1, U64.3, U66.11 (Cp)
unnamed: D80.1 (K), RN12.2 (R1)
unnamed: D81.1 (K), RN12.5 (R4)
unnamed: D82.1 (K), RN12.8 (R7)
unnamed: D83.1 (K), RN12.4 (R3)
unnamed: D84.1 (K), RN12.6 (R5)
unnamed: D85.1 (K), RN12.7 (R6)
unnamed: D86.1 (K), RN12.3 (R2)
unnamed: D87.1 (K), RN12.9 (R8)
unnamed: U28.8, U67.1 (S), U68.1 (S)
unnamed: U58.8, U62.2 (I0a)
unnamed: U58.11, U63.10 (I1d)
unnamed: U62.4 (Za), U67.3 (I1a)
unnamed: U62.7 (Zb), U67.6 (I1b)
unnamed: U62.9 (Zd), U67.10 (I1d)
unnamed: U62.12 (Zc), U67.13 (I1c)
unnamed: U63.4 (Za), U68.3 (I1a)
unnamed: U63.7 (Zb), U68.6 (I1b)
unnamed: U63.9 (Zd), U68.10 (I1d)
unnamed: U63.12 (Zc), U68.13 (I1c)
unnamed: U66.3 (D0), U67.9 (Zd)
unnamed: U66.4 (D1), U67.12 (Zc)
unnamed: U66.7 (D2), U67.7 (Zb)
unnamed: U66.8 (D3), U67.4 (Za)
unnamed: U66.13 (D4), U68.9 (Zd)
unnamed: U66.14 (D5), U68.12 (Zc)
unnamed: U66.17 (D6), U68.7 (Zb)
unnamed: U66.18 (D7), U68.4 (Za)
VCC: C37.1, U28.14 (VCC), U58.14 (VCC), U62.16 (VCC), U63.16 (VCC), U64.14 (VCC), U65.1 (A->B), U65.20 (VCC), U66.20 (VCC), U67.16 (VCC), U68.16 (VCC); also elsewhere on the board

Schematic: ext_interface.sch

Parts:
C45: 0.01µF; C_Disc_D4.3mm_W1.9mm_P5.00mm
D88, D89: WHITE; LED_D3.0mm
J4: EXT-CONN; PinHeader_2x09_P2.54mm_Vertical
R25, R26, R27, R28: 1K; R_Axial_DIN0207_L6.3mm_D2.5mm_P7.62mm_Horizontal
TP34: E0; TestPoint_Pad_1.0x1.0mm
TP35: EXT_IN; TestPoint_Pad_1.0x1.0mm
TP36: E1; TestPoint_Pad_1.0x1.0mm
TP37: U0; TestPoint_Pad_1.0x1.0mm
TP38: U1; TestPoint_Pad_1.0x1.0mm
U64: 74HCT08; DIP-14_W7.62mm
U69: 74HCT02; DIP-14_W7.62mm
U70: 74HCT245; DIP-20_W7.62mm
U71: 74HCT107; DIP-14_W7.62mm

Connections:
/BUS_0: U70.18 (B0); also elsewhere on the board
/BUS_1: U70.17 (B1); also elsewhere on the board
/BUS_2: U70.16 (B2); also elsewhere on the board
/BUS_3: U70.15 (B3); also elsewhere on the board
/BUS_4: U70.14 (B4); also elsewhere on the board
/BUS_5: U70.13 (B5); also elsewhere on the board
/BUS_6: U70.12 (B6); also elsewhere on the board
/BUS_7: U70.11 (B7); also elsewhere on the board
/CLK: J4.15, U71.9 (C), U71.12 (C); also elsewhere on the board
/CLR: J4.13, U69.6, U69.8; also elsewhere on the board
/Control logic/E0: J4.5, TP34.1, U64.10, U69.3; also elsewhere on the board
/Control logic/E1: J4.7, TP36.1, U64.5, U69.2; also elsewhere on the board
/Control logic/EXT_I: C45.1, TP35.1, U64.4, U64.9, U70.1 (A->B); also elsewhere on the board
/Control logic/IRQ0: D88.2 (A), U71.3 (Q); also elsewhere on the board
/Control logic/IRQ1: D89.2 (A), U71.5 (Q); also elsewhere on the board
/Control logic/U0: J4.9, TP37.1; also elsewhere on the board
/Control logic/U1: J4.11, TP38.1; also elsewhere on the board
GND: C45.2, J4.17, R25.1, R26.1, R27.2, R28.2, U64.7 (GND), U69.7 (GND), U70.10 (GND), U71.4 (K), U71.7 (GND), U71.11 (K); also elsewhere on the board
unnamed: D88.1 (K), R25.2
unnamed: D89.1 (K), R26.2
unnamed: J4.1, R27.1, U71.1 (J)
unnamed: J4.2, U70.2 (A0)
unnamed: J4.3, R28.1, U71.8 (J)
unnamed: J4.4, U70.3 (A1)
unnamed: J4.6, U70.4 (A2)
unnamed: J4.8, U70.5 (A3)
unnamed: J4.10, U70.6 (A4)
unnamed: J4.12, U70.7 (A5)
unnamed: J4.14, U70.8 (A6)
unnamed: J4.16, U70.9 (A7)
unnamed: U64.6, U69.5
unnamed: U64.8, U69.9
unnamed: U69.1, U70.19 (CE)
unnamed: U69.4, U71.10 (~R)
unnamed: U69.10, U71.13 (~R)
VCC: J4.18, U64.14 (VCC), U69.14 (VCC), U70.20 (VCC), U71.14 (VCC); also elsewhere on the board

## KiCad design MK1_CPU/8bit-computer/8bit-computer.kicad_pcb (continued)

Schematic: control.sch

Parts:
C39: 0.01µF; C_Disc_D4.3mm_W1.9mm_P5.00mm
C40, C41: 0.1µF; C_Disc_D4.3mm_W1.9mm_P5.00mm
D90, D91, D92: YELLOW; LED_D3.0mm
D93, D94, D95, D96, D97, D98, D99, D100, D101, D102, D103, D104, D105, D106, D107, D108, D109, D110, D111, D112, D113, D114, D115, D116, D117, D118, D119, D120, D121, D122, D123, D124, D125, D126: BLUE; LED_D3.0mm
R29, R30, R31, R32: 10K; R_Axial_DIN0207_L6.3mm_D2.5mm_P7.62mm_Horizontal
RN13, RN14, RN15, RN16, RN17, RN18, RN19: 1K; R_Array_SIP9
SW10: Reset; SW_PUSH_6mm_H5mm
TP39: ~CU_EN; TestPoint_Pad_1.0x1.0mm
U24: 74HCT86; DIP-14_W7.62mm
U60: 74HCT04; DIP-14_W7.62mm
U72: 74HCT161; DIP-16_W7.62mm
U73, U74, U75, U76: AM29F040; PLCC-32_THT-Socket
U77: 74HCT138; DIP-16_W7.62mm
U78, U79: 74HCT238; DIP-16_W7.62mm

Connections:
/A register/AI: D104.2 (A), U78.14 (Y1); also elsewhere on the board
/A register/RGT: U76.18 (D4); also elsewhere on the board
/A register/ROT: D94.2 (A), U79.10 (Y5); also elsewhere on the board
/A register/SFT: D126.2 (A), U79.11 (Y4); also elsewhere on the board
/A register/~AO: D106.1 (K), U77.14 (O1); also elsewhere on the board
/ALU/AND: D123.2 (A), U79.12 (Y3); also elsewhere on the board
/ALU/CF: U73.25 (A11), U74.25 (A11), U75.25 (A11), U76.25 (A11); also elsewhere on the board
/ALU/EI: D115.2 (A), U78.9 (Y6); also elsewhere on the board
/ALU/NOT: D125.2 (A), U79.7 (Y7); also elsewhere on the board
/ALU/OR: D124.2 (A), U79.13 (Y2); also elsewhere on the board
/ALU/SUB: D122.2 (A), U79.14 (Y1); also elsewhere on the board
/ALU/ZF: U73.4 (A12), U74.4 (A12), U75.4 (A12), U76.4 (A12); also elsewhere on the board
/ALU/~EO: D116.1 (K), U77.7 (O7); also elsewhere on the board
/ALU/~FI: U60.8; also elsewhere on the board
/CLR: U60.6; also elsewhere on the board
/Control logic/BI: D108.2 (A), U78.13 (Y2); also elsewhere on the board
/Control logic/CI: D111.2 (A), U78.12 (Y3); also elsewhere on the board
/Control logic/DI: D113.2 (A), U78.11 (Y4); also elsewhere on the board
/Control logic/E0: D103.2 (A), RN16.4 (R3), U76.21 (D7); also elsewhere on the board
/Control logic/E1: D105.2 (A), RN16.3 (R2), U76.20 (D6); also elsewhere on the board
/Control logic/EXT_I: RN15.2 (R1), U74.19 (D5); also elsewhere on the board
/Control logic/HL: RN16.2 (R1), U76.19 (D5); also elsewhere on the board
/Control logic/HLT: D93.2 (A), RN15.5 (R4), U73.21 (D7); also elsewhere on the board
/Control logic/II: D100.2 (A), U74.21 (D7); also elsewhere on the board
/Control logic/IRQ0: U73.28 (A13), U74.28 (A13), U75.28 (A13), U76.28 (A13); also elsewhere on the board
/Control logic/IRQ1: U73.29 (A14), U74.29 (A14), U75.29 (A14), U76.29 (A14); also elsewhere on the board
/Control logic/MI: D95.2 (A), RN15.3 (R2), U73.14 (D1); also elsewhere on the board
/Control logic/OI: D101.2 (A), R32.1, U74.20 (D6); also elsewhere on the board
/Control logic/PE: D121.2 (A), U73.19 (D5); also elsewhere on the board
/Control logic/RI: D96.2 (A), RN15.4 (R3), U73.13 (D0); also elsewhere on the board
/Control logic/SD: D99.2 (A), R30.1, U75.15 (D2); also elsewhere on the board
/Control logic/SI: D117.2 (A), U78.10 (Y5); also elsewhere on the board
/Control logic/STK: RN15.6 (R5), U73.20 (D6); also elsewhere on the board
/Control logic/SU: D97.2 (A), R31.1, U75.17 (D3); also elsewhere on the board
/Control logic/U0: D107.2 (A), U75.14 (D1); also elsewhere on the board
/Control logic/U1: D109.2 (A), U75.13 (D0); also elsewhere on the board
/Control logic/~BO: D110.1 (K), U77.13 (O2); also elsewhere on the board
/Control logic/~CO: D112.1 (K), U77.12 (O3); also elsewhere on the board
/Control logic/~DO: D114.1 (K), U77.11 (O4); also elsewhere on the board
/Control logic/~PI: U60.12; also elsewhere on the board
/Control logic/~PO: D120.1 (K), U77.10 (O5); also elsewhere on the board
/Control logic/~RO: U60.10; also elsewhere on the board
/Control logic/~SO: D118.1 (K), U77.9 (O6); also elsewhere on the board
/IR_0: U73.9 (A3), U74.9 (A3), U75.9 (A3), U76.9 (A3); also elsewhere on the board
/IR_1: U73.8 (A4), U74.8 (A4), U75.8 (A4), U76.8 (A4); also elsewhere on the board
/IR_2: U73.7 (A5), U74.7 (A5), U75.7 (A5), U76.7 (A5); also elsewhere on the board
/IR_3: U73.6 (A6), U74.6 (A6), U75.6 (A6), U76.6 (A6); also elsewhere on the board
/IR_4: U73.5 (A7), U74.5 (A7), U75.5 (A7), U76.5 (A7); also elsewhere on the board
/IR_5: U73.27 (A8), U74.27 (A8), U75.27 (A8), U76.27 (A8); also elsewhere on the board
/IR_6: U73.26 (A9), U74.26 (A9), U75.26 (A9), U76.26 (A9); also elsewhere on the board
/IR_7: U73.23 (A10), U74.23 (A10), U75.23 (A10), U76.23 (A10); also elsewhere on the board
/PC Interface/CLR: R29.1, SW10.1, U60.3; also elsewhere on the board
/PC Interface/CU_DIS: RN13.5 (R4), TP39.1, U73.24 (~OE~), U74.24 (~OE~), U75.24 (~OE~), U76.24 (~OE~); also elsewhere on the board
/~CLK: U72.2 (Cp); also elsewhere on the board
/~CLR: U24.5 (IN2), U60.4, U60.5; also elsewhere on the board
GND: C39.2, C40.2, C41.2, R29.2, R30.2, R31.2, R32.2, RN13.1 (common), RN14.1 (common), RN15.1 (common), RN16.1 (common), RN18.1 (common), RN19.1 (common), U24.7 (GND), U60.7 (GND), U72.8 (GND), U73.1 (A18), U73.2 (A16), U73.3 (A15), U73.16 (GND), U73.22 (~CE~), U73.30 (A17), U74.1 (A18), U74.2 (A16), U74.16 (GND), U74.22 (~CE~), U74.30 (A17), U75.1 (A18), U75.3 (A15), U75.16 (GND), U75.22 (~CE~), U75.30 (A17), U76.1 (A18), U76.16 (GND), U76.22 (~CE~), U76.30 (A17), U77.4 (E1), U77.5 (E2), U77.8 (GND), U78.4 (~G2A), U78.5 (~G2B), U78.8 (GND), U79.4 (~G2A), U79.5 (~G2B), U79.8 (GND); also elsewhere on the board
unnamed: C39.1, RN13.9 (R8), U24.4 (IN1), U76.13 (D0)
unnamed: D90.1 (K), RN13.2 (R1)
unnamed: D90.2 (A), U72.14 (Q0), U73.12 (A0), U74.12 (A0), U75.12 (A0), U76.12 (A0)
unnamed: D91.1 (K), RN13.3 (R2)
unnamed: D91.2 (A), U72.13 (Q1), U73.11 (A1), U74.11 (A1), U75.11 (A1), U76.11 (A1)
unnamed: D92.1 (K), RN13.4 (R3)
unnamed: D92.2 (A), U72.12 (Q2), U73.10 (A2), U74.10 (A2), U75.10 (A2), U76.10 (A2)
unnamed: D93.1 (K), RN14.9 (R8)
unnamed: D94.1 (K), RN13.6 (R5)
unnamed: D95.1 (K), RN14.8 (R7)
unnamed: D96.1 (K), RN14.7 (R6)
unnamed: D97.1 (K), RN13.7 (R6)
unnamed: D98.1 (K), RN14.6 (R5)
unnamed: D98.2 (A), RN16.6 (R5), U60.11, U74.14 (D1)
unnamed: D99.1 (K), RN19.9 (R8)
unnamed: D100.1 (K), RN14.5 (R4)
unnamed: D101.1 (K), RN19.8 (R7)
unnamed: D102.1 (K), RN14.4 (R3)
unnamed: D102.2 (A), U60.9, U75.18 (D4)
unnamed: D103.1 (K), RN19.7 (R6)
unnamed: D104.1 (K), RN14.3 (R2)
unnamed: D105.1 (K), RN19.6 (R5)
unnamed: D106.2 (A), RN17.9 (R8)
unnamed: D107.1 (K), RN19.5 (R4)
unnamed: D108.1 (K), RN14.2 (R1)
unnamed: D109.1 (K), RN19.4 (R3)
unnamed: D110.2 (A), RN17.8 (R7)
unnamed: D111.1 (K), RN18.6 (R5)
unnamed: D112.2 (A), RN17.7 (R6)
unnamed: D113.1 (K), RN18.5 (R4)
unnamed: D114.2 (A), RN17.6 (R5)
unnamed: D115.1 (K), RN18.4 (R3)
unnamed: D116.2 (A), RN17.5 (R4)
unnamed: D117.1 (K), RN18.3 (R2)
unnamed: D118.2 (A), RN17.4 (R3)
unnamed: D119.1 (K), RN13.8 (R7)
unnamed: D119.2 (A), U60.13, U78.7 (Y7)
unnamed: D120.2 (A), RN17.3 (R2)
unnamed: D121.1 (K), RN18.9 (R8)
unnamed: D122.1 (K), RN18.8 (R7)
unnamed: D123.1 (K), RN18.7 (R6)
unnamed: D124.1 (K), RN18.2 (R1)
unnamed: D125.1 (K), RN19.3 (R2)
unnamed: D126.1 (K), RN19.2 (R1)
unnamed: RN15.7 (R6), U73.15 (D2), U78.3 (A2)
unnamed: RN15.8 (R7), U73.17 (D3), U78.2 (A1)
unnamed: RN15.9 (R8), U73.18 (D4), U78.1 (A0)
unnamed: RN16.7 (R6), U74.18 (D4), U77.1 (A0)
unnamed: RN16.8 (R7), U74.17 (D3), U77.2 (A1)
unnamed: RN16.9 (R8), U74.15 (D2), U77.3 (A2)
unnamed: U24.6 (OUT), U72.1 (~MR)
unnamed: U75.19 (D5), U79.3 (A2)
unnamed: U75.20 (D6), U79.2 (A1)
unnamed: U75.21 (D7), U79.1 (A0)
VCC: C40.1, C41.1, RN17.1 (common), SW10.2, U24.14 (VCC), U60.14 (VCC), U72.7 (Cep), U72.9 (~Pe), U72.10 (Cet), U72.16 (VCC), U73.31 (~WE~), U73.32 (VCC), U74.3 (A15), U74.31 (~WE~), U74.32 (VCC), U75.2 (A16), U75.31 (~WE~), U75.32 (VCC), U76.2 (A16), U76.3 (A15), U76.31 (~WE~), U76.32 (VCC), U77.6 (E3), U77.16 (VCC), U78.6 (G1), U78.16 (VCC), U79.6 (G1), U79.16 (VCC); also elsewhere on the board

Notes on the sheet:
SUB
AND
NOT
SHF
ROT
HLT

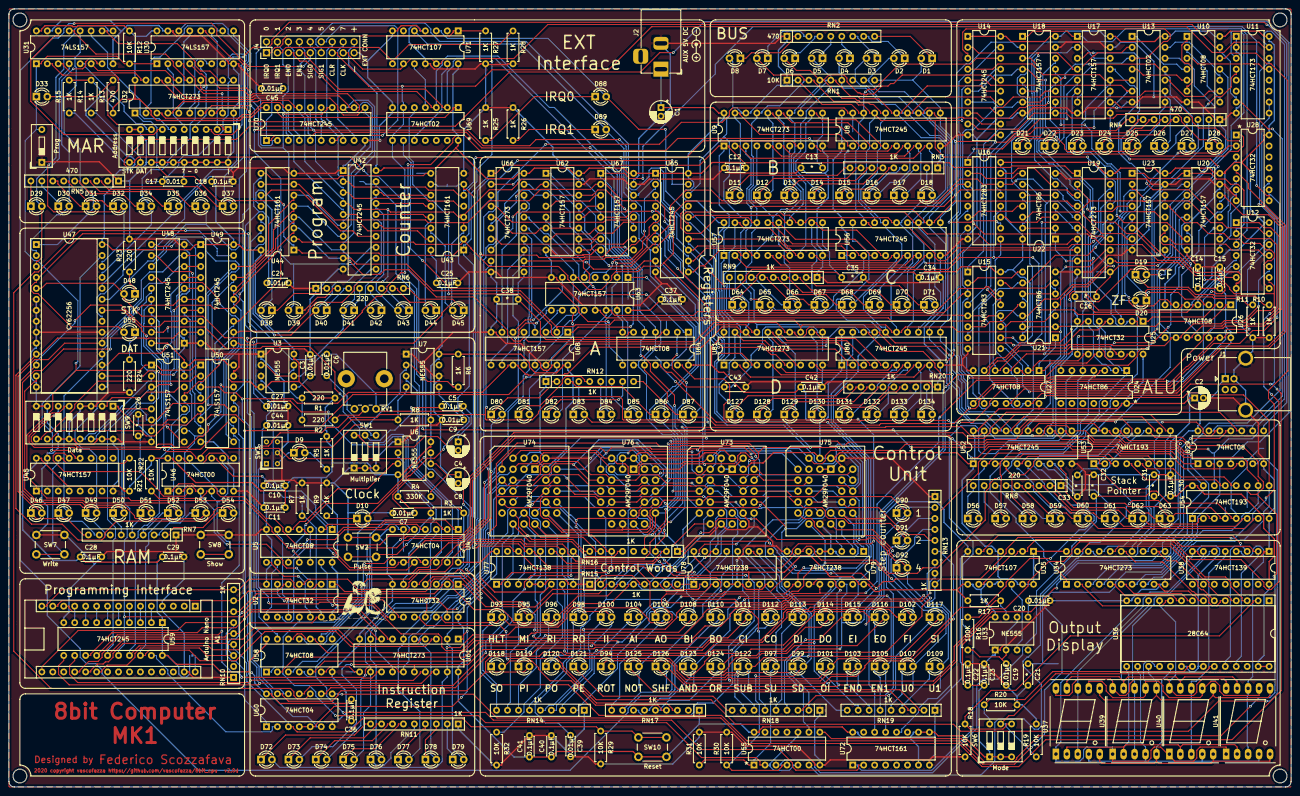
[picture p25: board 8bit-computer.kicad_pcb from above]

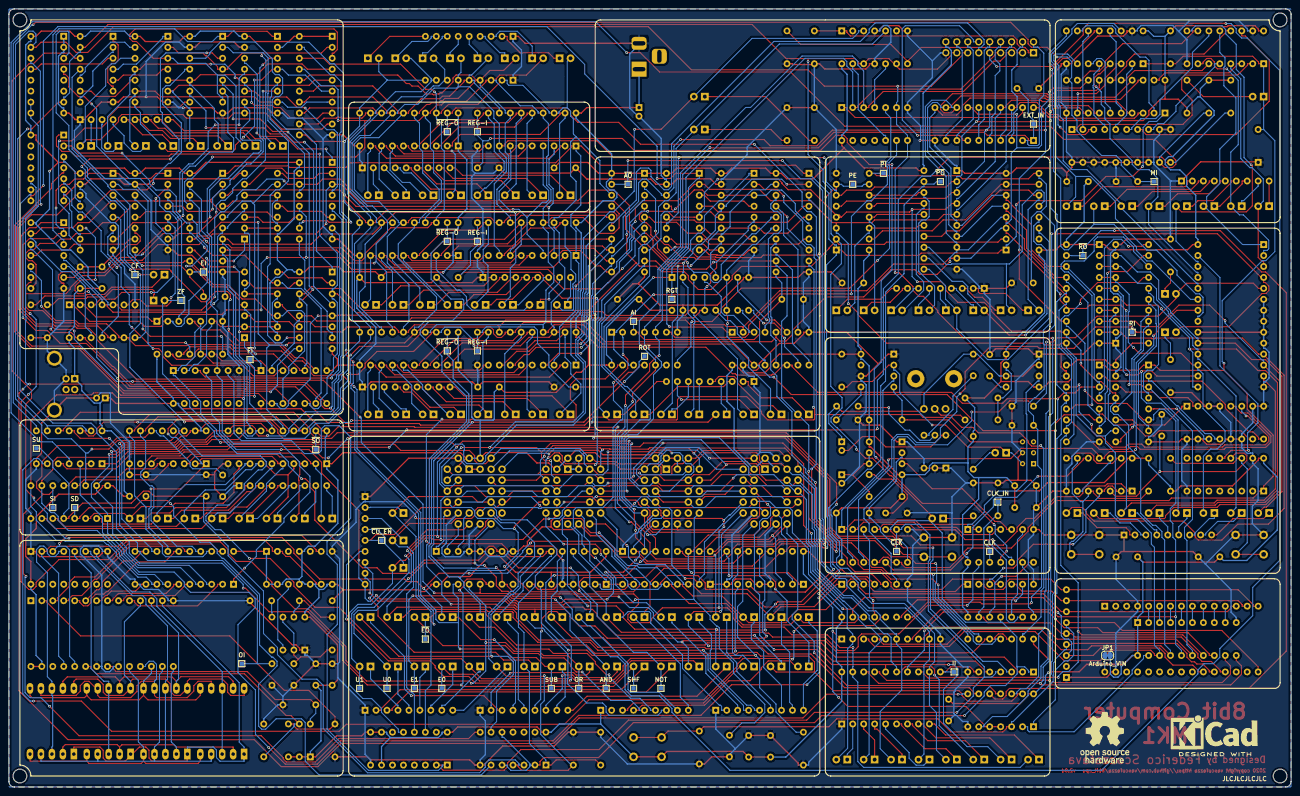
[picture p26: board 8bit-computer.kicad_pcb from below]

Board: 2 copper layers, 297.2 x 180.3 mm, 377 parts (44 on the bottom side), 516 nets.

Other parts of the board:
G0: LOGO; parrot
G1: Symbol_Barrel_Polarity
G2: KiCad-Logo2_8mm_SilkScreen
G3: OSHW-Logo_11.4x12mm_SilkScreen
MH0, MH1, MH2, MH3: MountingHole_3.2mm_M3

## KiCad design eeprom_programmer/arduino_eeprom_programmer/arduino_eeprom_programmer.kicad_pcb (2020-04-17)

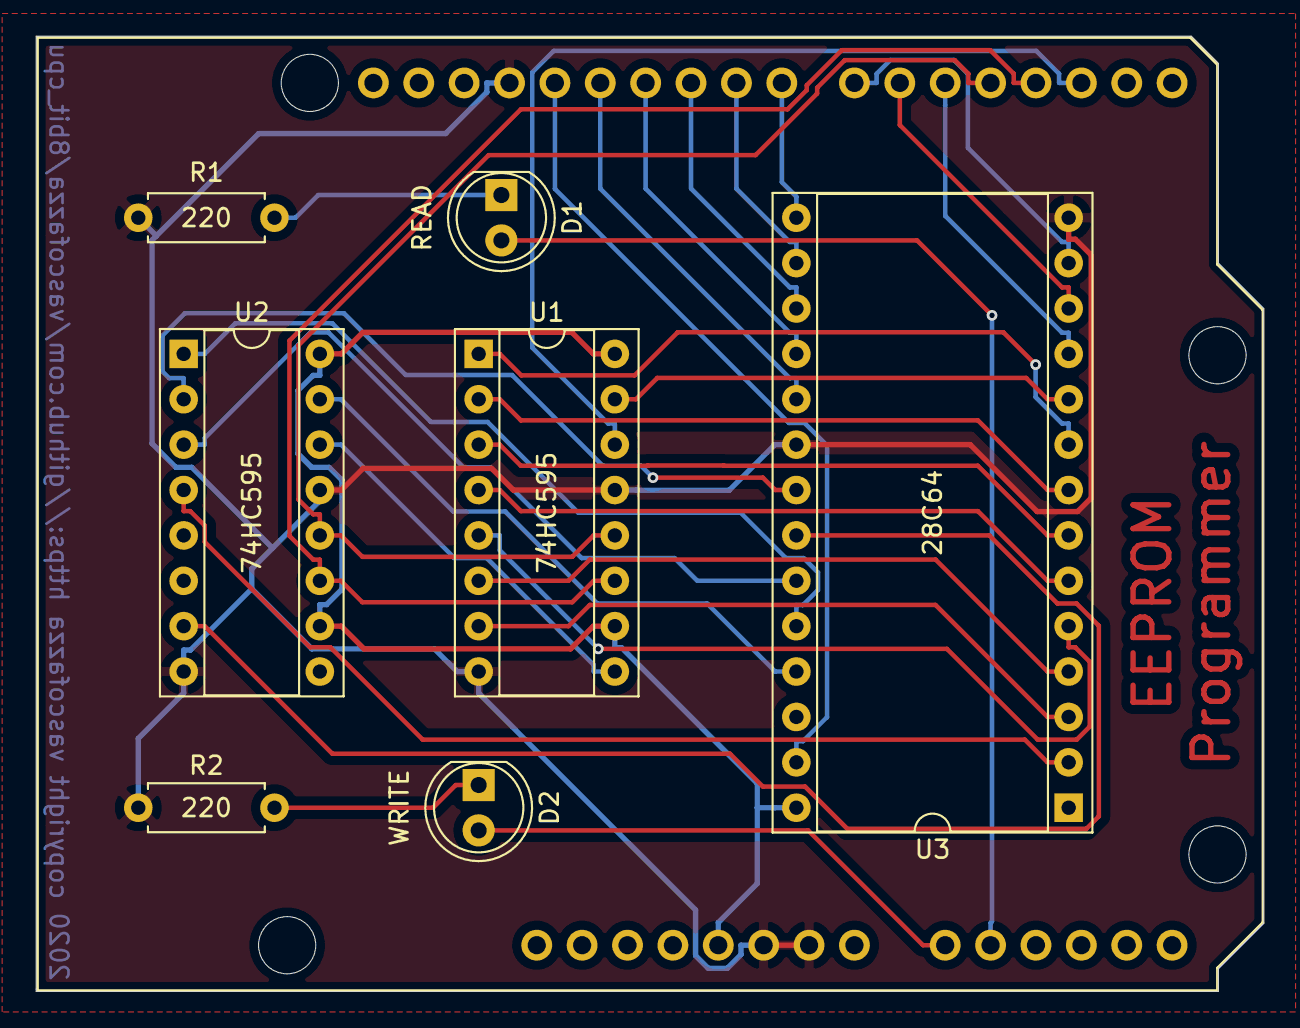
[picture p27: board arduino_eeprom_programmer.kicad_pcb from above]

Board: 2 copper layers, 68.7 x 53.5 mm, 8 parts (0 on the bottom side), 33 nets.

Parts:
D1: READ; LED_D5.0mm
D2: WRITE; LED_D5.0mm
R1, R2: 220; R_Axial_DIN0207_L6.3mm_D2.5mm_P7.62mm_Horizontal
U1, U2: 74HC595; DIP-16_W7.62mm_Socket
U3: 28C64; DIP-28_W15.24mm_Socket
XA1: Arduino_Uno_Shield

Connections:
GND: R1.1, R2.1, U1.8, U1.13, U2.8, U2.13, U3.14, U3.20, XA1.GND1, XA1.GND2, XA1.GND3
unnamed: D1.1, R1.2
unnamed: D1.2, XA1.A1
unnamed: D2.1, R2.2
unnamed: D2.2, XA1.A0
unnamed: U1.1, U3.9
unnamed: U1.2, U3.8
unnamed: U1.3, U3.7
unnamed: U1.4, U3.6
unnamed: U1.5, U3.5
unnamed: U1.6, U3.4
unnamed: U1.7, U3.3
unnamed: U1.9, U2.14
unnamed: U1.11, U2.11, XA1.D3
unnamed: U1.12, U2.12, XA1.D4
unnamed: U1.14, XA1.D2
unnamed: U1.15, U3.10
unnamed: U2.1, U3.24
unnamed: U2.2, U3.21
unnamed: U2.3, U3.23
unnamed: U2.4, U3.2
unnamed: U2.7, U3.22
unnamed: U2.15, U3.25
unnamed: U3.11, XA1.D5
unnamed: U3.12, XA1.D6
unnamed: U3.13, XA1.D7
unnamed: U3.15, XA1.D8
unnamed: U3.16, XA1.D9
unnamed: U3.17, XA1.D10
unnamed: U3.18, XA1.D11
unnamed: U3.19, XA1.D12
unnamed: U3.27, XA1.D13
VCC: U1.10, U1.16, U2.10, U2.16, U3.28, XA1.5V1

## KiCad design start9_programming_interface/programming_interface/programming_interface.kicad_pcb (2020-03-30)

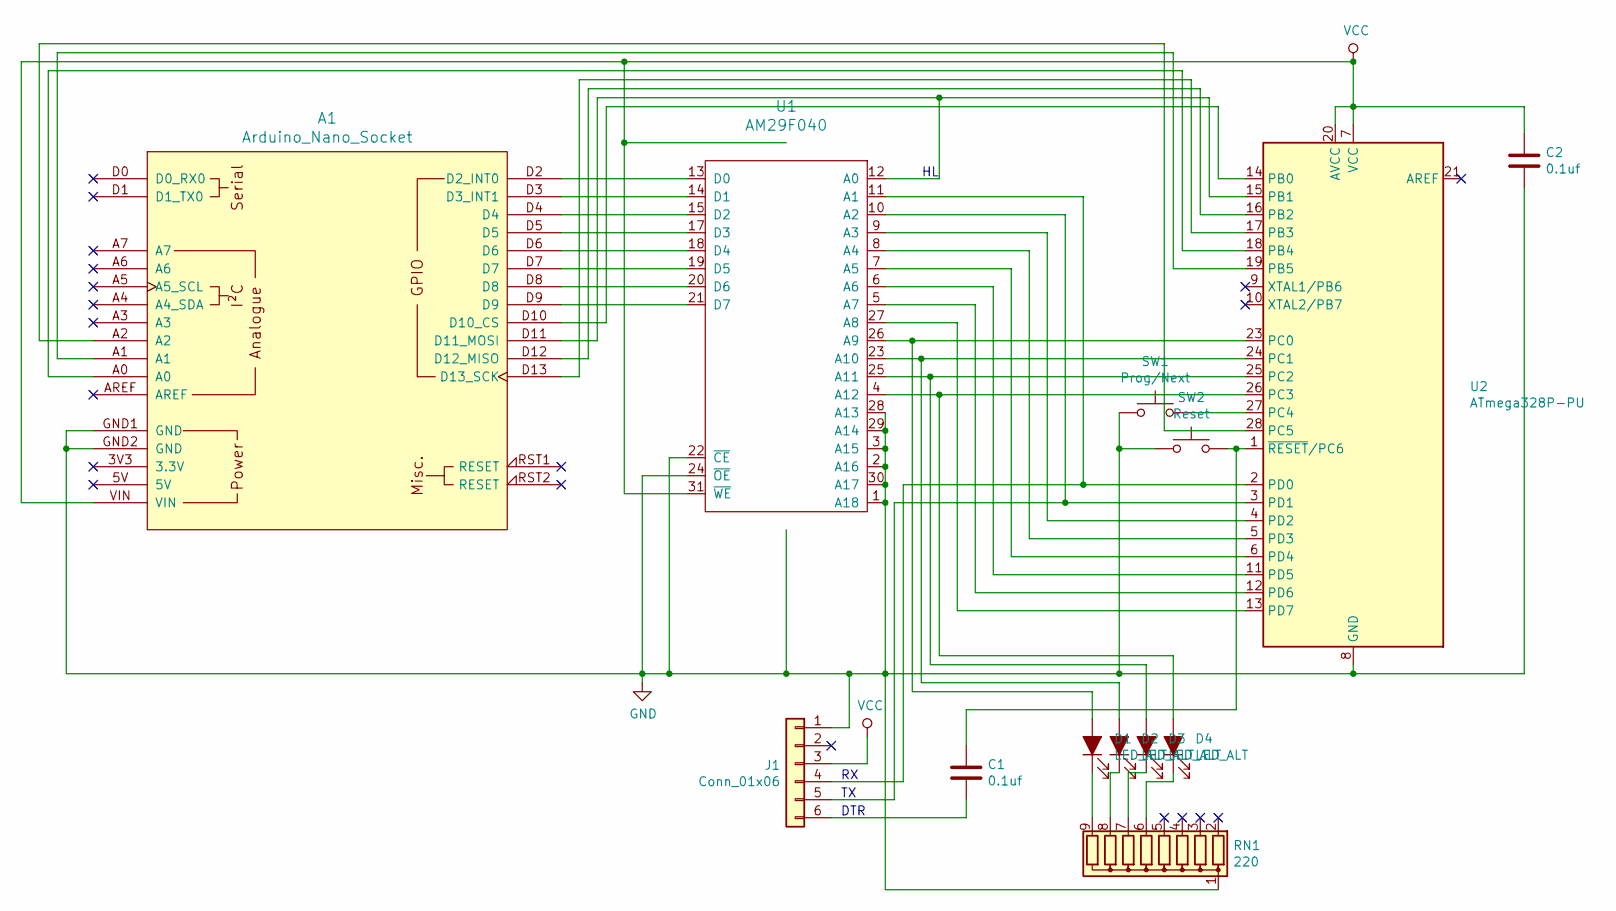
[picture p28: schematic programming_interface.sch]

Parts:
A1: Arduino_Nano_Socket
C1, C2: 0.1uf; C_Disc_D4.3mm_W1.9mm_P5.00mm
D1, D2, D3, D4: LED_ALT; LED_D3.0mm
J1: Conn_01x06; PinSocket_1x06_P2.54mm_Vertical
RN1: 220; R_Array_SIP9
SW1: Prog/Next; SW_PUSH_6mm_H5mm
SW2: Reset; SW_PUSH_6mm_H5mm
U1: AM29F040; PLCC-32_THT-Socket
U2: ATmega328P-PU; DIP-28_W7.62mm_Socket

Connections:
GND: A1.GND1 (GND), A1.GND2 (GND), C2.2, J1.1, RN1.1 (common), SW1.1, SW2.1, U1.1 (A18), U1.2 (A16), U1.3 (A15), U1.16 (GND), U1.22 (~CE~), U1.24 (~OE~), U1.28 (A13), U1.29 (A14), U1.30 (A17), U2.8 (GND), U2.22 (GND)
unnamed: A1.A0, U2.18 (PB4)
unnamed: A1.A1, U2.19 (PB5)
unnamed: A1.A2, U2.28 (PC5)
unnamed: A1.D2 (D2_INT0), U1.13 (D0)
unnamed: A1.D3 (D3_INT1), U1.14 (D1)
unnamed: A1.D4, U1.15 (D2)
unnamed: A1.D5, U1.17 (D3)
unnamed: A1.D6, U1.18 (D4)
unnamed: A1.D7, U1.19 (D5)
unnamed: A1.D8, U1.20 (D6)
unnamed: A1.D9, U1.21 (D7)
unnamed: A1.D10 (D10_CS), U2.14 (PB0)
unnamed: A1.D11 (D11_MOSI), U1.12 (A0), U2.15 (PB1)
unnamed: A1.D12 (D12_MISO), U2.16 (PB2)
unnamed: A1.D13 (D13_SCK), U2.17 (PB3)
unnamed: C1.1, SW2.2, U2.1 (~RESET~/PC6)
unnamed: C1.2, J1.6
unnamed: D1.1 (K), RN1.9 (R8)
unnamed: D1.2 (A), U1.26 (A9), U2.23 (PC0)
unnamed: D2.1 (K), RN1.8 (R7)
unnamed: D2.2 (A), U1.23 (A10), U2.24 (PC1)
unnamed: D3.1 (K), RN1.7 (R6)
unnamed: D3.2 (A), U1.25 (A11), U2.25 (PC2)
unnamed: D4.1 (K), RN1.6 (R5)
unnamed: D4.2 (A), U1.4 (A12), U2.26 (PC3)
unnamed: J1.4, U1.11 (A1), U2.2 (PD0)
unnamed: J1.5, U1.10 (A2), U2.3 (PD1)
unnamed: SW1.2, U2.27 (PC4)
unnamed: U1.5 (A7), U2.12 (PD6)
unnamed: U1.6 (A6), U2.11 (PD5)
unnamed: U1.7 (A5), U2.6 (PD4)
unnamed: U1.8 (A4), U2.5 (PD3)
unnamed: U1.9 (A3), U2.4 (PD2)
unnamed: U1.27 (A8), U2.13 (PD7)
VCC: A1.VIN, C2.1, J1.3, U1.31 (~WE~), U1.32 (VCC), U2.7 (VCC), U2.20 (AVCC)

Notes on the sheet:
DTR


Board: 2 copper layers, 53.3 x 48.3 mm, 15 parts (1 on the bottom side), 36 nets.

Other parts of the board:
S0: LOGO; trainer_tiny
S1: LOGO; parrot_small

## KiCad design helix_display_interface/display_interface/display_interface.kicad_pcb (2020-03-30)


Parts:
C1: 1uf; C_Disc_D4.3mm_W1.9mm_P5.00mm
J1: Display; PinSocket_2x07_P2.54mm_Vertical
J2: Prog; PinSocket_1x05_P2.54mm_Vertical
J3, J4: EXT BUS; PinHeader_2x09_P2.54mm_Vertical
JP1: Display Contrast; SolderJumper-3_P1.3mm_Bridged12_RoundedPad1.0x1.5mm_NumberL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
JP2: EN; SolderJumper-3_P1.3mm_Open_RoundedPad1.0x1.5mm_NumberLabels
JP3: IRQ; SolderJumper-3_P1.3mm_Open_RoundedPad1.0x1.5mm_NumberLabels
RV1: Contrast; Potentiometer_Piher_PT-10-V10_Vertical
U1: ATmega328-PU; DIP-28_W7.62mm_Socket

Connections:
GND: C1.2, J1.2, J1.5, J2.5, J3.17, J4.17, JP1.3 (B), RV1.3, U1.8 (GND), U1.22 (GND)
unnamed: J1.3, JP1.2 (C)
unnamed: J1.4, U1.18 (PB4)
unnamed: J1.6, U1.17 (PB3)
unnamed: J1.11, U1.11 (PD5)
unnamed: J1.12, U1.6 (PD4)
unnamed: J1.13, U1.5 (PD3)
unnamed: J1.14, U1.4 (PD2)
unnamed: J2.1, U1.3 (PD1)
unnamed: J2.2, U1.2 (PD0)
unnamed: J2.3, U1.1 (~RESET~/PC6)
unnamed: J3.1, J4.1, JP3.1 (A)
unnamed: J3.2, J4.2, U1.23 (PC0)
unnamed: J3.3, J4.3, JP3.3 (B)
unnamed: J3.4, J4.4, U1.24 (PC1)
unnamed: J3.5, J4.5, JP2.1 (A)
unnamed: J3.6, J4.6, U1.25 (PC2)
unnamed: J3.7, J4.7, JP2.3 (B)
unnamed: J3.8, J4.8, U1.26 (PC3)
unnamed: J3.9, J4.9, U1.16 (PB2)
unnamed: J3.10, J4.10, U1.27 (PC4)
unnamed: J3.11, J4.11, U1.19 (PB5)
unnamed: J3.12, J4.12, U1.28 (PC5)
unnamed: J3.13, J4.13, U1.9 (XTAL1/PB6)
unnamed: J3.14, J4.14, U1.12 (PD6)
unnamed: J3.15, J4.15, U1.10 (XTAL2/PB7)
unnamed: J3.16, J4.16, U1.13 (PD7)
unnamed: JP1.1 (A), RV1.2
unnamed: JP2.2 (C), U1.15 (PB1)
unnamed: JP3.2 (C), U1.14 (PB0)
VCC: C1.1, J1.1, J2.4, J3.18, J4.18, RV1.1, U1.7 (VCC), U1.20 (AVCC)

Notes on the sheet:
VCC
GND
R/W
DB0
DB1
DB2
DB3
DB4
DB5
DB6
DB7
D12
D11
RST
IRQ0
IRQ1
EN0
EN1
SIG0
SIG1
CLR
CLK



Board: 2 copper layers, 96.5 x 55.2 mm, 16 parts (4 on the bottom side), 31 nets.

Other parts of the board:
M0, M1, M2, M3: MountingHole_2mm
S0: LOGO; parrot
S1: LOGO; helix_small

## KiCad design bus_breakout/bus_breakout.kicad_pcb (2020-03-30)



Board: 2 copper layers, 57.1 x 41.9 mm, 4 parts (3 on the bottom side), 18 nets.

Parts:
J1: Signals; PinHeader_1x08_P2.54mm_Vertical
J2: BUS; PinHeader_1x08_P2.54mm_Vertical
J3: Power; PinHeader_1x02_P2.54mm_Vertical
J4: Conn; PinHeader_2x09_P2.54mm_Vertical

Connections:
unnamed: J1.1, J4.1
unnamed: J1.2, J4.3
unnamed: J1.3, J4.5
unnamed: J1.4, J4.7
unnamed: J1.5, J4.9
unnamed: J1.6, J4.11
unnamed: J1.7, J4.13
unnamed: J1.8, J4.15
unnamed: J2.1, J4.2
unnamed: J2.2, J4.4
unnamed: J2.3, J4.6
unnamed: J2.4, J4.8
unnamed: J2.5, J4.10
unnamed: J2.6, J4.12
unnamed: J2.7, J4.14
unnamed: J2.8, J4.16
unnamed: J3.1, J4.18
unnamed: J3.2, J4.17

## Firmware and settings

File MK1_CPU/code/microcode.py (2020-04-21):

from copy import deepcopy
import argparse
from io import BytesIO
import sys
from functools import reduce

_VERSION = "2.0d"

HLT = 0b10000000000000000000000000000000  # Halt clock
STK = 0b01000000000000000000000000000000  # Memory Stack address space
PE  = 0b00100000000000000000000000000000  # Program counter enable
AI  = 0b00010000000000000000000000000000  # A register in
BI  = 0b00001000000000000000000000000000  # B register in
CI  = 0b00011000000000000000000000000000  # C register in
DI  = 0b00000100000000000000000000000000  # D register in
SI  = 0b00010100000000000000000000000000  # StakPointer register in
EI  = 0b00001100000000000000000000000000  # ALU register in
PI  = 0b00011100000000000000000000000000  # Program counter in
MI  = 0b00000010000000000000000000000000  # Memory address register in
RI  = 0b00000001000000000000000000000000  # RAM data in
II  = 0b00000000100000000000000000000000  # Instruction register in
OI  = 0b00000000010000000000000000000000  # Output register in
XI  = 0b00000000001000000000000000000000  # External Interface in
AO  = 0b00000000000100000000000000000000  # A register out
BO  = 0b00000000000010000000000000000000  # B register out
CO  = 0b00000000000110000000000000000000  # C register out
DO  = 0b00000000000001000000000000000000  # D register out
PO  = 0b00000000000101000000000000000000  # Program Counter out
SO  = 0b00000000000011000000000000000000  # StackPointer register out
EO  = 0b00000000000111000000000000000000  # ALU register out
RO  = 0b00000000000000100000000000000000  # RAM data out
_IO = 0b00000000000000010000000000000000  # Instruction register out
SUB = 0b00000000000000001000000000000000  # ALU subtract mode
OR  = 0b00000000000000000100000000000000  # ALU OR mode
AND = 0b00000000000000001100000000000000  # ALU AND mode
SHF = 0b00000000000000000010000000000000  # REG A SHIFT mode
ROT = 0b00000000000000001010000000000000  # REG A ROTATE mode
RGT = 0b00000000000000000000000000010000  # Right SHIFT or ROTATE
NOT = 0b00000000000000001110000000000000  # ALU NOT mode
FI  = 0b00000000000000000001000000000000  # Flags in
SU  = 0b00000000000000000000100000000000  # StackPointer count UP
SD  = 0b00000000000000000000010000000000  # StackPointer count DOWN
U0  = 0b00000000000000000000001000000000  # X-USR sig 0
U1  = 0b00000000000000000000000100000000  # X-USR sig 1
E0  = 0b00000000000000000000000010000000  # X-Enable 0
E1  = 0b00000000000000000000000001000000  # X-Enable 1
HL  = 0b00000000000000000000000000100000  # HL address mode
RST = 0b00000000000000000000000000000001  # Reset step counter

signals = {HLT : "HLT", STK: "STK", PE: "PE" , AI: "AI", BI: "BI", CI: "CI", DI: "DI", SI: "SI", EI: "EI", PI: "PI", MI: "MI", RI: "RI", II: "II", OI: "OI", XI: "XI", AO: "AO", BO: "BO", CO: "CO", DO: "DO", PO: "PO", SO: "SO", EO: "EO", RO: "RO", _IO: "IO", SUB: "SUB", OR: "OR", AND: "AND", SHF: "SHF", ROT: "SHF", RGT: "RGT", NOT: "NOT", FI: "FI", SU: "SU", SD: "SD", U0: "U0", U1: "U1", E0: "E0", E1: "E1", HL: "HL", RST: "RST"}

register_map = {0: ('$a', AI, AO),
                1: ('$b', BI, BO),
                2: ('$c', CI, CO),
                3: ('$d', DI, DO),
                4: ('$sp', SI, SO),
                5: ('$pc', PI, PO),
                6: ('$out', OI, 0),
                7: ('imm', 0, RO)}

alu_op_map = {0: ('add', 0), 1: ('sub', SUB), 2: ('or', OR), 3: ('and', AND)}

ucode_template = dict()

#MOV
#move $a $b
#nop = move $a $a
#jmp = move imm $pc
#--- specials ---
#exw 0 0 = move $a imm
#exw 0 1 = move $b imm
#exw 1 0 = move $c imm
#exw 1 1 = move $d imm
#je0 = move $sp imm
#je1 = move $pc imm
#jcf = move $spp imm
#jzf = move $imm imm
ucode_template.update({
    (0b00 << 6) + (first << 3) + second : ('move %s, %s'%(register_map[first][0], register_map[second][0]), [MI|PO, RO|II|PE, register_map[first][2]|register_map[second][1], RST, RST, RST, RST, RST] if first != 7 else
    [MI|PO, RO|II|PE, PO|MI, PE|register_map[first][2]|register_map[second][1], RST, RST, RST, RST], (second == 7 or first == 7))
    for first in range(8) for second in range(8)})

#LOAD
#loadi $a imm
#load $a [$b]
#pop $a = load $a [$spp]
#ret = load $pc [$spp]
#-- specials --
#exr 0 = load imm $a
#exr 1 = load imm $b
# 3: ('not', NOT), 4: ('sll', SHF), 5: ('srl', SHF|RGT), 6: ('rll', ROT), 7: ('rlr', ROT|RGT)
#not = load imm $c
#sll = load imm $d
#srl = load imm $sp
#rll = load imm $pc
#rlr = load imm $spp
#out = load imm imm

#6: ('$spp', SO|SD, SO|SU)
ucode_template.update({
    (0b01 << 6) + (first << 3) + second : ('load %s, [%s]'%(register_map[first][0], register_map[second][0]),
    [MI|PO, RO|II|PE, SU,register_map[second][2]|MI, STK|register_map[first][1]|RO, (PE if first == 5 else RST), RST, RST] if second == 4 else
    [MI|PO, RO|II|PE, register_map[second][2]|MI, HL|register_map[first][1]|RO, RST, RST, RST, RST], (second == 7 or first == 7))
    for first in range(7) for second in range(7)})

ucode_template.update({
    (0b01 << 6) + (first << 3) + second : ('load %s, [%s]'%(register_map[first][0], register_map[second][0]),
    [MI|PO, RO|II|PE, PO|MI|SU,PE|register_map[second][2]|MI, STK|register_map[first][1]|RO, (PE if first == 5 else RST), RST, RST] if second == 4 else
    [MI|PO, RO|II|PE, PO|MI, PE|register_map[second][2]|MI, HL|register_map[first][1]|RO, RST, RST, RST], (second == 7 or first == 7))
    for first in range(7) for second in range(7,8)})

#STORE
#store $a imm
#store $a [$b]
#push $a = store $a [$spp]
#jal imm = stor $pc, $spp
#-- specials --
#op_i x $b = 10 - 11 - op - $b -> immediate operation on $a, result on $b
#hlt = store $a [$sp]

#6: ('$spp', SO|SD, SO|SU)
ucode_template.update({
    (0b10 << 6) + (first << 3) + second : ('stor %s, [%s]'%(register_map[first][0], register_map[second][0]), [MI|PO, RO|II|PE, register_map[second][2]|MI, (STK|SD if second == 4 else HL)|register_map[first][2]|RI, RST, RST, RST, RST], (second == 7 or first == 7))
    for first in range(6) for second in range(7)})

ucode_template.update({
    (0b10 << 6) + (first << 3) + second : ('stor %s, [%s]'%(register_map[first][0], register_map[second][0]), [MI|PO, RO|II|PE, PO|MI, PE|register_map[second][2]|MI, (STK|SD if second == 4 else HL)|register_map[first][2]|RI, RST, RST, RST], (second == 7 or first == 7))
    for first in range(6) for second in range(7,8)})

ucode_template.update({
    (0b1011 << 4) + (op << 2) + second : ('%s imm, %s'%(alu_op_map[op][0], register_map[second][0]), [MI|PO, RO|II|PE,  PO|MI,  PE|RO|EI, register_map[second][1]|EO|FI|alu_op_map[op][1], RST, RST, RST], True)
    for second in range(4) for op in range(4)})

ucode_template[0b01111111] = ('hlt', [MI|PO, RO|II|PE,  HLT, RST, RST, RST, RST, RST], False)
#ALU
#op $a $b
#11 - op - rs - rd
ucode_template.update({
    (0b11 << 6) + (op << 4) + (first << 2) + second : ('%s %s, %s'%(alu_op_map[op][0], register_map[first][0], register_map[second][0]), [MI|PO, RO|II|PE, register_map[first][2]|EI, register_map[second][1]|EO|FI|alu_op_map[op][1], RST, RST, RST, RST], False)
    for first in range(4) for second in range(4) for op in range(4)})

ucode_template[0b01111000] = ('exr 0', [MI|PO, RO|II|PE, XI|E0|AI, RST, RST, RST, RST, RST], False)
ucode_template[0b01111001] = ('exr 1', [MI|PO, RO|II|PE, XI|E1|AI,  RST, RST, RST, RST, RST], False)

ucode_template[0b01111010] = ('not', [MI|PO, RO|II|PE,  AO|EI, AI, NOT|EO|AI, RST, RST, RST], False)
ucode_template[0b01111011] = ('sll', [MI|PO, RO|II|PE,  SHF|AI, RST,     RST, RST, RST, RST], False)
ucode_template[0b01111100] = ('slr', [MI|PO, RO|II|PE,  SHF|RGT|AI, RST, RST, RST, RST, RST], False)
ucode_template[0b01111101] = ('rll', [MI|PO, RO|II|PE,  ROT|AI, RST,     RST, RST, RST, RST], False)
ucode_template[0b01111110] = ('rlr', [MI|PO, RO|II|PE,  ROT|RGT|AI, RST, RST, RST, RST, RST], False)

ucode_template[0b00000111] = ('exw 0 0', [MI|PO, RO|II|PE, AO|E0, RST, RST, RST, RST, RST], False)
ucode_template[0b00001111] = ('exw 0 1', [MI|PO, RO|II|PE, AO|E0|U0, RST, RST, RST, RST, RST], False)
ucode_template[0b10001110] = ('exw 0 2', [MI|PO, RO|II|PE, AO|E0|U1, RST, RST, RST, RST, RST], False)
ucode_template[0b10010110] = ('exw 0 3', [MI|PO, RO|II|PE, AO|E0|U1|U0, RST, RST, RST, RST, RST], False)
ucode_template[0b00010111] = ('exw 1 0', [MI|PO, RO|II|PE, AO|E1, RST, RST, RST, RST, RST], False)
ucode_template[0b00011111] = ('exw 1 1', [MI|PO, RO|II|PE, AO|E1|U0, RST, RST, RST, RST, RST], False)
ucode_template[0b10011110] = ('exw 1 2', [MI|PO, RO|II|PE, AO|E1|U1, RST, RST, RST, RST, RST], False)
ucode_template[0b10100110] = ('exw 1 3', [MI|PO, RO|II|PE, AO|E1|U1|U0, RST, RST, RST, RST, RST], False)

ucode_template[0b10101110] = ('cmp $b', [MI|PO, RO|II|PE, BO|EI, SUB|FI, RST, RST, RST, RST], False)
ucode_template[0b01000110] = ('cmp $c', [MI|PO, RO|II|PE, CO|EI, SUB|FI, RST, RST, RST, RST], False)
ucode_template[0b01001110] = ('cmp $d', [MI|PO, RO|II|PE, DO|EI, SUB|FI, RST, RST, RST, RST], False)
ucode_template[0b10000110] = ('cmp imm', [MI|PO, RO|II|PE,  PO|MI, PE|RO|EI, SUB|FI, RST, RST, RST], False)

ucode_template[0b00100111] = ('je0', [MI|PO, RO|II|PE, PE, RST, RST, RST, RST, RST], False)
ucode_template[0b00101111] = ('je1', [MI|PO, RO|II|PE, PE, RST, RST, RST, RST, RST], False)
ucode_template[0b00110111] = ('jcf', [MI|PO, RO|II|PE, PE, RST, RST, RST, RST, RST], False)
ucode_template[0b00111111] = ('jzf', [MI|PO, RO|II|PE, PE, RST, RST, RST, RST, RST], False)

def checkUCode():
    for op, code in ucode_template.items():
        if len(code) < 3 or len(code[1]) != 8:
            print("Error:", str(op), len(code), len(code[1]))

instruction_decode = {y[0]:x for x,y in ucode_template.items()}

#TODO
ucode_template[instruction_decode['stor $pc, [$sp]']][1][4:6] = [PO|MI, RO|register_map[5][1]]

ucode = list(range(16)) #flag instruction step
def initUCode():

    FLAGS_IRQ00IRQ10Z0C0 = 0
    FLAGS_IRQ00IRQ10Z0C1 = 1
    FLAGS_IRQ00IRQ10Z1C0 = 2
    FLAGS_IRQ00IRQ10Z1C1 = 3
    FLAGS_IRQ01IRQ10Z0C0 = 4
    FLAGS_IRQ01IRQ10Z0C1 = 5
    FLAGS_IRQ01IRQ10Z1C0 = 6
    FLAGS_IRQ01IRQ10Z1C1 = 7
    FLAGS_IRQ00IRQ11Z0C0 = 8
    FLAGS_IRQ00IRQ11Z0C1 = 9
    FLAGS_IRQ00IRQ11Z1C0 = 10
    FLAGS_IRQ00IRQ11Z1C1 = 11
    FLAGS_IRQ01IRQ11Z0C0 = 12
    FLAGS_IRQ01IRQ11Z0C1 = 13
    FLAGS_IRQ01IRQ11Z1C0 = 14
    FLAGS_IRQ01IRQ11Z1C1 = 15

    #print(instruction_decode.keys())

    J0 = instruction_decode['je0']#je0 = move $sp imm
    J1 = instruction_decode['je1']#je1 = move $pc imm
    JC = instruction_decode['jcf']#jcf = move $spp imm
    JZ = instruction_decode['jzf']#jzf = move $imm imm

    #ZF = 0, CF = 0, IRQ0 = 0, IRQ1 = 0
    ucode[FLAGS_IRQ00IRQ10Z0C0] = deepcopy(ucode_template)

    #ZF = 0, CF = 0, IRQ0 = 0, IRQ1 = 1
    ucode[FLAGS_IRQ00IRQ11Z0C0] =  deepcopy(ucode_template)
    ucode[FLAGS_IRQ00IRQ11Z0C0][J1][1][2:4] = [PO|MI, RO|PI];

    #ZF = 0, CF = 0, IRQ0 = 1, IRQ1 = 0
    ucode[FLAGS_IRQ01IRQ10Z0C0] =  deepcopy(ucode_template)
    ucode[FLAGS_IRQ01IRQ10Z0C0][J0][1][2:4] = [PO|MI, RO|PI];

    #ZF = 0, CF = 0, IRQ0 = 1, IRQ1 = 1
    ucode[FLAGS_IRQ01IRQ11Z0C0] =  deepcopy(ucode_template)
    ucode[FLAGS_IRQ01IRQ11Z0C0][J0][1][2:4] = [PO|MI, RO|PI];
    ucode[FLAGS_IRQ01IRQ11Z0C0][J1][1][2:4] = [PO|MI, RO|PI];

    #ZF = 0, CF = 1, IRQ0 = 0, IRQ1 = 0
    ucode[FLAGS_IRQ00IRQ10Z0C1] =  deepcopy(ucode_template)
    ucode[FLAGS_IRQ00IRQ10Z0C1][JC][1][2:4] = [PO|MI, RO|PI];

    #ZF = 0, CF = 1, IRQ0 = 0, IRQ1 = 1
    ucode[FLAGS_IRQ00IRQ11Z0C1] =  deepcopy(ucode_template)
    ucode[FLAGS_IRQ00IRQ11Z0C1][JC][1][2:4] = [PO|MI, RO|PI];
    ucode[FLAGS_IRQ00IRQ11Z0C1][J1][1][2:4] = [PO|MI, RO|PI];

    #ZF = 0, CF = 1, IRQ0 = 1, IRQ1 = 0
    ucode[FLAGS_IRQ01IRQ10Z0C1] =  deepcopy(ucode_template)
    ucode[FLAGS_IRQ01IRQ10Z0C1][JC][1][2:4] = [PO|MI, RO|PI];
    ucode[FLAGS_IRQ01IRQ10Z0C1][J0][1][2:4] = [PO|MI, RO|PI];

    #ZF = 0, CF = 1, IRQ0 = 1, IRQ1 = 1
    ucode[FLAGS_IRQ01IRQ11Z0C1] =  deepcopy(ucode_template)
    ucode[FLAGS_IRQ01IRQ11Z0C1][JC][1][2:4] = [PO|MI, RO|PI];
    ucode[FLAGS_IRQ01IRQ11Z0C1][J0][1][2:4] = [PO|MI, RO|PI];
    ucode[FLAGS_IRQ01IRQ11Z0C1][J1][1][2:4] = [PO|MI, RO|PI];

    #ZF = 1, CF = 0, IRQ0 = 0, IRQ1 = 0
    ucode[FLAGS_IRQ00IRQ10Z1C0] =  deepcopy(ucode_template)
    ucode[FLAGS_IRQ00IRQ10Z1C0][JZ][1][2:4] = [PO|MI, RO|PI];

    #ZF = 1, CF = 0, IRQ0 = 0, IRQ1 = 1
    ucode[FLAGS_IRQ00IRQ11Z1C0] =  deepcopy(ucode_template)
    ucode[FLAGS_IRQ00IRQ11Z1C0][JZ][1][2:4] = [PO|MI, RO|PI];
    ucode[FLAGS_IRQ00IRQ11Z1C0][J1][1][2:4] = [PO|MI, RO|PI];

    #ZF = 1, CF = 0, IRQ0 = 1, IRQ1 = 0
    ucode[FLAGS_IRQ01IRQ10Z1C0] =  deepcopy(ucode_template)
    ucode[FLAGS_IRQ01IRQ10Z1C0][JZ][1][2:4] = [PO|MI, RO|PI];
    ucode[FLAGS_IRQ01IRQ10Z1C0][J0][1][2:4] = [PO|MI, RO|PI];

    #ZF = 1, CF = 0, IRQ0 = 1, IRQ1 = 1
    ucode[FLAGS_IRQ01IRQ11Z1C0] =  deepcopy(ucode_template)
    ucode[FLAGS_IRQ01IRQ11Z1C0][JZ][1][2:4] = [PO|MI, RO|PI];
    ucode[FLAGS_IRQ01IRQ11Z1C0][J0][1][2:4] = [PO|MI, RO|PI];
    ucode[FLAGS_IRQ01IRQ11Z1C0][J1][1][2:4] = [PO|MI, RO|PI];

    #ZF = 1, CF = 1, IRQ0 = 0, IRQ1 = 0
    ucode[FLAGS_IRQ00IRQ10Z1C1] =  deepcopy(ucode_template)
    ucode[FLAGS_IRQ00IRQ10Z1C1][JC][1][2:4] = [PO|MI, RO|PI];
    ucode[FLAGS_IRQ00IRQ10Z1C1][JZ][1][2:4] = [PO|MI, RO|PI];

    #ZF = 1, CF = 1, IRQ0 = 0, IRQ1 = 1
    ucode[FLAGS_IRQ00IRQ11Z1C1] =  deepcopy(ucode_template)
    ucode[FLAGS_IRQ00IRQ11Z1C1][JC][1][2:4] = [PO|MI, RO|PI];
    ucode[FLAGS_IRQ00IRQ11Z1C1][JZ][1][2:4] = [PO|MI, RO|PI];
    ucode[FLAGS_IRQ00IRQ11Z1C1][J1][1][2:4] = [PO|MI, RO|PI];

    #ZF = 1, CF = 1, IRQ0 = 1, IRQ1 = 0
    ucode[FLAGS_IRQ01IRQ10Z1C1] =  deepcopy(ucode_template)
    ucode[FLAGS_IRQ01IRQ10Z1C1][JC][1][2:4] = [PO|MI, RO|PI];
    ucode[FLAGS_IRQ01IRQ10Z1C1][JZ][1][2:4] = [PO|MI, RO|PI];
    ucode[FLAGS_IRQ01IRQ10Z1C1][J0][1][2:4] = [PO|MI, RO|PI];

    #ZF = 1, CF = 1, IRQ0 = 1, IRQ1 = 1
    ucode[FLAGS_IRQ01IRQ11Z1C1] =  deepcopy(ucode_template)
    ucode[FLAGS_IRQ01IRQ11Z1C1][JC][1][2:4] = [PO|MI, RO|PI];
    ucode[FLAGS_IRQ01IRQ11Z1C1][JZ][1][2:4] = [PO|MI, RO|PI];
    ucode[FLAGS_IRQ01IRQ11Z1C1][J0][1][2:4] = [PO|MI, RO|PI];
    ucode[FLAGS_IRQ01IRQ11Z1C1][J1][1][2:4] = [PO|MI, RO|PI];


checkUCode()
initUCode()

def byte(value):
    return (value).to_bytes(1, 'big', signed=False)

def write(address, data, out):
    out.seek(address)
    data = data & 255
    out.write(data.to_bytes(1, 'big'))

def generate_microcode():
    #Program data bytes
    print("Generating microcode...")

    with open("microcode.bin", 'wb') as out:
        #Program the 8 high-order bits of microcode into the first 128 bytes of EEPROM
        for address in range(131072):
            flags       = (address & 0b00111100000000000) >> 11
            byte_sel    = (address & 0b11000000000000000) >> 15
            instruction = (address & 0b00000011111111000) >> 3
            step        = (address & 0b00000000000000111)

            if instruction not in ucode_template or len(ucode[flags][instruction][1]) == 0:
                print ("unused op-code: $s"%bin(instruction))
                instruction = instruction_decode['move $a, $a']

            if byte_sel == 0:
                write(address, ucode[flags][instruction][1][step] >> 24, out)
            elif byte_sel == 1:
                write(address, ucode[flags][instruction][1][step] >> 16, out)
            elif byte_sel == 2:
                write(address, ucode[flags][instruction][1][step] >> 8, out)
            elif byte_sel == 3:
                write(address, ucode[flags][instruction][1][step] >> 0, out)
            else:
                write(address, 0, out)

        def get_checked_signals(k, i):
            return [sorted_signals[x] for x in range(i) if k & sorted_signals[x] == sorted_signals[x] and reduce(lambda a, b: a | b, sorted_signals[:x], 0) != k]

        with open("microcode.txt", 'w') as out:
            sorted_signals = sorted(signals.keys(), reverse=True, key=lambda x: (int(bin(x).replace('0b', '').replace('0', ' ').strip().replace(' ', '0')), -1 if any([x & i == x for i in signals.keys() if i != x]) else 1))
            for mnemonic, opcode in sorted(instruction_decode.items()):
                print(mnemonic, format(opcode, '08b'), "[" + ',\t'.join(['|'.join([signals[y] for i, y in enumerate(sorted_signals) if x & y == y and x & reduce(lambda a, b: a | b, get_checked_signals(x, i), 0) != x]) for x in ucode_template[opcode][1]]) + "]", sep='\t', file=out)

        print("done")

def assemble_binary(input_file):
    address_table = dict()
    b = bytes()
    buffer = BytesIO(b)
    written_bytes = 0
    with open(input_file, 'r') as f:
        address = 0
        line_num = 0
        for line in f:
            line_num += 1
            if ";" in line:
                line = line[:line.find(';')]
            line = line.strip()
            if len(line) == 0 or line.startswith(";"):
                continue
            components = line.split(" ")
            curr_address = address
            if ":" in line:
                components = line.split(":")
                value = components[0].strip()
                if value.isnumeric():
                    curr_address = int(value)*2
                else:
                    if value in address_table:
                        #print(value, address_table[value])
                        for location in address_table[value]:
                            buffer.seek(location)
                            buffer.write(byte(curr_address // 2))
                    address_table[value] = curr_address // 2
                    if len(components[1].strip()) == 0:
                        continue
                    address += 2
                components = components[1].strip().split(" ")
            else:
                address += 2
            mnemonic_value = components[0].strip()
            if mnemonic_value == ".data":
                buffer.seek(curr_address)
                data = components[1:]
                for value in data:
                    written_bytes += buffer.write(byte(int(value.strip())))
                    written_bytes += buffer.write(byte(0))
                    address += 2
                continue

            if not mnemonic_value.isnumeric() and mnemonic_value not in instruction_decode:
                print("Error @ line %d: instruction not recognized: '%s'"%(line_num, mnemonic_value))
                sys.exit(1)
            instruction = int(mnemonic_value) if mnemonic_value.isnumeric() else instruction_decode[mnemonic_value]
            if not mnemonic_value.isnumeric() and len(components) == 1 and ucode_template[instruction][2]:
                print("Error @ line [%d] %s : missing parameter for instruction: %s" % (line_num, line, mnemonic_value))
                sys.exit(1)
            elif not mnemonic_value.isnumeric() and len(components) > 1 and not ucode_template[instruction][2]:
                print("Warning @ line [%d] %s : unused parameter for instruction '%s': %s" % (line_num, line, mnemonic_value, components[1]))
            value = components[1].strip() if len(components) > 1 else '0'
            if not value.isnumeric():
                if value in address_table and type(address_table[value]) is not list:
                    value = address_table[value]
                else:
                    if not value in address_table:
                        address_table[value] = list()
                    address_table[value].append(curr_address+1)
                    value = '0'
            argument = byte(int(value))
            buffer.seek(curr_address)
            written_bytes += buffer.write(byte(instruction))
            written_bytes += buffer.write(argument)

    if any([type(x) is list for x in address_table.values()]):
        print("Linking error")
        print([x for x,y in address_table.items() if type(y) is list])
        sys.exit(1)
    print("Used %d bytes (%.1f%%) out of 512 bytes."%(written_bytes, (written_bytes/512*100)))
    return buffer.getvalue()

if __name__ == "__main__":

    parser = argparse.ArgumentParser(description='Assembler for MK1 computer.')
    parser.add_argument('-i', '--input', metavar='input', type=str,
                        help='input file name')
    parser.add_argument('-o', '--output', metavar='output', type=str,
                        help='output binary file name')

    args = parser.parse_args()

    if not args.input:
        generate_microcode()
        sys.exit(0)

    binary = assemble_binary(args.input)

    out_file_name = args.output or args.input[:args.input.rfind('.')]+".bin"

    with open(out_file_name, 'wb') as out:
        out.write(binary)

    print("%s generated (%d bytes)."%(out_file_name, len(binary)))

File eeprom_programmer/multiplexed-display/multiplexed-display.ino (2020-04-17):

#define SHIFT_DATA 2
#define SHIFT_CLK 3
#define SHIFT_LATCH 4
#define EEPROM_D0 5
#define EEPROM_D7 12
#define WRITE_EN 13
#define READ_LED A1
#define WRITE_LED A0

/*
   Output the address bits and outputEnable signal using shift registers.
*/
void setAddress(int address, bool outputEnable) {
  shiftOut(SHIFT_DATA, SHIFT_CLK, MSBFIRST, (address >> 8) | (outputEnable ? 0x00 : 0x80));
  shiftOut(SHIFT_DATA, SHIFT_CLK, MSBFIRST, address);

  digitalWrite(SHIFT_LATCH, LOW);
  digitalWrite(SHIFT_LATCH, HIGH);
  digitalWrite(SHIFT_LATCH, LOW);
}


/*
   Read a byte from the EEPROM at the specified address.
*/
byte readEEPROM(int address) {
  digitalWrite(READ_LED, HIGH);
  for (int pin = EEPROM_D0; pin <= EEPROM_D7; pin += 1) {
    pinMode(pin, INPUT);
  }
  setAddress(address, /*outputEnable*/ true);

  byte data = 0;
  for (int pin = EEPROM_D7; pin >= EEPROM_D0; pin -= 1) {
    data = (data << 1) + digitalRead(pin);
  }
  digitalWrite(READ_LED, LOW);
  return data;
}


/*
   Write a byte to the EEPROM at the specified address.
*/
void writeEEPROM(int address, byte data) {
  digitalWrite(WRITE_LED, HIGH);
  setAddress(address, /*outputEnable*/ false);
  for (int pin = EEPROM_D0; pin <= EEPROM_D7; pin += 1) {
    pinMode(pin, OUTPUT);
  }

  for (int pin = EEPROM_D0; pin <= EEPROM_D7; pin += 1) {
    digitalWrite(pin, data & 1);
    data = data >> 1;
  }
  digitalWrite(WRITE_EN, LOW);
  delayMicroseconds(1);
  digitalWrite(WRITE_EN, HIGH);
  delay(10);
  digitalWrite(WRITE_LED, LOW);
}


/*
   Read the contents of the EEPROM and print them to the serial monitor.
*/
void printContents() {
  for (int base = 0; base <= 255; base += 16) {
    byte data[16];
    for (int offset = 0; offset <= 15; offset += 1) {
      data[offset] = readEEPROM(base + offset);
    }

    char buf[80];
    sprintf(buf, "%03x:  %02x %02x %02x %02x %02x %02x %02x %02x   %02x %02x %02x %02x %02x %02x %02x %02x",
            base, data[0], data[1], data[2], data[3], data[4], data[5], data[6], data[7],
            data[8], data[9], data[10], data[11], data[12], data[13], data[14], data[15]);

    Serial.println(buf);
  }
}


void setup() {
  // put your setup code here, to run once:
  pinMode(SHIFT_DATA, OUTPUT);
  pinMode(SHIFT_CLK, OUTPUT);
  pinMode(SHIFT_LATCH, OUTPUT);
  digitalWrite(WRITE_EN, HIGH);
  pinMode(WRITE_EN, OUTPUT);
  Serial.begin(57600);


  // Bit patterns for the digits 0..F
  byte digits[] = { 0x7e, 0x30, 0x6d, 0x79, 0x33, 0x5b, 0x5f, 0x70, 0x7f, 0x7b, 0x77, 0x1f, 0x4e, 0x3d, 0x4f, 0x47 };
  byte lower[] = {0x7D, 0x1F, 0x0D, 0x3D, 0x6f, 0x47, 0x7B, 0x17, 0x10, 0x38, 0x17, 0x06, 0x55, 0x15, 0x1D, 0x67, 0x73, 0x05, 0x5B, 0x0F, 0x1C, 0x23, 0x2B, 0x25, 0x33, 0x6D };
  byte upper[] = {0x77, 0x7F, 0x4E, 0x7E, 0x4F, 0x47, 0x5E, 0x37, 0x30, 0x3C, 0x37, 0x0E, 0x55, 0x15, 0x7E, 0x67, 0x73, 0x77, 0x5B, 0x46, 0x3E, 0x27, 0x3F, 0x25, 0x3B, 0x6D };
  byte space = 0x00;

  Serial.println("Programming ones place");
  for (int value = 0; value <= 255; value += 1) {
    writeEEPROM(value, digits[value % 10]);
  }
  for (int value = 0; value <= 255; value += 1) {
    if (readEEPROM(value) != digits[value % 10])
      Serial.println("Write Error!");
  }

  Serial.println("Programming tens place");
  for (int value = 0; value <= 255; value += 1) {
    writeEEPROM(value + 256, digits[(value / 10) % 10]);
  }
  for (int value = 0; value <= 255; value += 1) {
    if (readEEPROM(value + 256) != digits[(value / 10) % 10])
      Serial.println("Write Error!");
  }

  Serial.println("Programming hundreds place");
  for (int value = 0; value <= 255; value += 1) {
    writeEEPROM(value + 512, digits[(value / 100) % 10]);
  }
  for (int value = 0; value <= 255; value += 1) {
    if (readEEPROM(value + 512) != digits[(value / 100) % 10])
      Serial.println("Write Error!");
  }

  Serial.println("Programming sign");
  for (int value = 0; value <= 255; value += 1) {
    writeEEPROM(value + 768, 0);
  }
  for (int value = 0; value <= 255; value += 1) {
    if (readEEPROM(value + 768) != 0)
      Serial.println("Write Error!");
  }

  Serial.println("Programming ones place (twos complement)");
  for (int value = -128; value <= 127; value += 1) {
    writeEEPROM((byte)value + 1024, digits[abs(value) % 10]);
  }
  for (int value = -128; value <= 127; value += 1) {
    if (readEEPROM((byte)value + 1024) != digits[abs(value) % 10])
      Serial.println("Write Error!");
  }

  Serial.println("Programming tens place (twos complement)");
  for (int value = -128; value <= 127; value += 1) {
    writeEEPROM((byte)value + 1280, digits[abs(value / 10) % 10]);
  }
  for (int value = -128; value <= 127; value += 1) {
    if (readEEPROM((byte)value + 1280) != digits[abs(value / 10) % 10])
      Serial.println("Write Error!");
  }

  Serial.println("Programming hundreds place (twos complement)");
  for (int value = -128; value <= 127; value += 1) {
    writeEEPROM((byte)value + 1536, digits[abs(value / 100) % 10]);
  }
  for (int value = -128; value <= 127; value += 1) {
    if (readEEPROM((byte)value + 1536) != digits[abs(value / 100) % 10])
      Serial.println("Write Error!");
  }

  Serial.println("Programming sign (twos complement)");
  for (int value = -128; value <= 127; value += 1) {
    if (value < 0) {
      writeEEPROM((byte)value + 1792, 0x01);
    } else {
      writeEEPROM((byte)value + 1792, 0);
    }
  }

  Serial.println("Programming ones place (HEX)");
  for (int value = 0; value <= 255; value += 1) {
    writeEEPROM(value + 2048, digits[value % 16]);
  }
  for (int value = 0; value <= 255; value += 1) {
    if (readEEPROM(value + 2048) != digits[value % 16])
      Serial.println("Write Error!");
  }

  Serial.println("Programming tens place (HEX)");
  for (int value = 0; value <= 255; value += 1) {
    writeEEPROM(value + 2048 + 256, digits[(value / 16) % 16]);
  }
  for (int value = 0; value <= 255; value += 1) {
    if (readEEPROM(value + 2048 + 256) != digits[(value / 16) % 16])
      Serial.println("Write Error!");
  }

  Serial.println("Programming hundreds place (HEX)");
  for (int value = 0; value <= 255; value += 1) {
    writeEEPROM(value + 2048 + 512, 0);
  }
  for (int value = 0; value <= 255; value += 1) {
    if (readEEPROM(value + 2048 + 512) != 0)
      Serial.println("Write Error!");
  }

  Serial.println("Programming sign (HEX)");
  for (int value = 0; value <= 255; value += 1) {
    writeEEPROM(value + 2048 + 768, 0);
  }
  for (int value = 0; value <= 255; value += 1) {
    if (readEEPROM(value + 2048 + 768) != 0)
      Serial.println("Write Error!");
  }
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

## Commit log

2020-03-30 bus_breakout schematics
    [bus_breakout.kicad_pcb, bus_breakout.sch]
2020-03-30 MK1 V1 project
    [8bit-computer.kicad_pcb, 8bit-computer.sch, PC-interface.sch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]
2020-03-30 helix display interface project
    [display_interface.kicad_pcb, display_interface.sch]
2020-03-30 start9 programming interface project
    [programming_interface.kicad_pcb, programming_interface.sch]
2020-03-30 version 2.0
    [8bit-computer.kicad_pcb, 8bit-computer.sch, PC-interface.sch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]
2020-04-04 pdf schematics
2020-04-10 resistor label update
    [8bit-computer.kicad_pcb, 8bit-computer.sch]
2020-04-17 2.0b hardware revision
    [8bit-computer.sch, b-register.sch, control.sch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]
2020-04-17 eeprom programmer
    [arduino_eeprom_programmer.kicad_pcb, arduino_eeprom_programmer.sch]
2020-04-17 cpu-definition, assembler and example programs
2020-04-21 assembler cpu definition
2020-04-21 revision 2.0d
    [8bit-computer.kicad_pcb, 8bit-computer.sch, PC-interface.sch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]
2020-04-21 schematics revision 2.0d
2020-04-23 PCB tracks revision
    [8bit-computer.kicad_pcb, 8bit-computer.sch, ext_interface.sch]
2020-04-26 schematics cleanup
    [8bit-computer.sch, ext_interface.sch]

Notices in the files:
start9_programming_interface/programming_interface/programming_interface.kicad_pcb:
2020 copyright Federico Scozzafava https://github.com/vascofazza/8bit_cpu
